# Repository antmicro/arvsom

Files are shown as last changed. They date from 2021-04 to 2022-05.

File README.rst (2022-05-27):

=========================================
ARVSOM - Antmicro RISC-V System on Module
=========================================

Copyright (c) 2021 `Antmicro <https://www.antmicro.com>`_



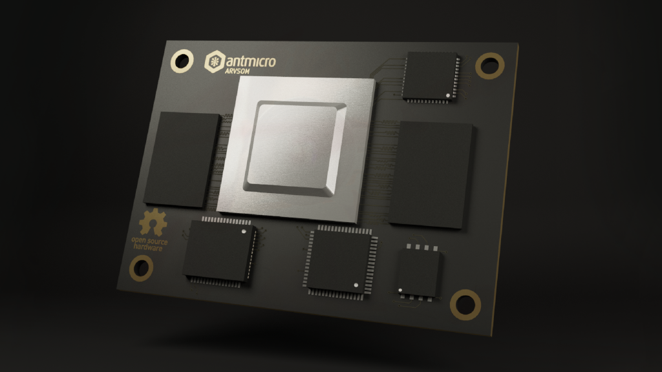
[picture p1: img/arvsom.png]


Overview
--------

This repository contains open hardware design files for ARVSOM - Antmicro RISC-V System on Module (SoM) based on the StarFive 71x0 SoC.
The design is made in KiCad and currently in progress.

Repository structure
--------------------

The main repository directory contains KiCad PCB project files, a LICENSE and README.
The remaining files are stored in the following directories:

* ``lib`` - contains the component libraries
* ``img`` - contains graphics for this README

Key Features
------------

* StarFive 71x0 SoC (7100 in the current revision until 7110 becomes available)
* 2x DF40 board-to-board connectors for baseboard integration
* HDMI
* Gigabit Ethernet
* USB 3.0
* 2x MIPI CSI-2 (2 lanes each)
* I2C
* MIPI DSI (4 lanes)
* SD/SDIO/eMMC
* 26 GPIOs
* 32MB QSPI NOR Flash memory
* 8GB LPDDR4 (2x 4GB)

License
=======

`Apache-2.0 <LICENSE>`_

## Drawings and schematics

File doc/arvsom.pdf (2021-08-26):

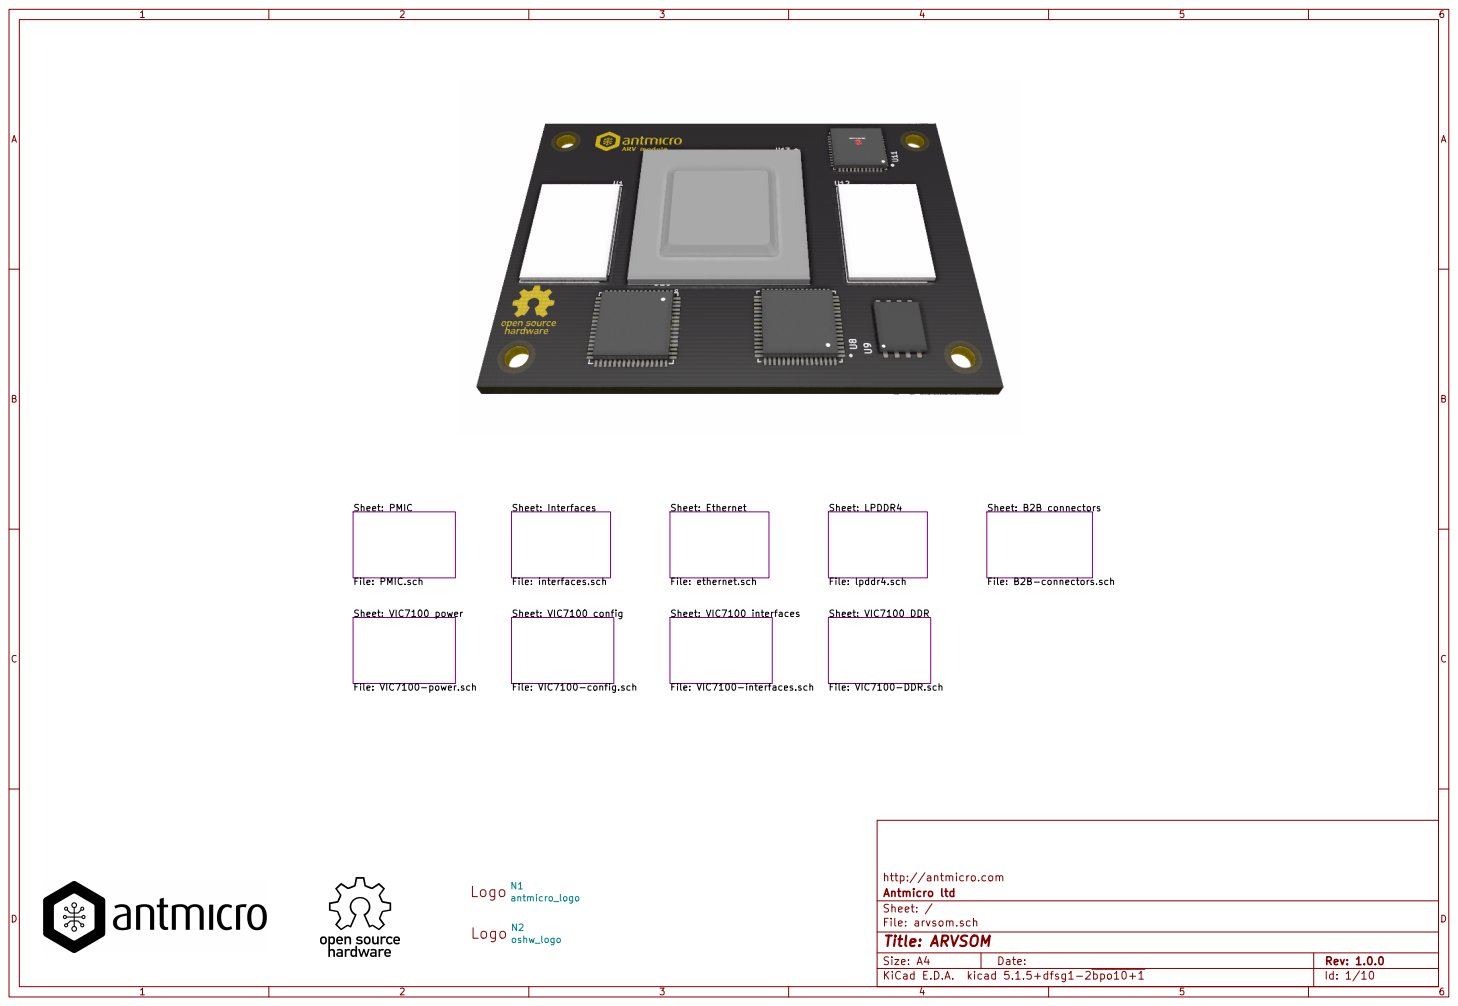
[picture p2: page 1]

http://antmicro.com
File: arvsom.sch Sheet: / Antmicro ltd

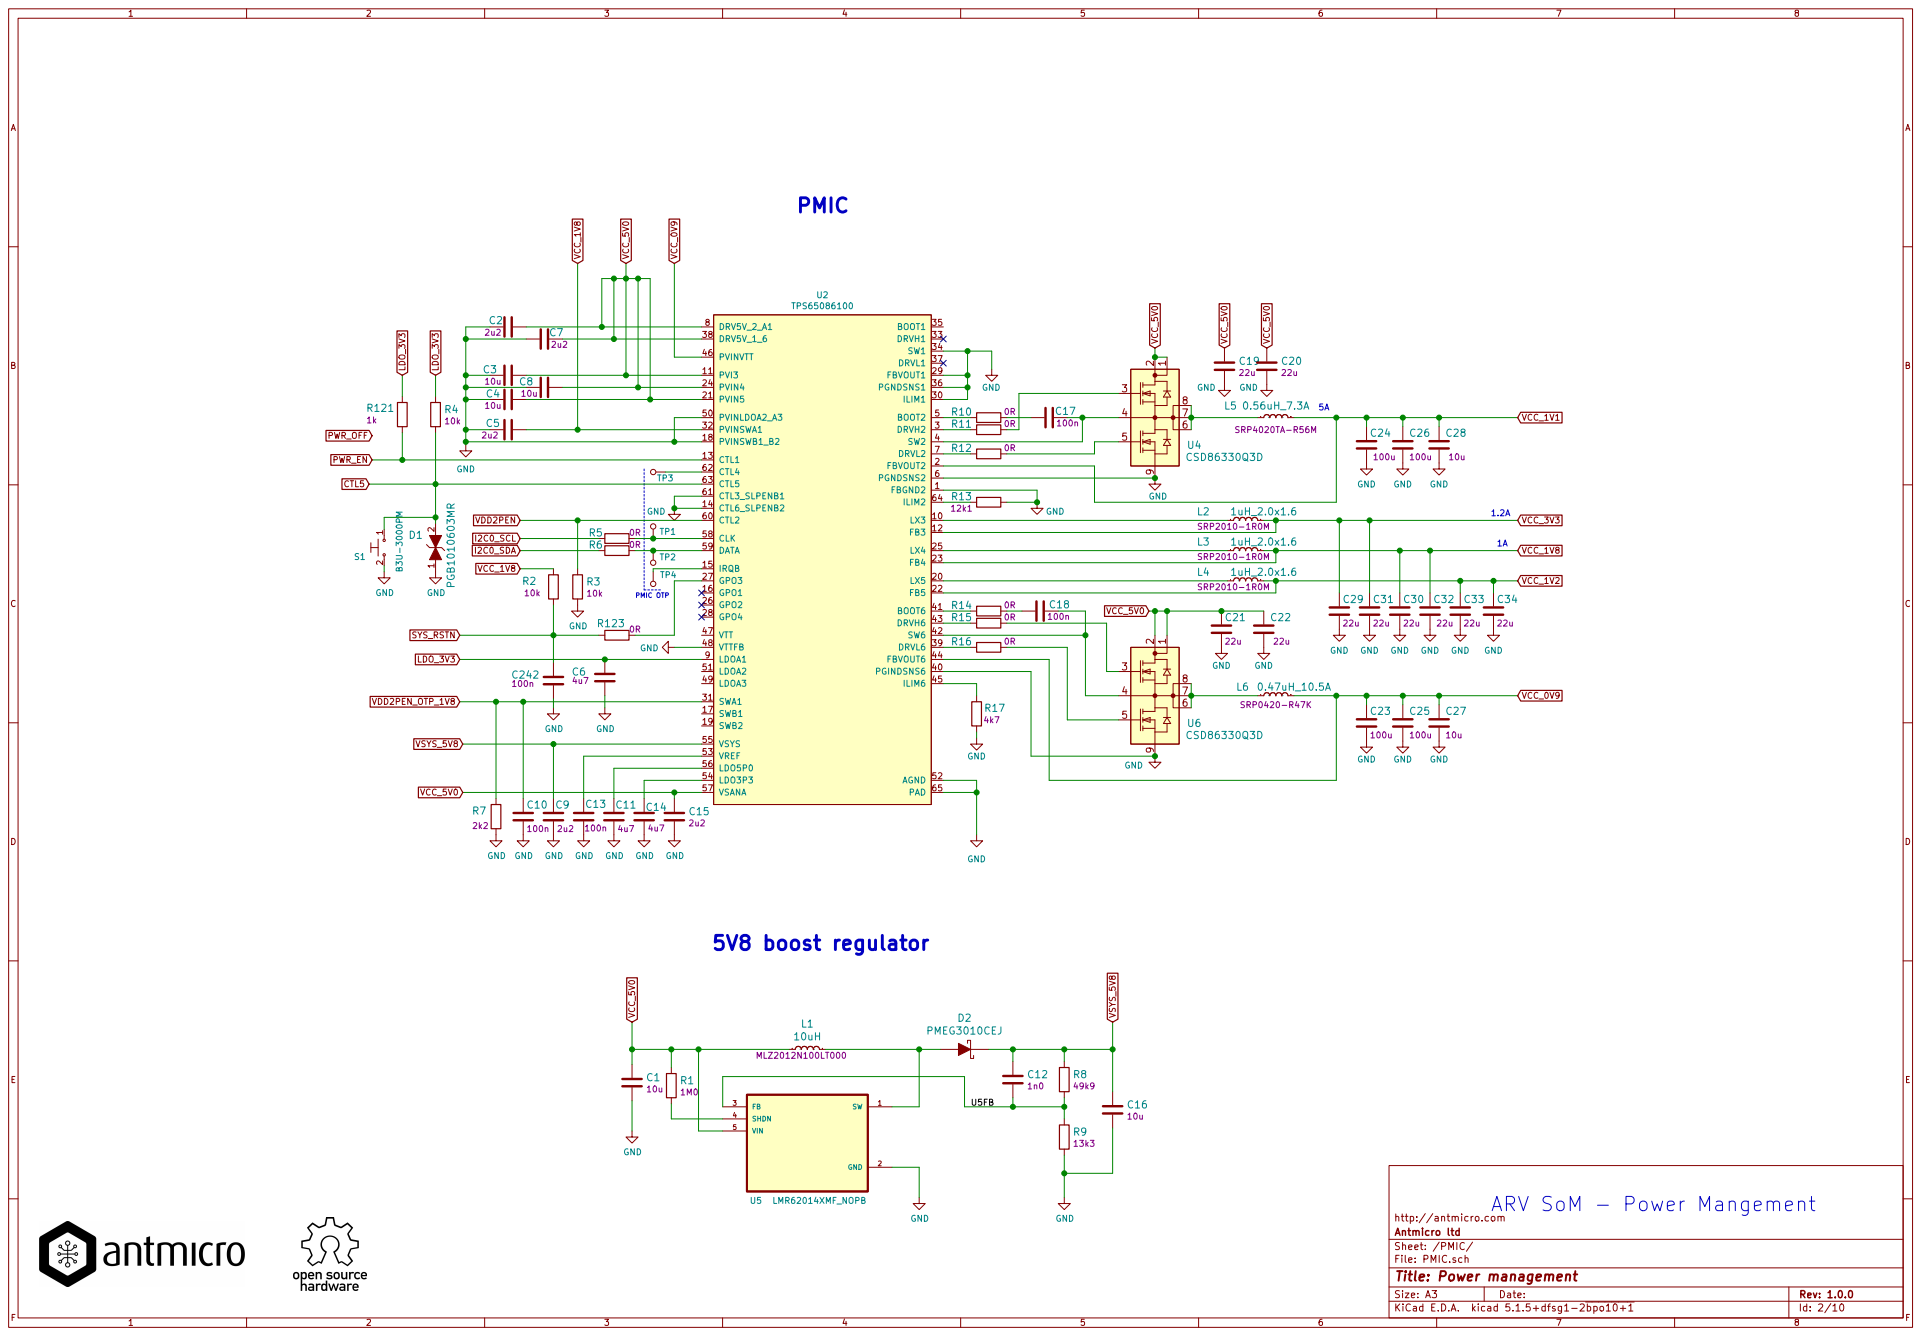
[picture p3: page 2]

10u | C8
C4 | 10u

http://antmicro.com
Id: 2/10 Title: Power management File: PMIC.sch Sheet: /PMIC/ Antmicro ltd

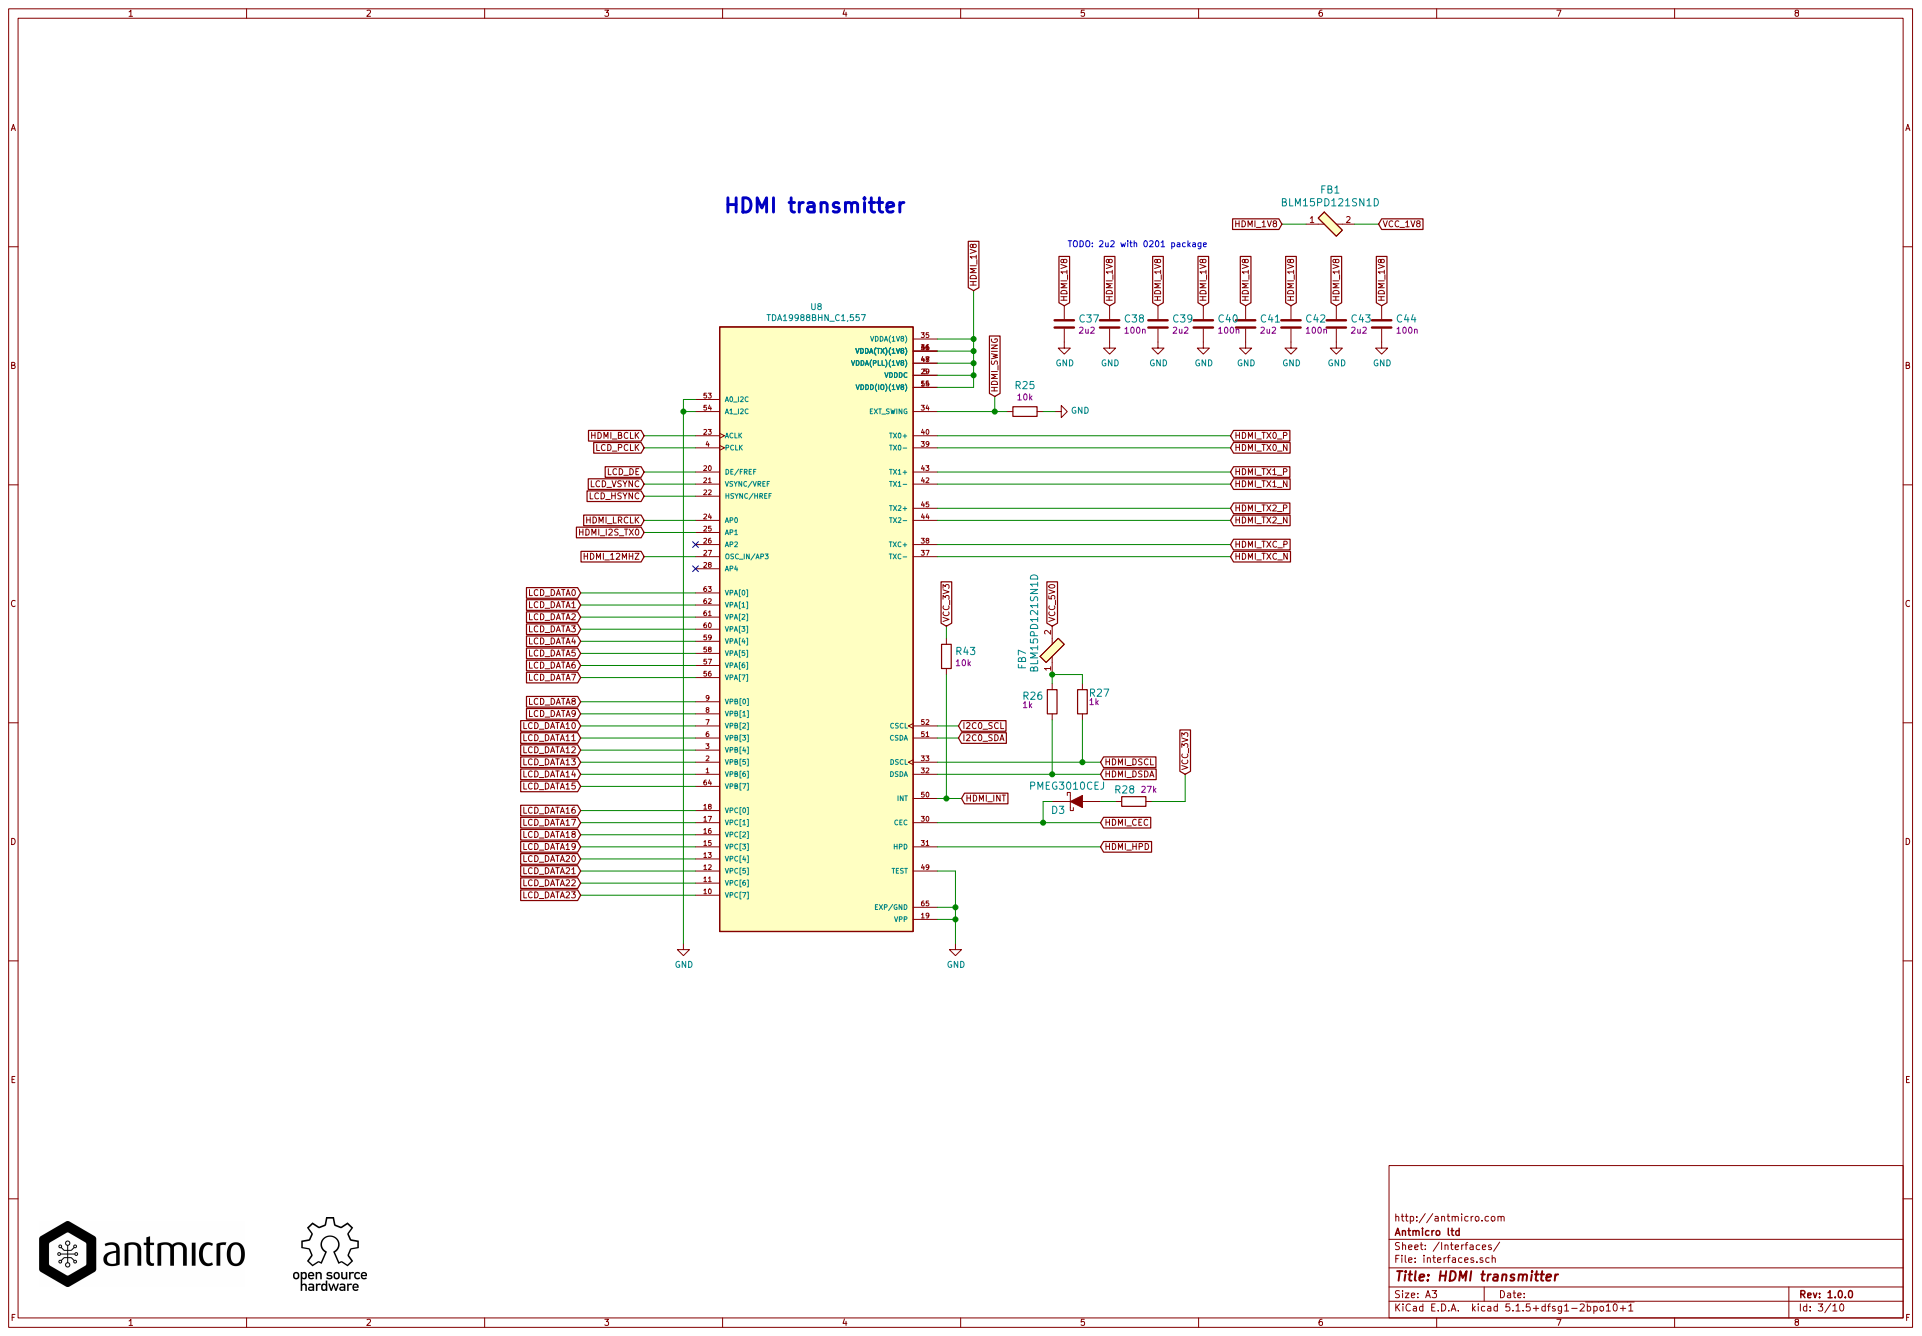
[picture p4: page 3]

http://antmicro.com
Id: 3/10 Title: HDMI transmitter File: interfaces.sch Sheet: /Interfaces/ Antmicro ltd

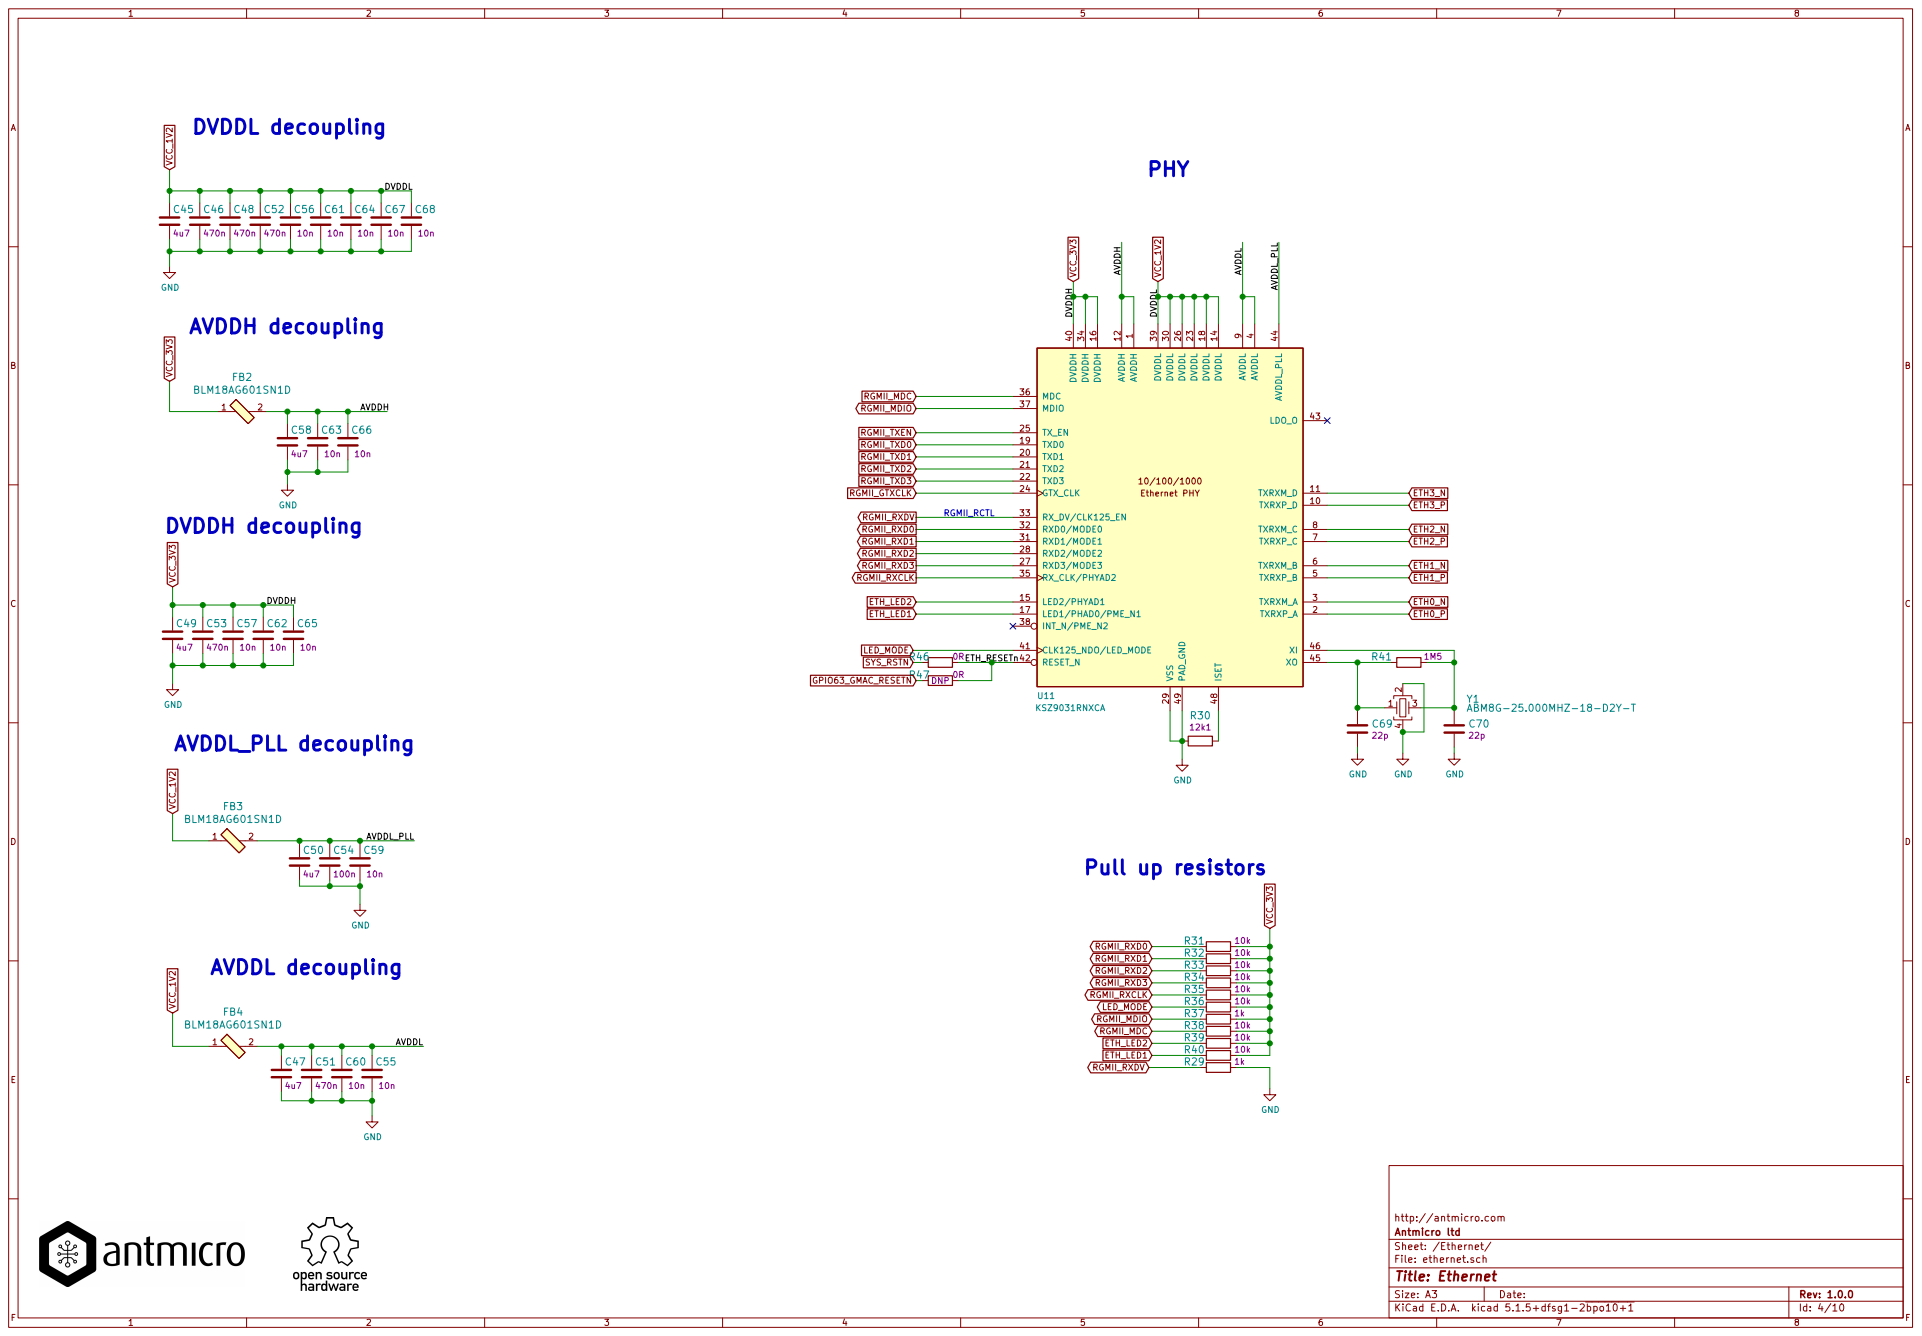
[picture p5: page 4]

http://antmicro.com
Id: 4/10 Title: Ethernet File: ethernet.sch Sheet: /Ethernet/ Antmicro ltd

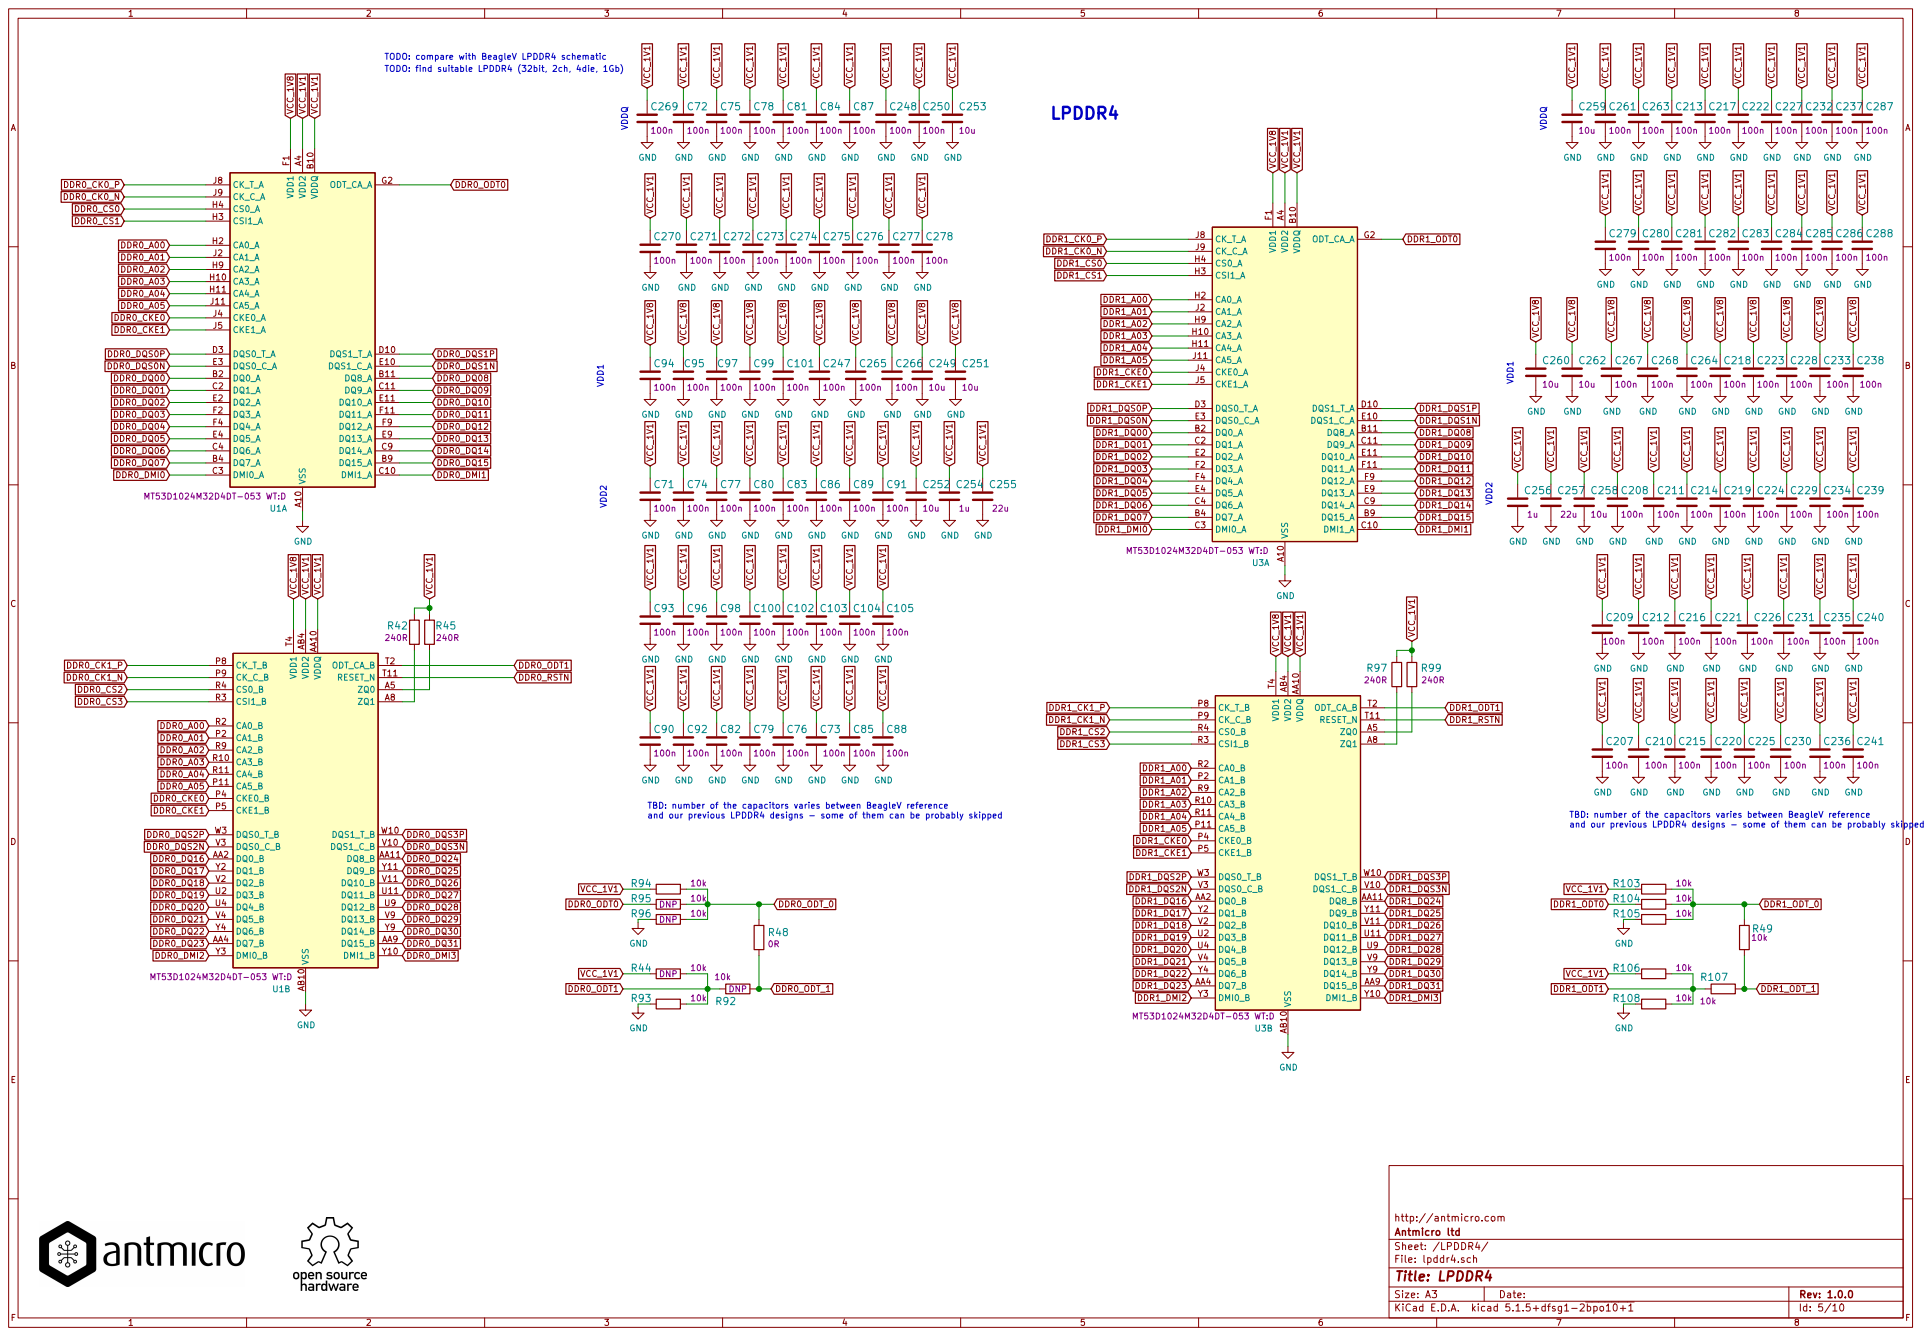
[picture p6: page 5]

TODO: compare with BeagleV LPDDR4 schematic

TBD: number of the capacitors varies between BeagleV reference

and our previous LPDDR4 designs - some of them can be probably skipped

http://antmicro.com
File: lpddr4.sch Sheet: /LPDDR4/ Antmicro ltd

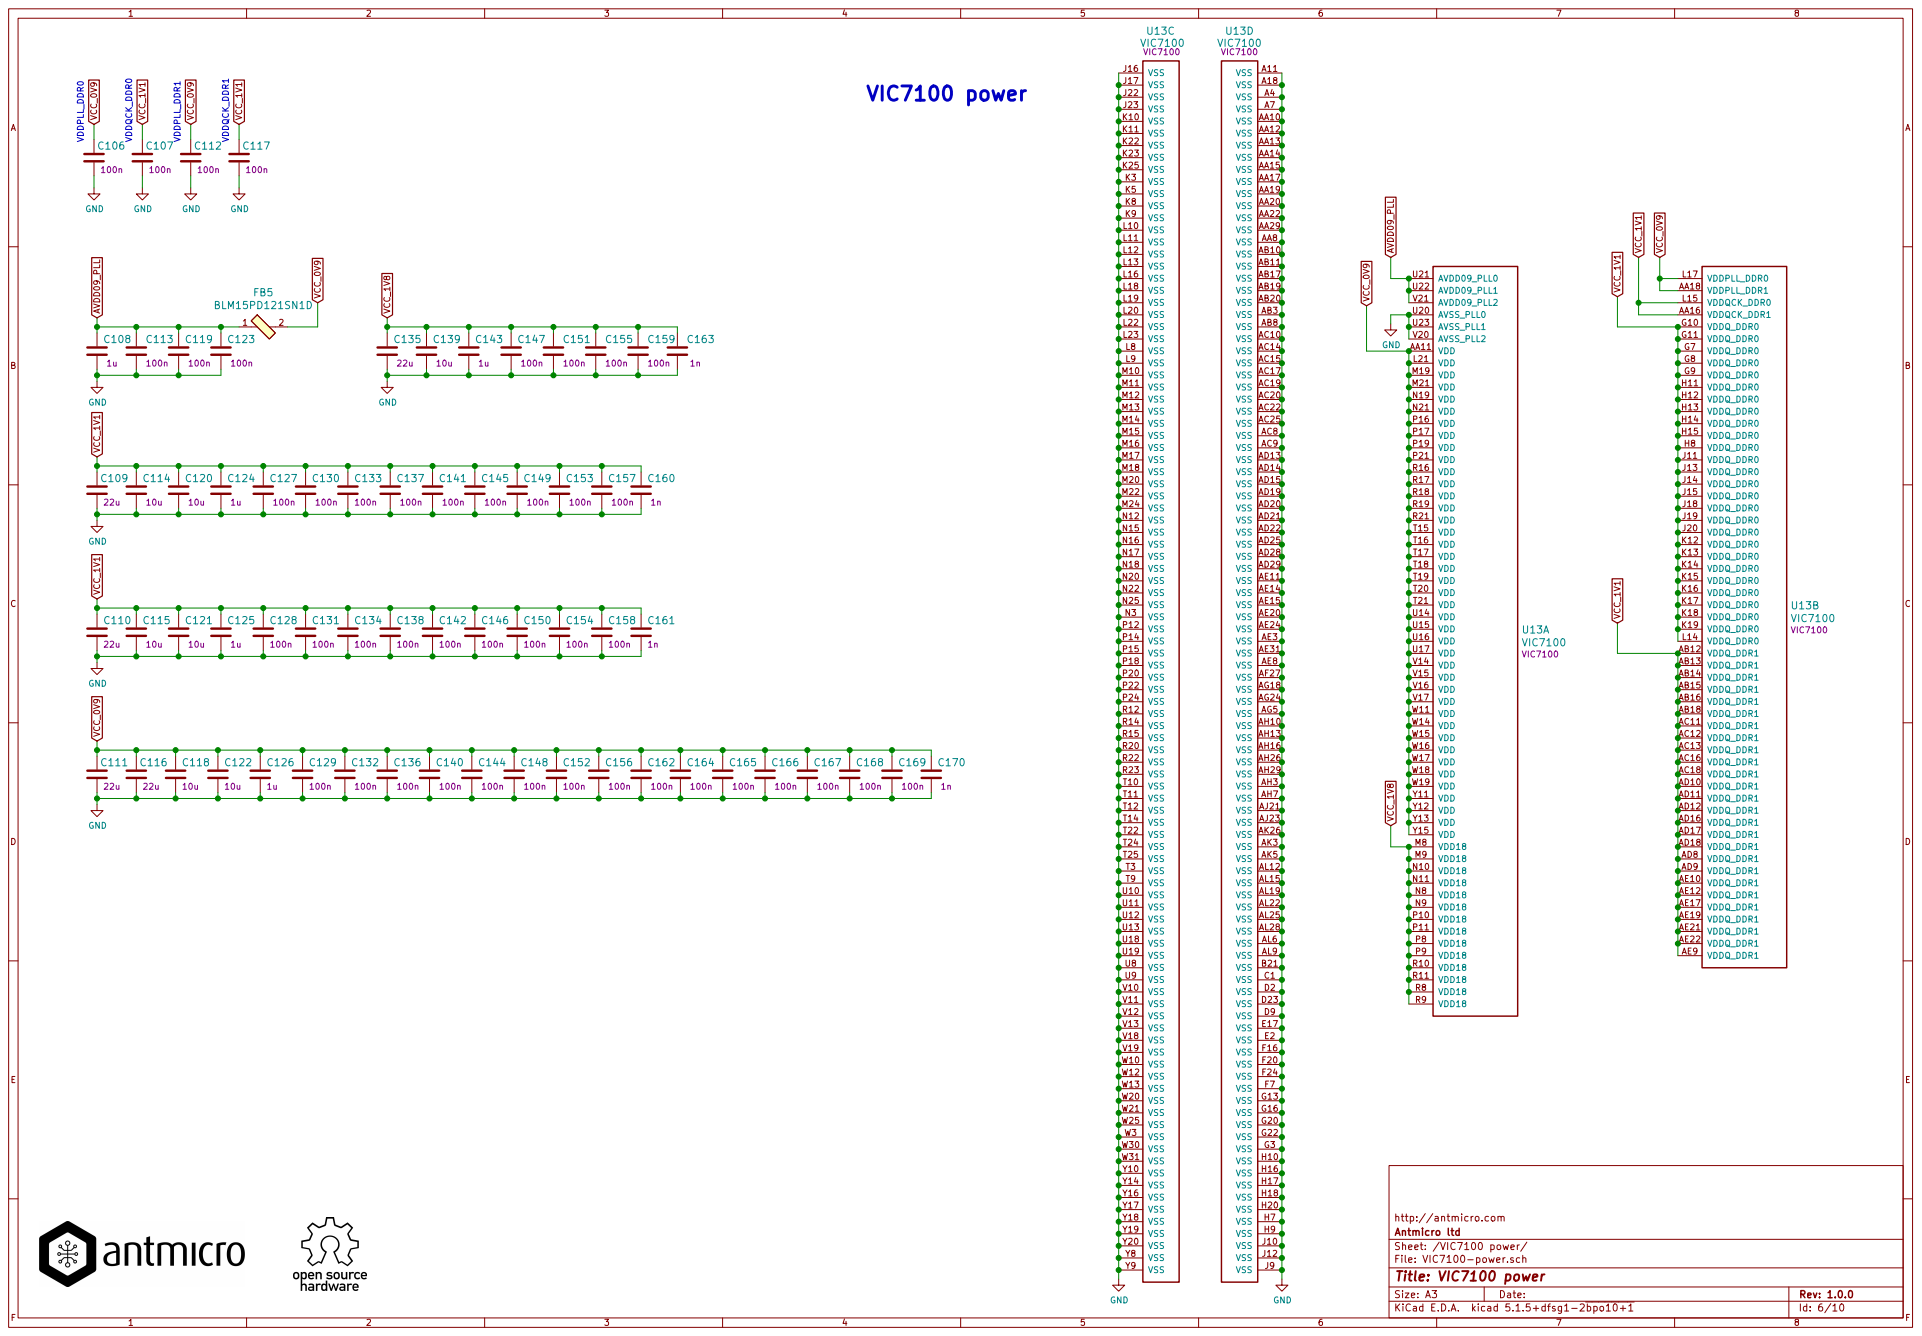
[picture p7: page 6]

http://antmicro.com
Sheet: /VIC7100 power/ Antmicro ltd

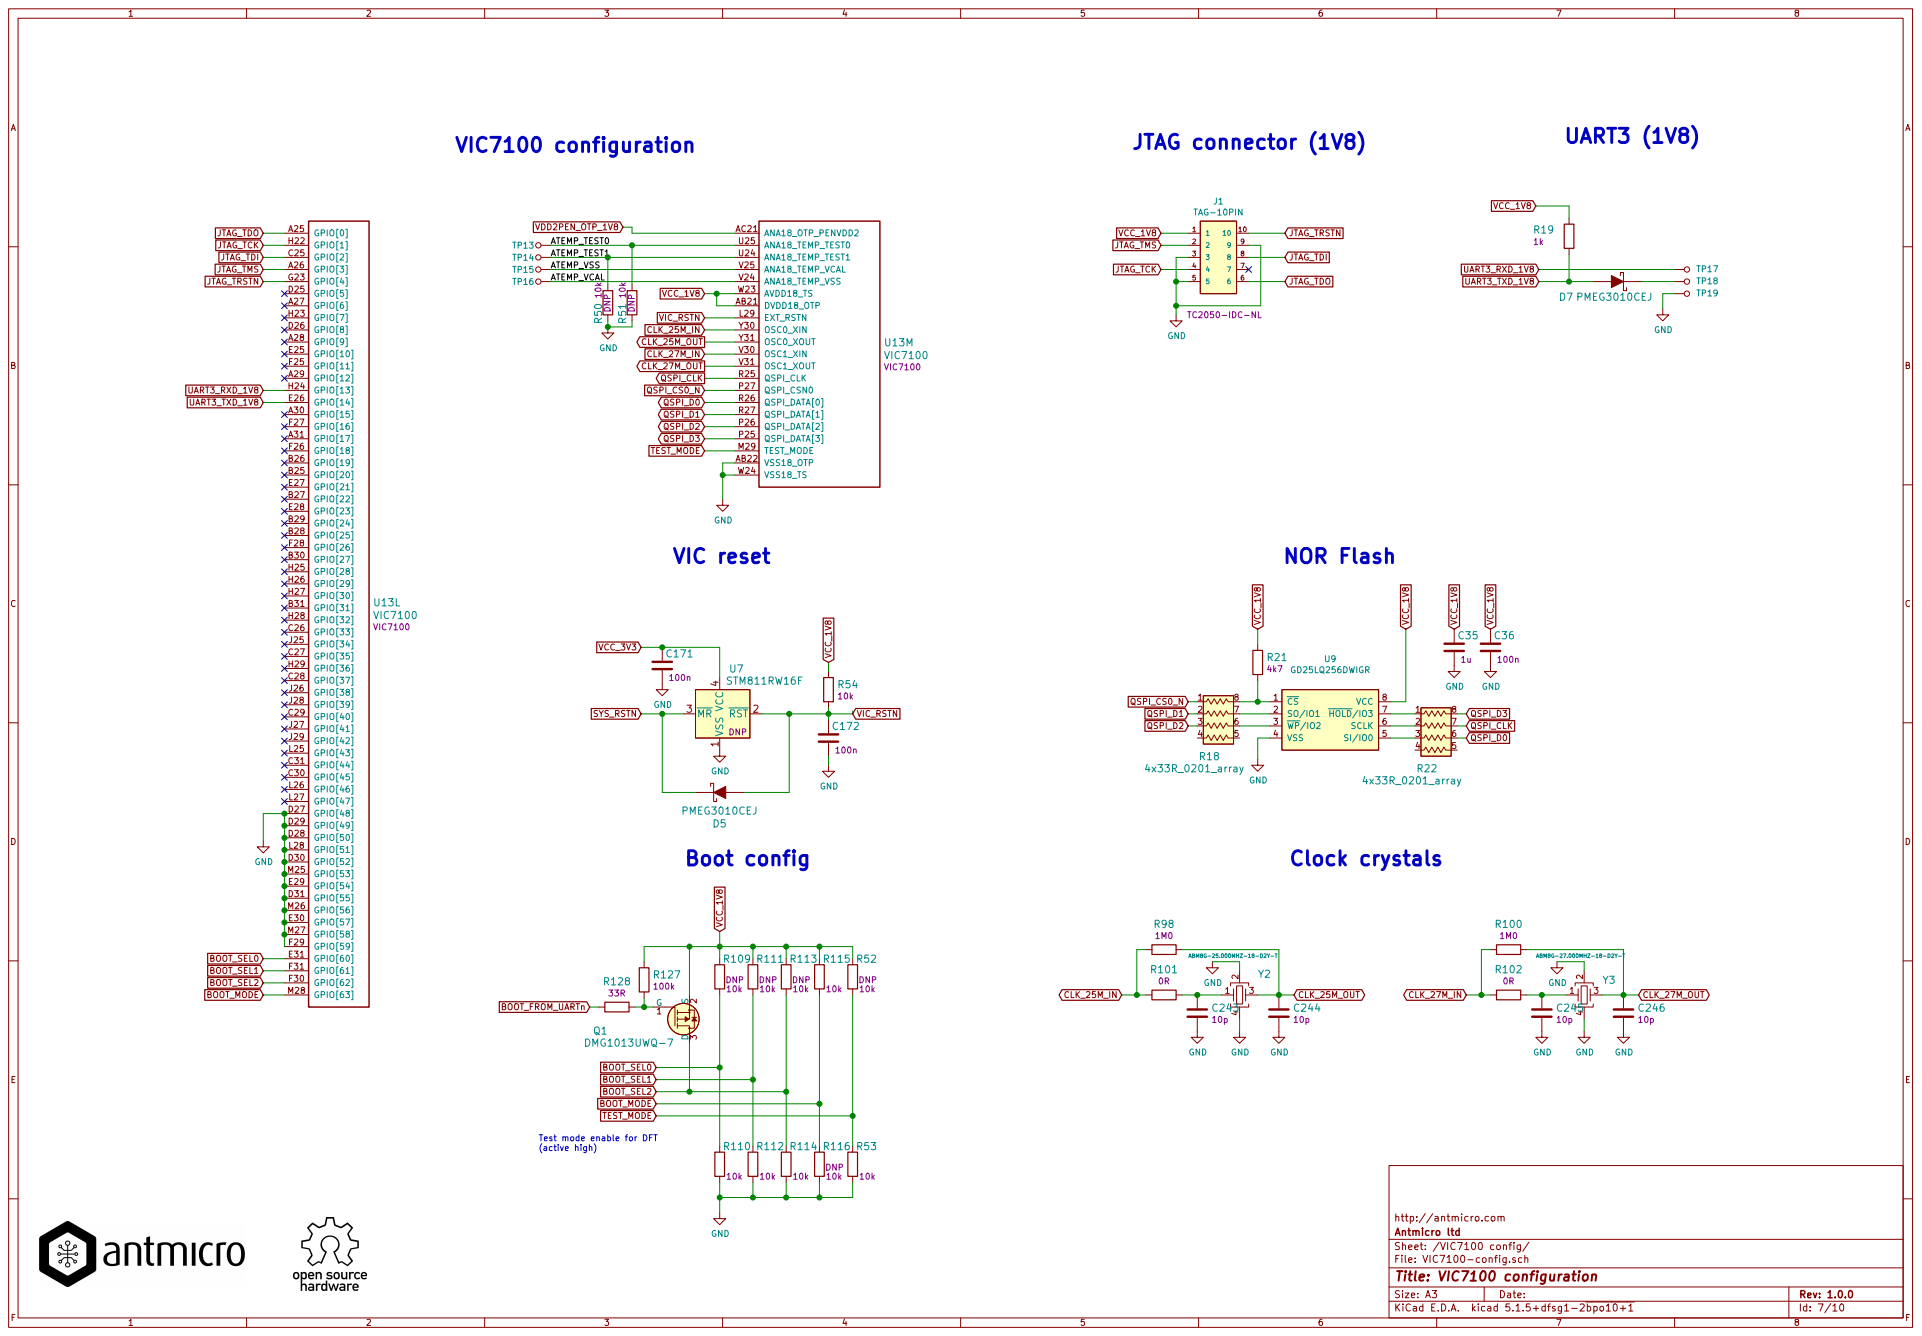
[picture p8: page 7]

Test mode enable for DFT
(active high)

http://antmicro.com
Sheet: /VIC7100 config/ Antmicro ltd

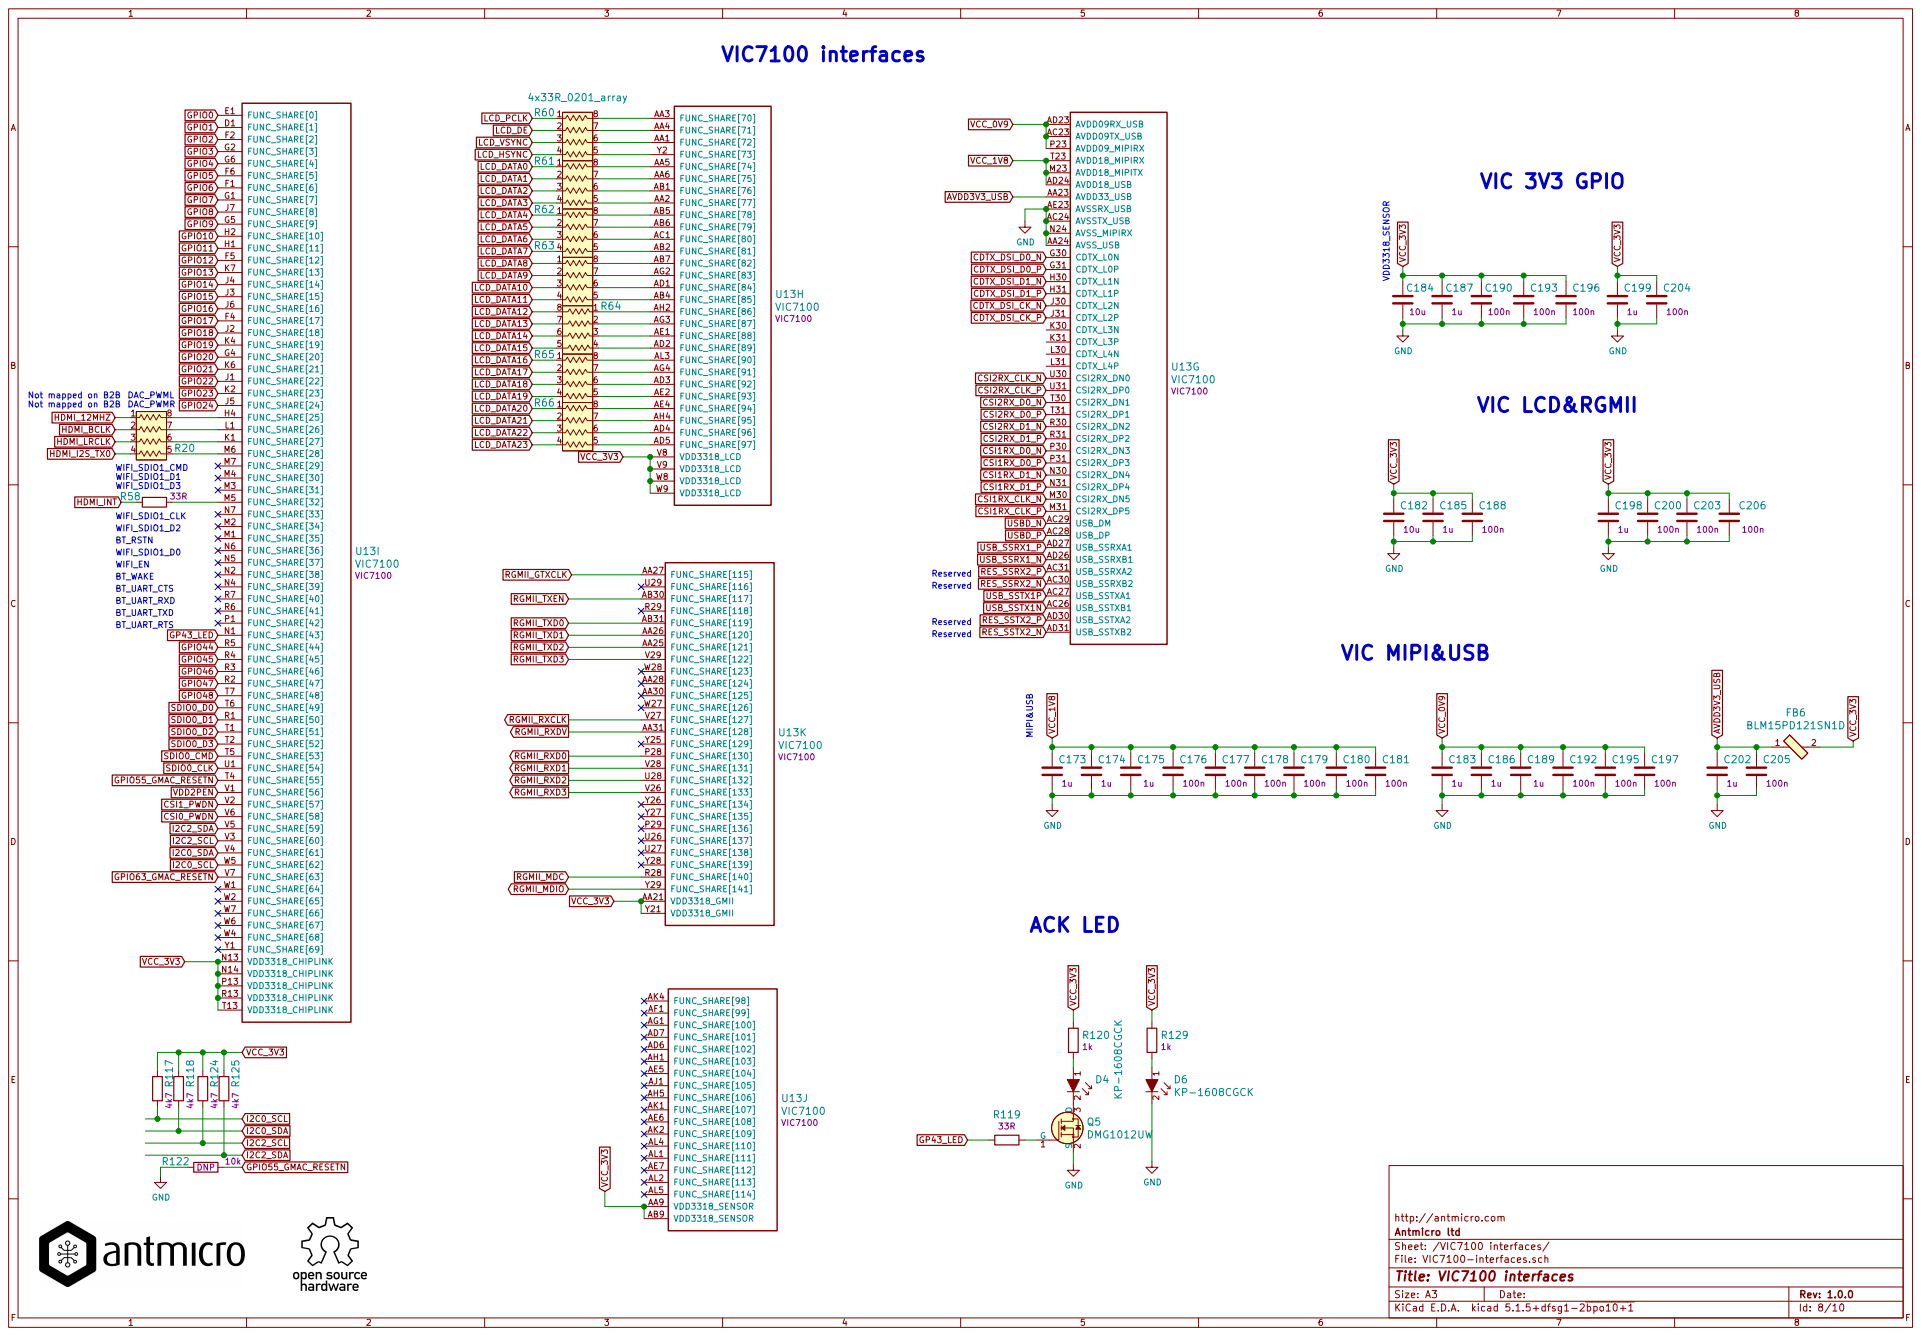
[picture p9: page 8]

http://antmicro.com
File: VIC7100-interfaces.sch Sheet: /VIC7100 interfaces/ Antmicro ltd

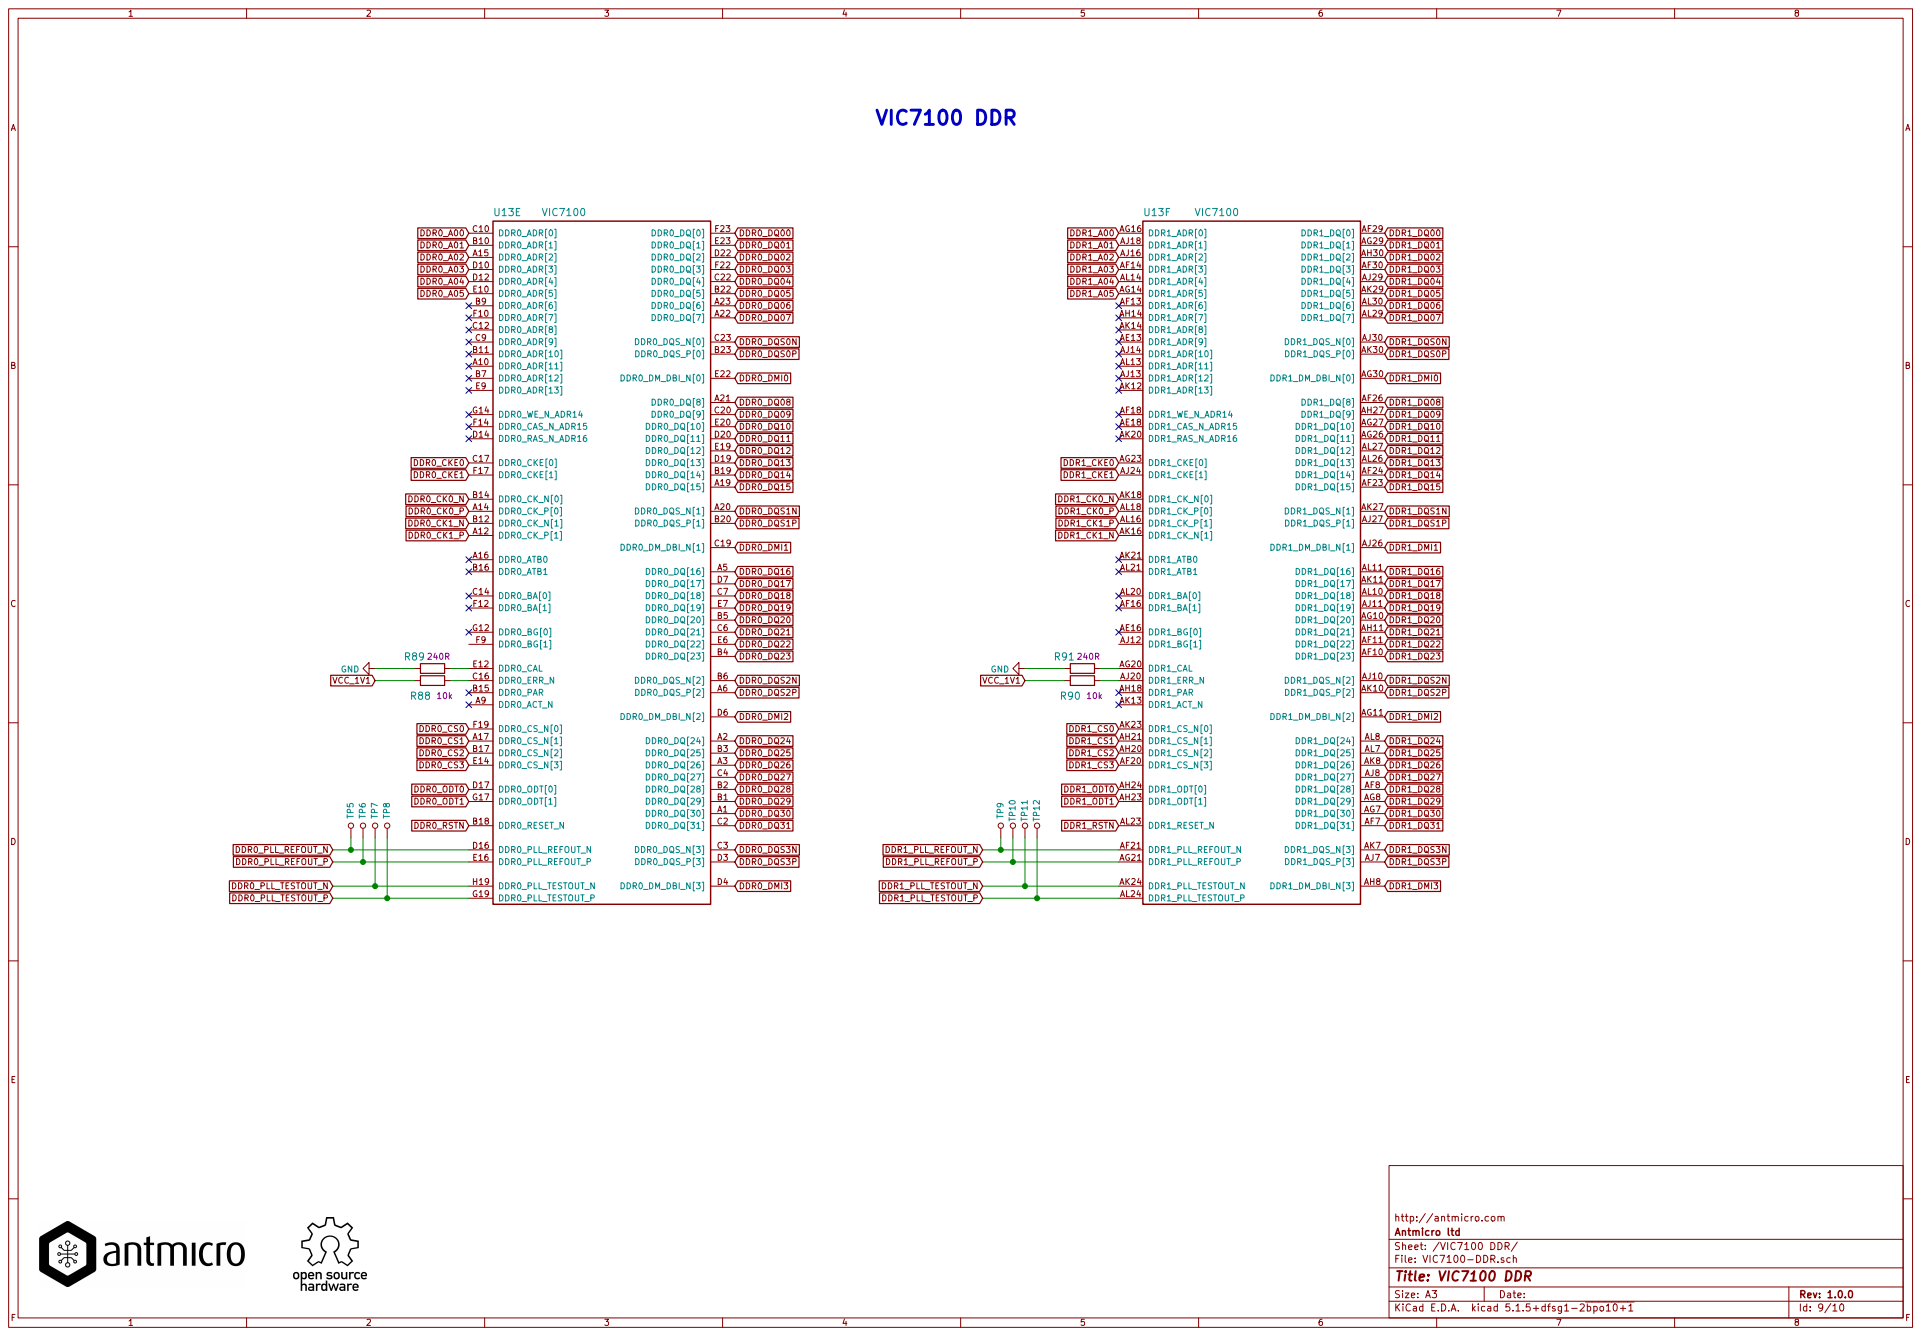
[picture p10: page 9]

File: VIC7100-DDR.sch Sheet: /VIC7100 DDR/ Antmicro ltd

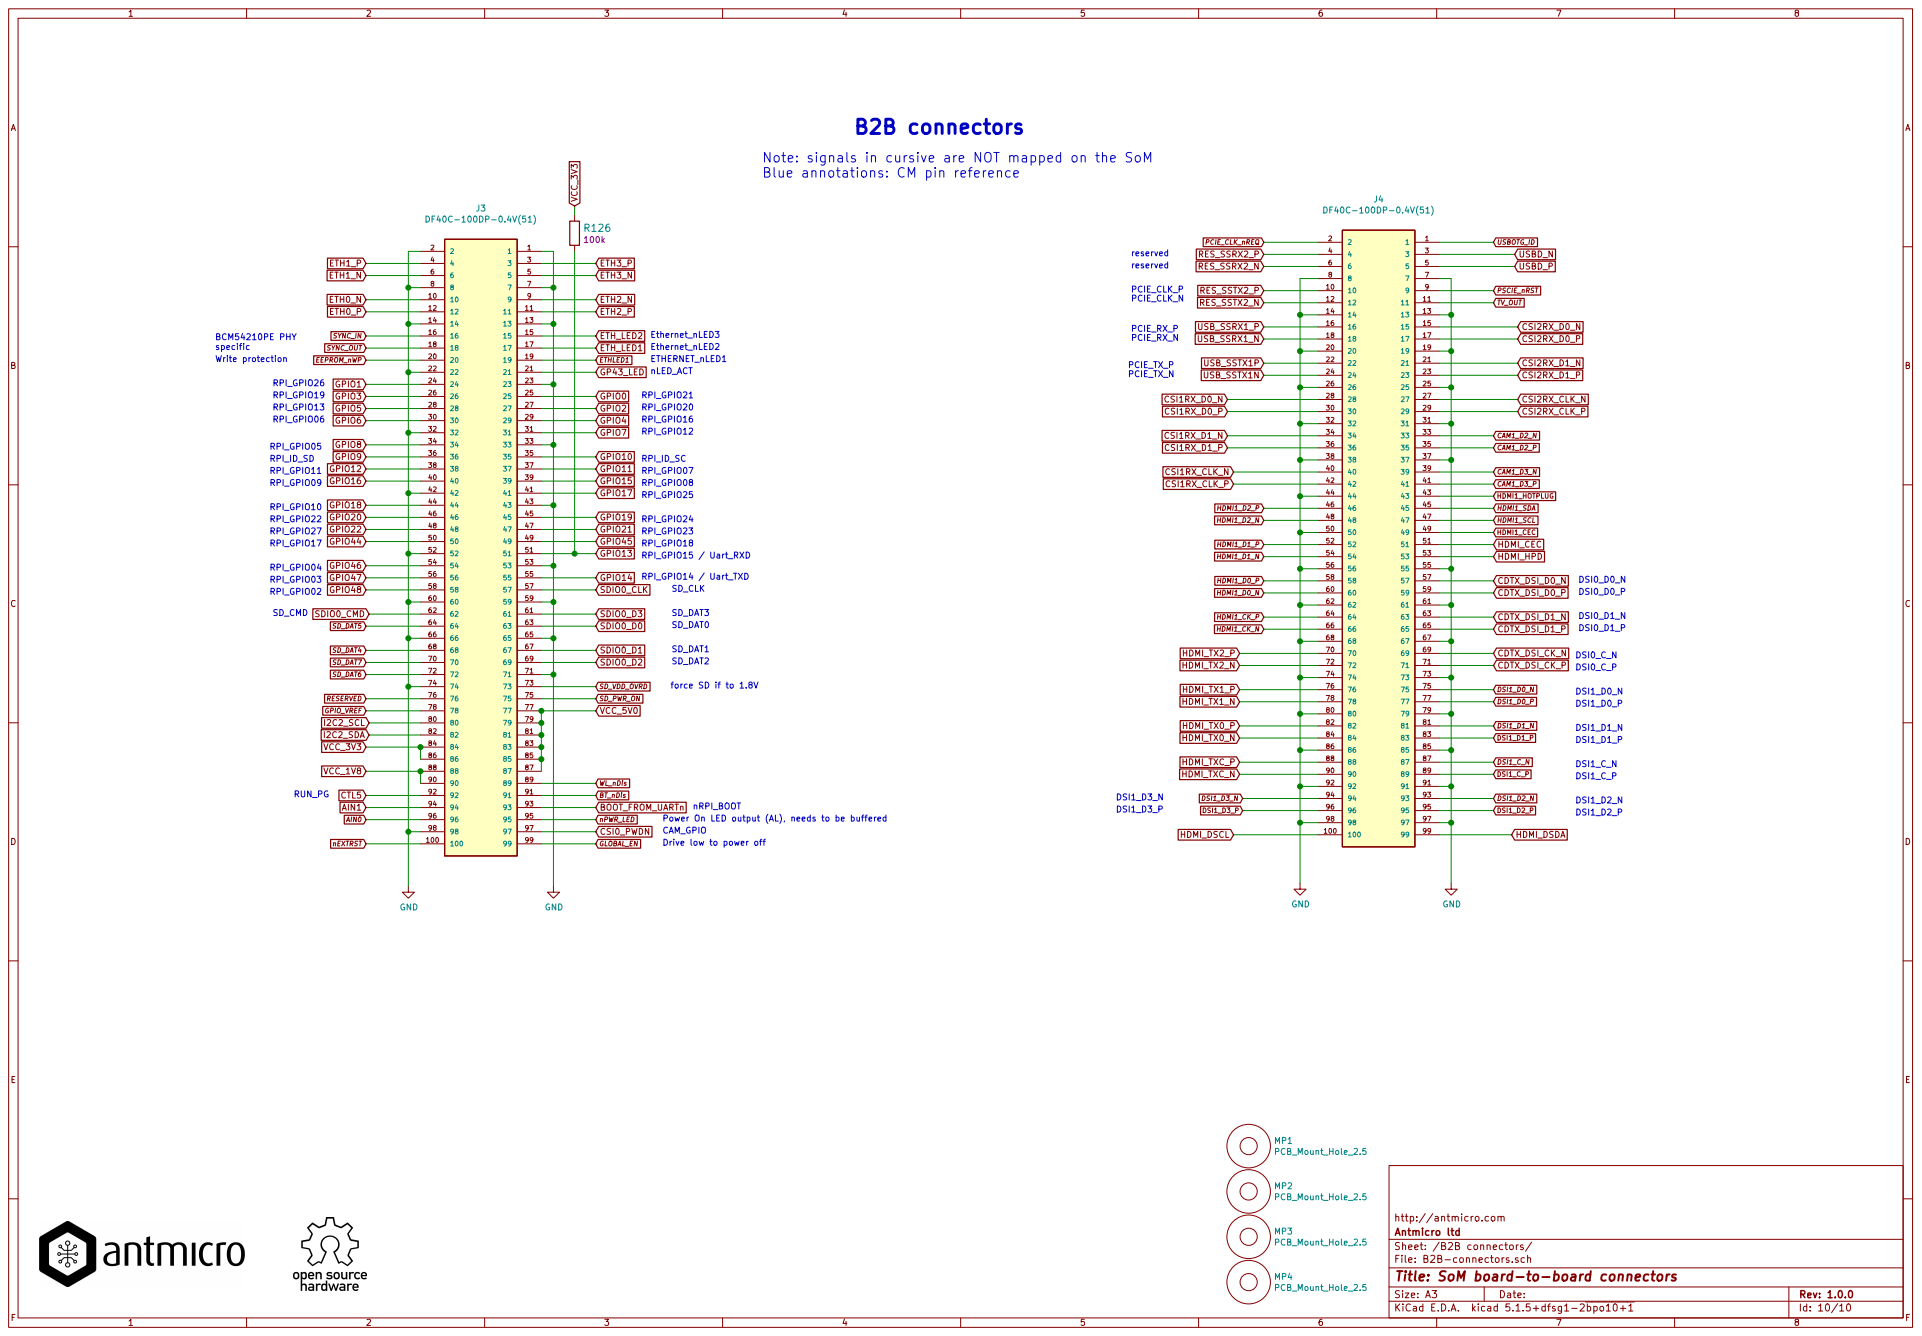
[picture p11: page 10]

Note: signals in cursive are NOT mapped on the SoM
DSI0_C_P DSI1_D0_P DSI1_D0_N Blue annotations: CM pin reference

force SD if to 1.8V

Drive low to power off RUN_PG

Power On LED output (AL), needs to be buffered
CAM_GPIO

http://antmicro.com
File: B2B-connectors.sch Sheet: /B2B connectors/ Antmicro ltd

Id: 10/10 Title: SoM board-to-board connectors

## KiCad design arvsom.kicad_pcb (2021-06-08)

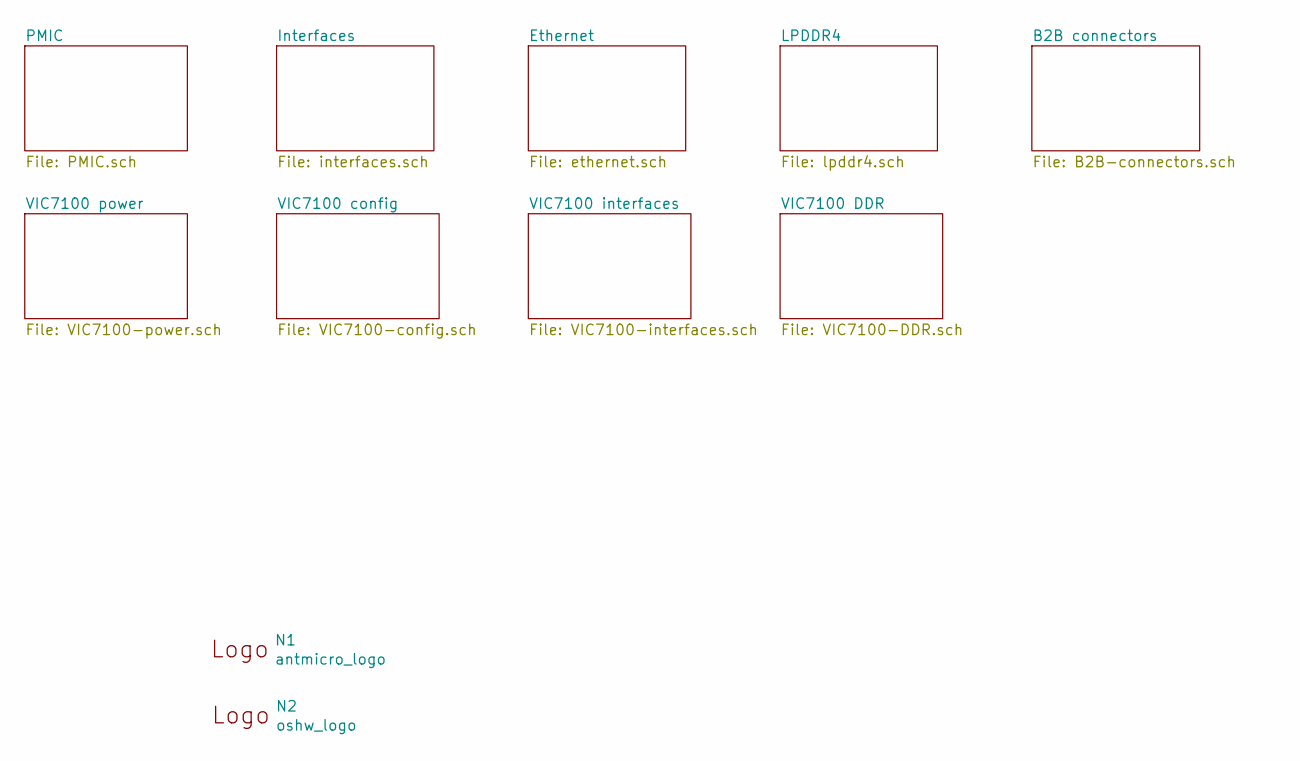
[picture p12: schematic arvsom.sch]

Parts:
N1: antmicro_logo; antmicro-logo_scaled_12mm
N2: oshw_logo; oshw-logo

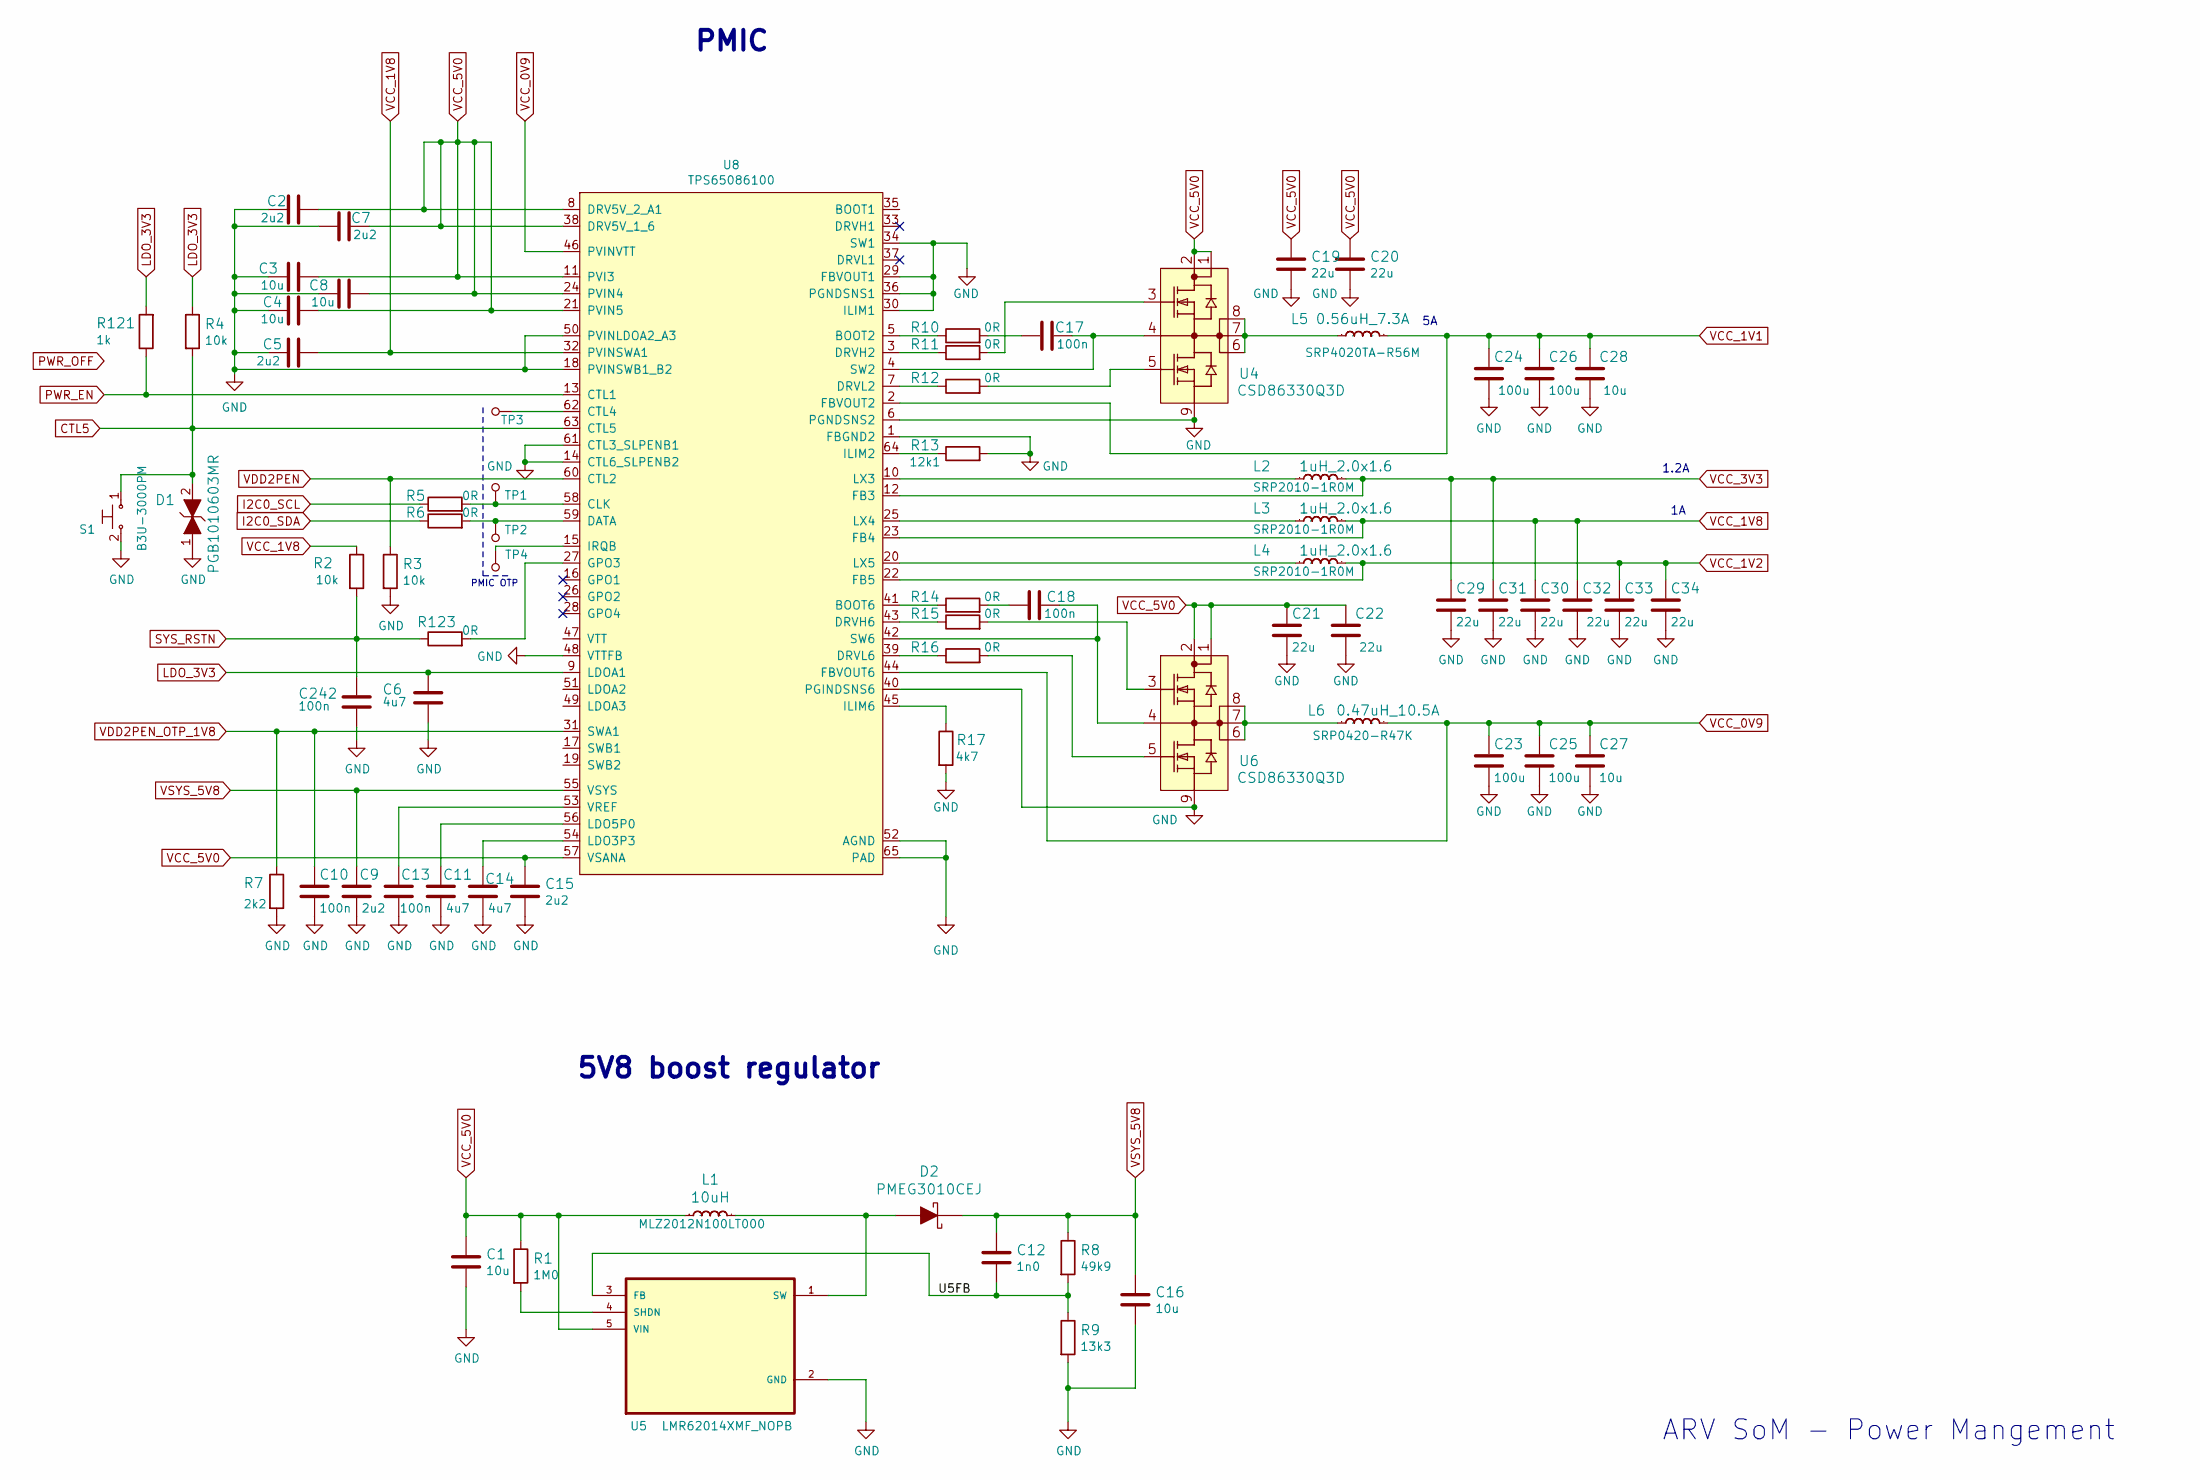
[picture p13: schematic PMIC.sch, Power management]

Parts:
C1, C16, C27, C28: C_10u_0603; 0603-cap; MPN GRM188R61A106KE69D
C2, C5, C7, C9, C15: C_2u2_0402; 0402-cap; MPN C1005X5R1A225K050BC
C3, C4, C8: C_10u_0402; 0402-cap; MPN GRM155R60J106ME44D
C6, C11, C14: C_4u7_0402; 0402-cap; MPN GRM155R61A475MEAAD
C10, C13, C17, C18, C242: C_100n_0402_16V; 0402-cap; MPN MC0402B104K160CT
C12: C_1n0_0402; 0402-cap; MPN 885012005018
C19, C20, C21, C22, C29, C30, C31, C32, C33, C34: C_22u_0603; 0603-cap; MPN GRM188R60J226MEA0D
C23, C24, C25, C26: C_100u_0805; 0805-cap; MPN GRM21BR60J107ME15L
D1: PGB1010603MR; MPN PGB1010603MR
D2: PMEG3010CEJ; SOD-323F; MPN PMEG3010CEJ
L1: 10uH; 0805-res; MPN MLZ2012N100LT000
L2, L3, L4: 1uH_2.0x1.6; INDC2016X100N; MPN SRP2010-1R0M
L5: 0.56uH_7.3A; SRP4020; MPN SRP4020TA-R56M
L6: 0.47uH_10.5A; SRP4020; MPN SRP0420-R47K
R1: R_1M0_0402; 0402-res; MPN CRG0402F1M0
R2, R3, R4: R_10k_0402; 0402-res; MPN CRCW040210K0FKEDHP
R5, R6, R10, R11, R12, R14, R15, R16, R123: R_0R_0201; 0201-res; MPN CRCW02010000Z0ED
R7: R_2k2_0402; 0402-res; MPN RC0402FR-072K2L
R8: R_49k9_0402; 0402-res; MPN CRCW040249K9FKED
R9: R_13k3_0402; 0402-res; MPN ERJ2RKF1332X
R13: R_12k1_0402; 0402-res; MPN MCWR04X1212FTL
R17: R_4k7_0402; 0402-res; MPN ERJ2GEJ472X
R121: R_1k_0402; 0402-res; MPN CR0402-FX-1001GLF
S1: B3U-3000PM; B3U-3000P; MPN B3U-3000PM
TP1, TP2, TP3, TP4: TP_SMD1MM; Testpoint_smd_1mm
U4, U6: CSD86330Q3D; MPN CSD86330Q3D
U5: LMR62014XMF_NOPB; SOT95P280X145-5N; MPN LMR62014XMF
U8: TPS65086100; S-PVQFN-N64

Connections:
/PMIC/U5FB: C12.2, R8.2, R9.1, U5.3 (FB)
CTL5: D1.2, R4.2, S1.1, U8.63 (CTL5); also elsewhere on the board
GND: C1.2, C2.1, C3.2, C4.2, C5.1, C6.2, C7.1, C8.2, C9.2, C10.2, C11.2, C13.1, C14.1, C15.2, C16.2, C19.2, C20.2, C21.2, C22.2, C23.2, C24.2, C25.2, C26.2, C27.2, C28.2, C29.2, C30.2, C31.2, C32.2, C33.2, C34.2, C242.2, D1.1, R3.2, R7.2, R9.2, R13.2, R17.2, S1.2, U4.9 (PGND), U5.2 (GND), U6.9 (PGND), U8.1 (FBGND2), U8.6 (PGNDSNS2), U8.14 (CTL6_SLPENB2), U8.18 (PVINSWB1_B2), U8.29 (FBVOUT1), U8.30 (ILIM1), U8.34 (SW1), U8.36 (PGNDSNS1), U8.40 (PGINDSNS6), U8.48 (VTTFB), U8.50 (PVINLDOA2_A3), U8.52 (AGND), U8.61 (CTL3_SLPENB1), U8.65 (PAD); also elsewhere on the board
I2C0_SCL: R5.1; also elsewhere on the board
I2C0_SDA: R6.1; also elsewhere on the board
LDO_3V3: C6.1, R4.1, R121.2, U8.9 (LDOA1)
unnamed: C11.1, U8.56 (LDO5P0)
unnamed: C13.2, U8.53 (VREF)
unnamed: C14.2, U8.54 (LDO3P3)
unnamed: C17.1, R10.2
unnamed: C17.2, U4.4 (TGR), U8.4 (SW2)
unnamed: C18.1, R14.2
unnamed: C18.2, U6.4 (TGR), U8.42 (SW6)
unnamed: D2.A, L1.2, U5.1 (SW)
unnamed: L2.1, U8.10 (LX3)
unnamed: L3.1, U8.25 (LX4)
unnamed: L4.1, U8.20 (LX5)
unnamed: L5.1, U4.6 (VSW), U4.7 (VSW), U4.8 (VSW)
unnamed: L6.1, U6.6 (VSW), U6.7 (VSW), U6.8 (VSW)
unnamed: R1.2, U5.4 (SHDN)
unnamed: R5.2, TP1.1, U8.58 (CLK)
unnamed: R6.2, TP2.1, U8.59 (DATA)
unnamed: R10.1, U8.5 (BOOT2)
unnamed: R11.1, U8.3 (DRVH2)
unnamed: R11.2, U4.3 (TG)
unnamed: R12.1, U8.7 (DRVL2)
unnamed: R12.2, U4.5 (BG)
unnamed: R13.1, U8.64 (ILIM2)
unnamed: R14.1, U8.41 (BOOT6)
unnamed: R15.1, U8.43 (DRVH6)
unnamed: R15.2, U6.3 (TG)
unnamed: R16.1, U8.39 (DRVL6)
unnamed: R16.2, U6.5 (BG)
unnamed: R17.1, U8.45 (ILIM6)
unnamed: R123.2, U8.27 (GPO3)
unnamed: TP3.1, U8.62 (CTL4)
unnamed: TP4.1, U8.15 (IRQB)
PWR_EN: R121.1, U8.13 (CTL1)
SYS_RSTN: C242.1, R2.2, R123.1; also elsewhere on the board
VCC_0V9: C23.1, C25.1, C27.1, L6.2, U8.44 (FBVOUT6), U8.46 (PVINVTT); also elsewhere on the board
VCC_1V1: C24.1, C26.1, C28.1, L5.2, U8.2 (FBVOUT2); also elsewhere on the board
VCC_1V2: C33.1, C34.1, L4.2, U8.22 (FB5); also elsewhere on the board
VCC_1V8: C5.2, C30.1, C32.1, L3.2, R2.1, U8.23 (FB4), U8.32 (PVINSWA1); also elsewhere on the board
VCC_3V3: C29.1, C31.1, L2.2, U8.12 (FB3); also elsewhere on the board
VCC_5V0: C1.1, C2.2, C3.1, C4.1, C7.2, C8.1, C15.1, C19.1, C20.1, C21.1, C22.1, L1.1, R1.1, U4.1 (VIN), U4.2 (VIN), U5.5 (VIN), U6.1 (VIN), U6.2 (VIN), U8.8 (DRV5V_2_A1), U8.11 (PVI3), U8.21 (PVIN5), U8.24 (PVIN4), U8.38 (DRV5V_1_6), U8.57 (VSANA); also elsewhere on the board
VDD2PEN: R3.1, U8.60 (CTL2); also elsewhere on the board
VDD2PEN_OTP_1V8: C10.1, R7.1, U8.31 (SWA1); also elsewhere on the board
VSYS_5V8: C9.1, C12.1, C16.1, D2.K, R8.1, U8.55 (VSYS)

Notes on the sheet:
1.2A
PMIC
5V8 boost regulator
PMIC OTP
ARV SoM - Power Mangement

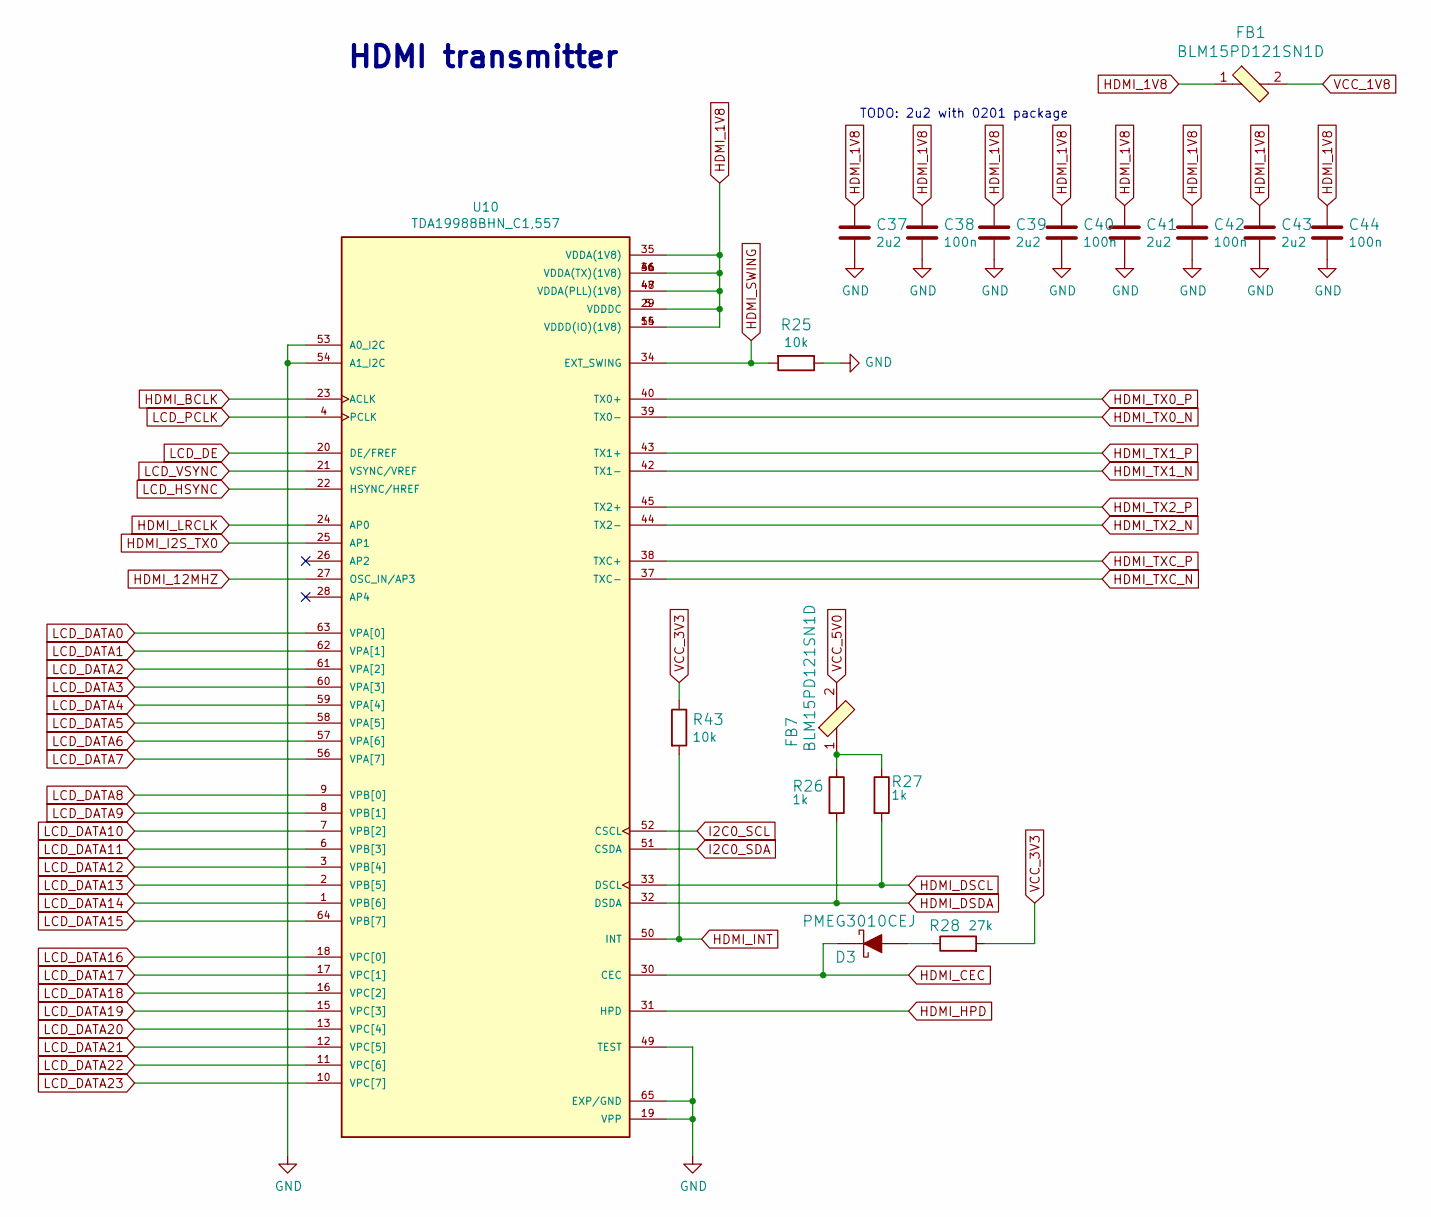
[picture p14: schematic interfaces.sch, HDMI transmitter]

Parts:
C37, C39, C41, C43: C_2u2_0402; 0402-cap; MPN C1005X5R1A225K050BC
C38, C40, C42, C44: C_100n_0201; 0201-res; MPN CC0201KRX6S5BB104
D3: PMEG3010CEJ; SOD-323F; MPN PMEG3010CEJ
FB1, FB7: BLM15PD121SN1D; 0402-res; MPN BLM15PD121SN1D
R25, R43: R_10k_0201; 0201-res; MPN RC0201FR-0710KL
R26, R27: R_1k_0402; 0402-res; MPN CR0402-FX-1001GLF
R28: R_27k_0402; 0402-res; MPN ERJ2RKF2702X
U10: TDA19988BHN_C1,557; QFN50P900X900X100-65N; PARTREV 3

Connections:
GND: C37.2, C38.2, C39.2, C40.2, C41.2, C42.2, C43.2, C44.2, R25.1, U10.19 (VPP), U10.49 (TEST), U10.53 (A0_I2C), U10.54 (A1_I2C), U10.65 (EXP/GND); also elsewhere on the board
HDMI_1V8: C37.1, C38.1, C39.1, C40.1, C41.1, C42.1, C43.1, C44.1, FB1.1, U10.5 (VDDDC), U10.14 (VDDD(IO)(1V8)), U10.29 (VDDDC), U10.35 (VDDA(1V8)), U10.36 (VDDA(TX)(1V8)), U10.41 (VDDA(TX)(1V8)), U10.46 (VDDA(TX)(1V8)), U10.47 (VDDA(PLL)(1V8)), U10.48 (VDDA(PLL)(1V8)), U10.55 (VDDD(IO)(1V8))
HDMI_12MHZ: U10.27 (OSC_IN/AP3); also elsewhere on the board
HDMI_BCLK: U10.23 (ACLK); also elsewhere on the board
HDMI_CEC: D3.K, U10.30 (CEC); also elsewhere on the board
HDMI_DSCL: R27.2, U10.33 (DSCL); also elsewhere on the board
HDMI_DSDA: R26.2, U10.32 (DSDA); also elsewhere on the board
HDMI_HPD: U10.31 (HPD); also elsewhere on the board
HDMI_I2S_TX0: U10.25 (AP1); also elsewhere on the board
HDMI_INT: R43.2, U10.50 (INT); also elsewhere on the board
HDMI_LRCLK: U10.24 (AP0); also elsewhere on the board
HDMI_SWING: R25.2, U10.34 (EXT_SWING)
HDMI_TX0_N: U10.39 (TX0-); also elsewhere on the board
HDMI_TX0_P: U10.40 (TX0+); also elsewhere on the board
HDMI_TX1_N: U10.42 (TX1-); also elsewhere on the board
HDMI_TX1_P: U10.43 (TX1+); also elsewhere on the board
HDMI_TX2_N: U10.44 (TX2-); also elsewhere on the board
HDMI_TX2_P: U10.45 (TX2+); also elsewhere on the board
HDMI_TXC_N: U10.37 (TXC-); also elsewhere on the board
HDMI_TXC_P: U10.38 (TXC+); also elsewhere on the board
I2C0_SCL: U10.52 (CSCL); also elsewhere on the board
I2C0_SDA: U10.51 (CSDA); also elsewhere on the board
LCD_DATA0: U10.63 (VPA[0]); also elsewhere on the board
LCD_DATA1: U10.62 (VPA[1]); also elsewhere on the board
LCD_DATA2: U10.61 (VPA[2]); also elsewhere on the board
LCD_DATA3: U10.60 (VPA[3]); also elsewhere on the board
LCD_DATA4: U10.59 (VPA[4]); also elsewhere on the board
LCD_DATA5: U10.58 (VPA[5]); also elsewhere on the board
LCD_DATA6: U10.57 (VPA[6]); also elsewhere on the board
LCD_DATA7: U10.56 (VPA[7]); also elsewhere on the board
LCD_DATA8: U10.9 (VPB[0]); also elsewhere on the board
LCD_DATA9: U10.8 (VPB[1]); also elsewhere on the board
LCD_DATA10: U10.7 (VPB[2]); also elsewhere on the board
LCD_DATA11: U10.6 (VPB[3]); also elsewhere on the board
LCD_DATA12: U10.3 (VPB[4]); also elsewhere on the board
LCD_DATA13: U10.2 (VPB[5]); also elsewhere on the board
LCD_DATA14: U10.1 (VPB[6]); also elsewhere on the board
LCD_DATA15: U10.64 (VPB[7]); also elsewhere on the board
LCD_DATA16: U10.18 (VPC[0]); also elsewhere on the board
LCD_DATA17: U10.17 (VPC[1]); also elsewhere on the board
LCD_DATA18: U10.16 (VPC[2]); also elsewhere on the board
LCD_DATA19: U10.15 (VPC[3]); also elsewhere on the board
LCD_DATA20: U10.13 (VPC[4]); also elsewhere on the board
LCD_DATA21: U10.12 (VPC[5]); also elsewhere on the board
LCD_DATA22: U10.11 (VPC[6]); also elsewhere on the board
LCD_DATA23: U10.10 (VPC[7]); also elsewhere on the board
LCD_DE: U10.20 (DE/FREF); also elsewhere on the board
LCD_HSYNC: U10.22 (HSYNC/HREF); also elsewhere on the board
LCD_PCLK: U10.4 (PCLK); also elsewhere on the board
LCD_VSYNC: U10.21 (VSYNC/VREF); also elsewhere on the board
unnamed: D3.A, R28.1
unnamed: FB7.1, R26.1, R27.1
VCC_1V8: FB1.2; also elsewhere on the board
VCC_3V3: R28.2, R43.1; also elsewhere on the board
VCC_5V0: FB7.2; also elsewhere on the board

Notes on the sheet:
HDMI transmitter
TODO: 2u2 with 0201 package

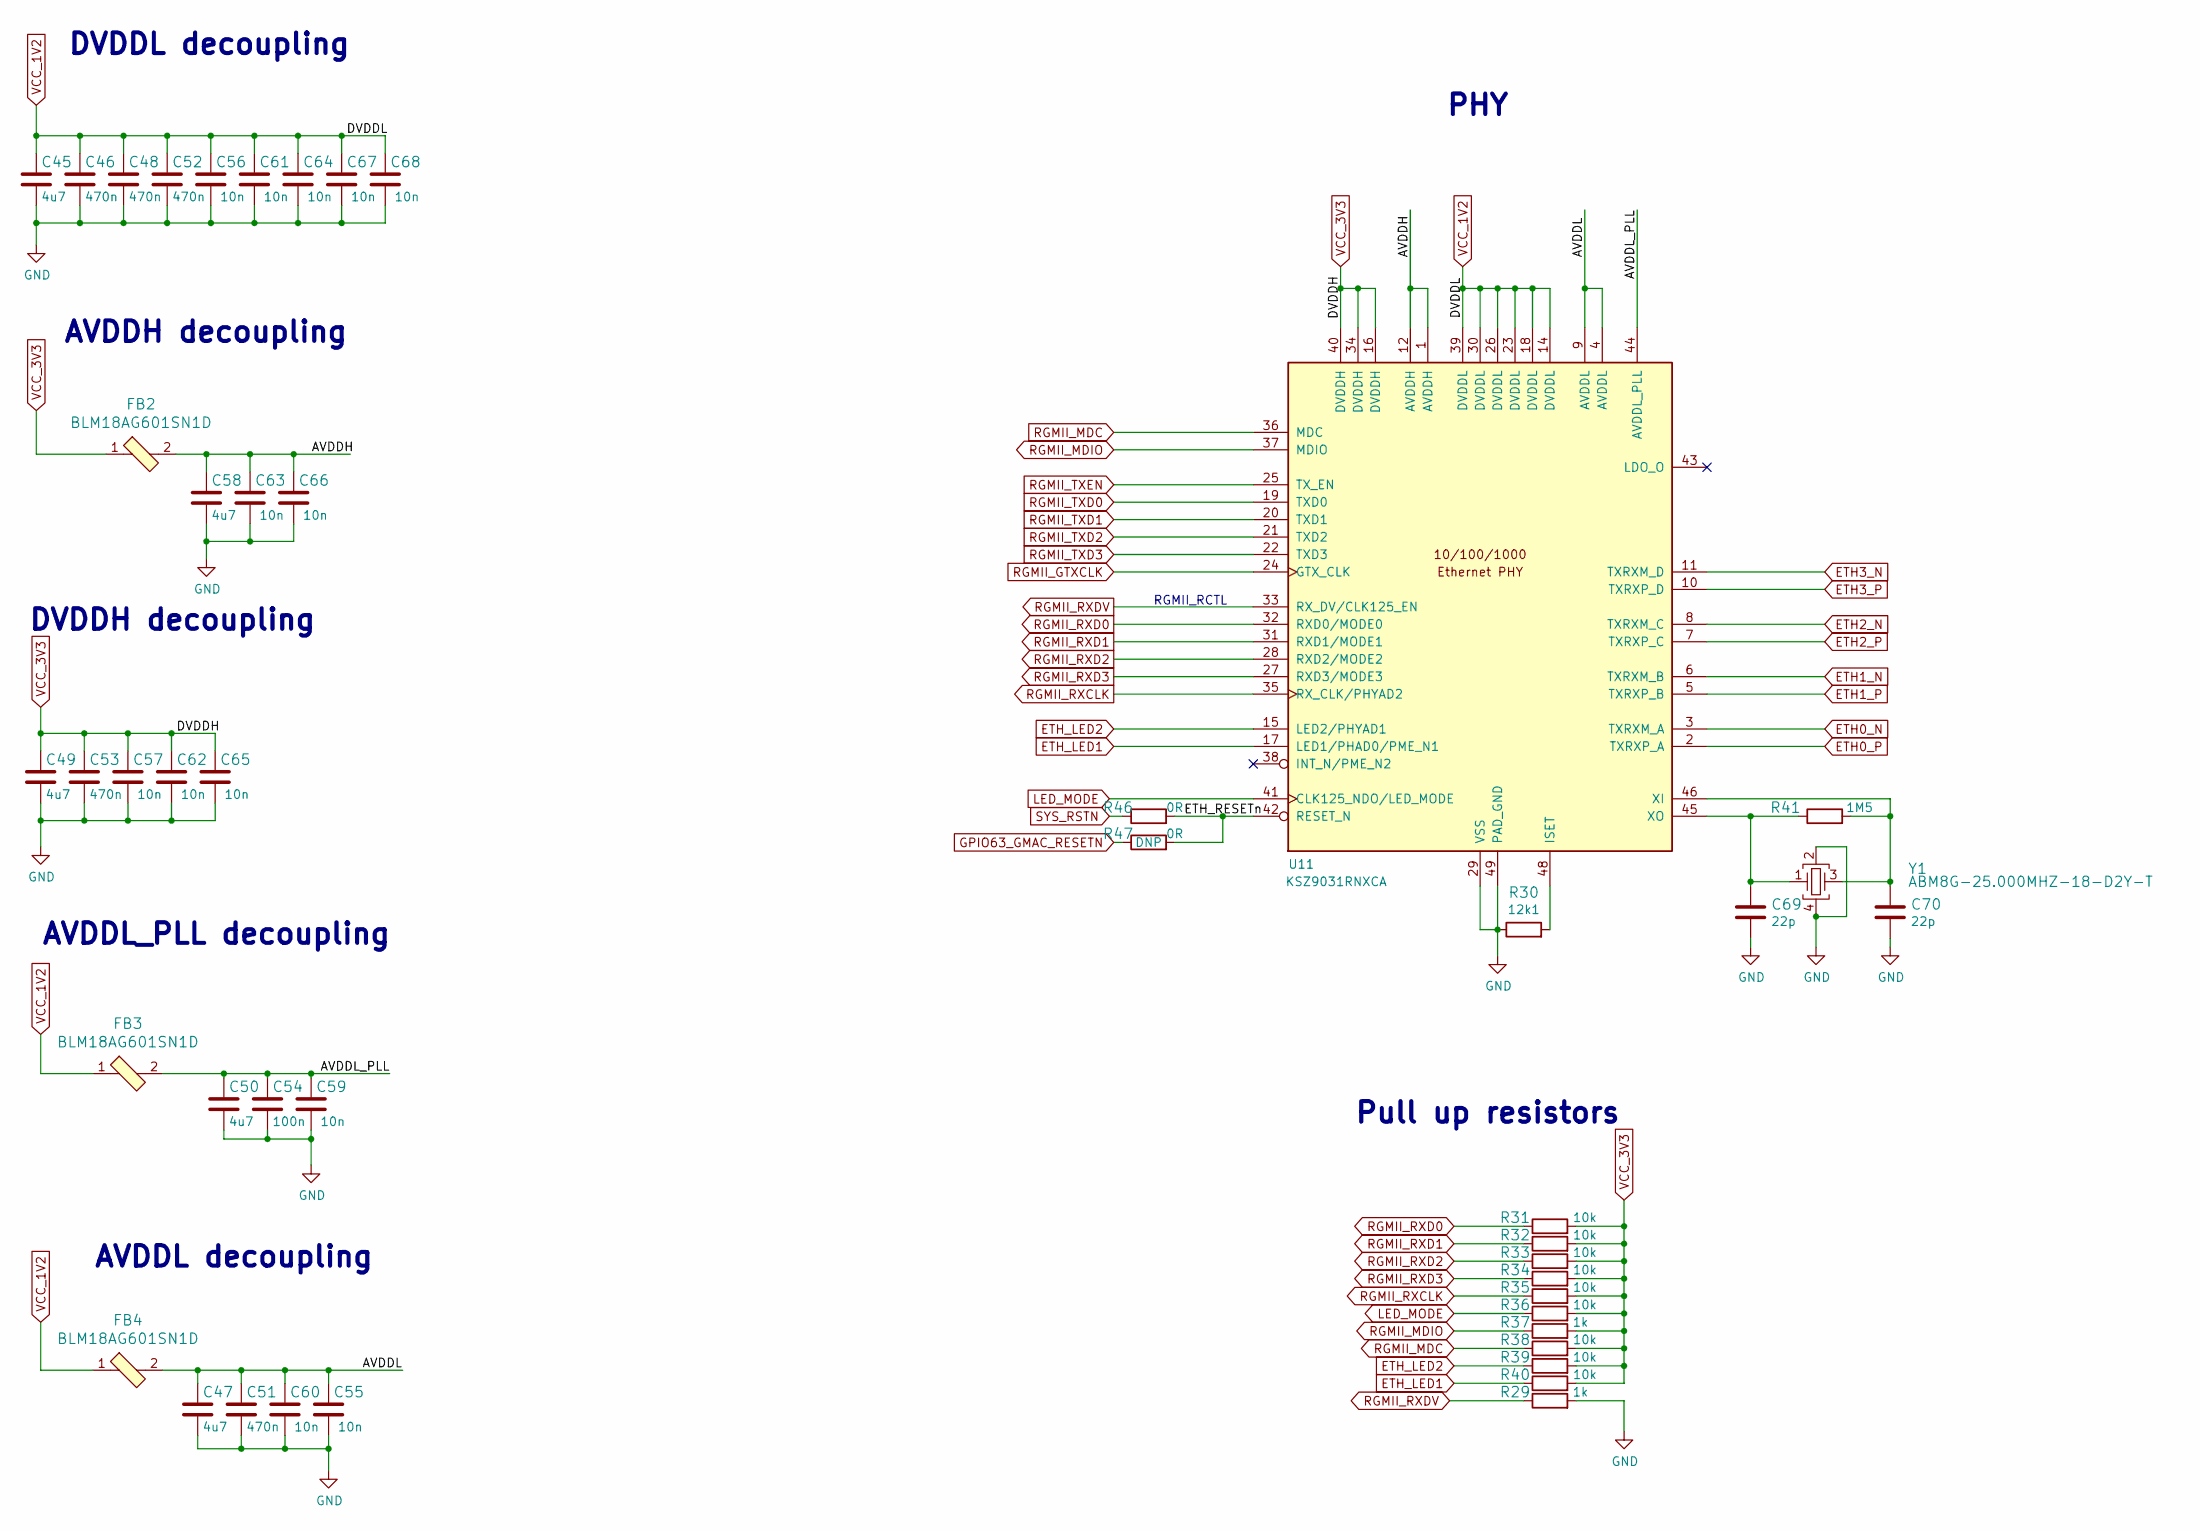
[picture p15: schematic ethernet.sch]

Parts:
C45, C47, C49, C50, C58: C_4u7_0402; 0402-cap; MPN GRM155R61A475MEAAD
C46, C48, C51, C52, C53: C_470n_0201; 0201-res; MPN CC0201KRX5R5BB474
C54: C_100n_0201; 0201-res; MPN CC0201KRX6S5BB104
C55, C56, C57, C59, C60, C61, C62, C63, C64, C65, C66, C67, C68: C_10n_0201; 0201-res; MPN GRM033R70J103KA01D
C69, C70: C_22p_0402; 0402-cap; MPN CC0402JRNPO9BN220
FB2, FB3, FB4: BLM18AG601SN1D; 0603; MPN BLM18AG601SN1D
R29, R37: R_1k_0402; 0402-res; MPN CR0402-FX-1001GLF
R30: R_12k1_0402; 0402-res; MPN MCWR04X1212FTL
R31, R32, R33, R34, R35, R36, R38, R39, R40: R_10k_0201; 0201-res; MPN RC0201FR-0710KL
R41: R_1M5_0402; 0402-res; MPN MCWR04W1504FTL
R46, R47: R_0R_0201; 0201-res; MPN CRCW02010000Z0ED
U11: KSZ9031RNXCA; QFN-48-Microchip-QFN77-48LD-PL-2; MPN KSZ9031RNXCA
Y1: ABM8G-25.000MHZ-18-D2Y-T; KX-7; MPN ABM8G-25.000MHZ-18-D2Y-T

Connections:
/Ethernet/AVDDH: C58.1, C63.1, C66.1, FB2.2, U11.1 (AVDDH), U11.12 (AVDDH)
/Ethernet/AVDDL: C47.1, C51.1, C55.1, C60.1, FB4.2, U11.4 (AVDDL), U11.9 (AVDDL)
/Ethernet/AVDDL_PLL: C50.1, C54.1, C59.1, FB3.2, U11.44 (AVDDL_PLL)
/Ethernet/ETH_RESETn: R46.2, R47.2, U11.42 (RESET_N)
ETH0_N: U11.3 (TXRXM_A); also elsewhere on the board
ETH0_P: U11.2 (TXRXP_A); also elsewhere on the board
ETH1_N: U11.6 (TXRXM_B); also elsewhere on the board
ETH1_P: U11.5 (TXRXP_B); also elsewhere on the board
ETH2_N: U11.8 (TXRXM_C); also elsewhere on the board
ETH2_P: U11.7 (TXRXP_C); also elsewhere on the board
ETH3_N: U11.11 (TXRXM_D); also elsewhere on the board
ETH3_P: U11.10 (TXRXP_D); also elsewhere on the board
ETH_LED1: R40.1, U11.17 (LED1/PHAD0/PME_N1); also elsewhere on the board
ETH_LED2: R39.1, U11.15 (LED2/PHYAD1); also elsewhere on the board
GND: C45.2, C46.2, C47.2, C48.2, C49.2, C50.2, C51.2, C52.2, C53.2, C54.2, C55.2, C56.2, C57.2, C58.2, C59.2, C60.2, C61.2, C62.2, C63.2, C64.2, C65.2, C66.2, C67.2, C68.2, C69.2, C70.2, R29.2, R30.1, U11.29 (VSS), U11.49 (PAD_GND), Y1.2, Y1.4; also elsewhere on the board
GPIO63_GMAC_RESETN: R47.1; also elsewhere on the board
LED_MODE: R36.1, U11.41 (CLK125_NDO/LED_MODE)
unnamed: C69.1, R41.1, U11.45 (XO), Y1.1
unnamed: C70.1, R41.2, U11.46 (XI), Y1.3
unnamed: R30.2, U11.48 (ISET)
RGMII_GTXCLK: U11.24 (GTX_CLK); also elsewhere on the board
RGMII_MDC: R38.1, U11.36 (MDC); also elsewhere on the board
RGMII_MDIO: R37.1, U11.37 (MDIO); also elsewhere on the board
RGMII_RXCLK: R35.1, U11.35 (RX_CLK/PHYAD2); also elsewhere on the board
RGMII_RXD0: R31.1, U11.32 (RXD0/MODE0); also elsewhere on the board
RGMII_RXD1: R32.1, U11.31 (RXD1/MODE1); also elsewhere on the board
RGMII_RXD2: R33.1, U11.28 (RXD2/MODE2); also elsewhere on the board
RGMII_RXD3: R34.1, U11.27 (RXD3/MODE3); also elsewhere on the board
RGMII_RXDV: R29.1, U11.33 (RX_DV/CLK125_EN); also elsewhere on the board
RGMII_TXD0: U11.19 (TXD0); also elsewhere on the board
RGMII_TXD1: U11.20 (TXD1); also elsewhere on the board
RGMII_TXD2: U11.21 (TXD2); also elsewhere on the board
RGMII_TXD3: U11.22 (TXD3); also elsewhere on the board
RGMII_TXEN: U11.25 (TX_EN); also elsewhere on the board
SYS_RSTN: R46.1; also elsewhere on the board
VCC_1V2: C45.1, C46.1, C48.1, C52.1, C56.1, C61.1, C64.1, C67.1, C68.1, FB3.1, FB4.1, U11.14 (DVDDL), U11.18 (DVDDL), U11.23 (DVDDL), U11.26 (DVDDL), U11.30 (DVDDL), U11.39 (DVDDL); also elsewhere on the board
VCC_3V3: C49.1, C53.1, C57.1, C62.1, C65.1, FB2.1, R31.2, R32.2, R33.2, R34.2, R35.2, R36.2, R37.2, R38.2, R39.2, R40.2, U11.16 (DVDDH), U11.34 (DVDDH), U11.40 (DVDDH); also elsewhere on the board

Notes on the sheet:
DVDDH decoupling
DVDDL decoupling
PHY
Pull up resistors
AVDDL_PLL decoupling
AVDDL decoupling
AVDDH decoupling
RGMII_RCTL

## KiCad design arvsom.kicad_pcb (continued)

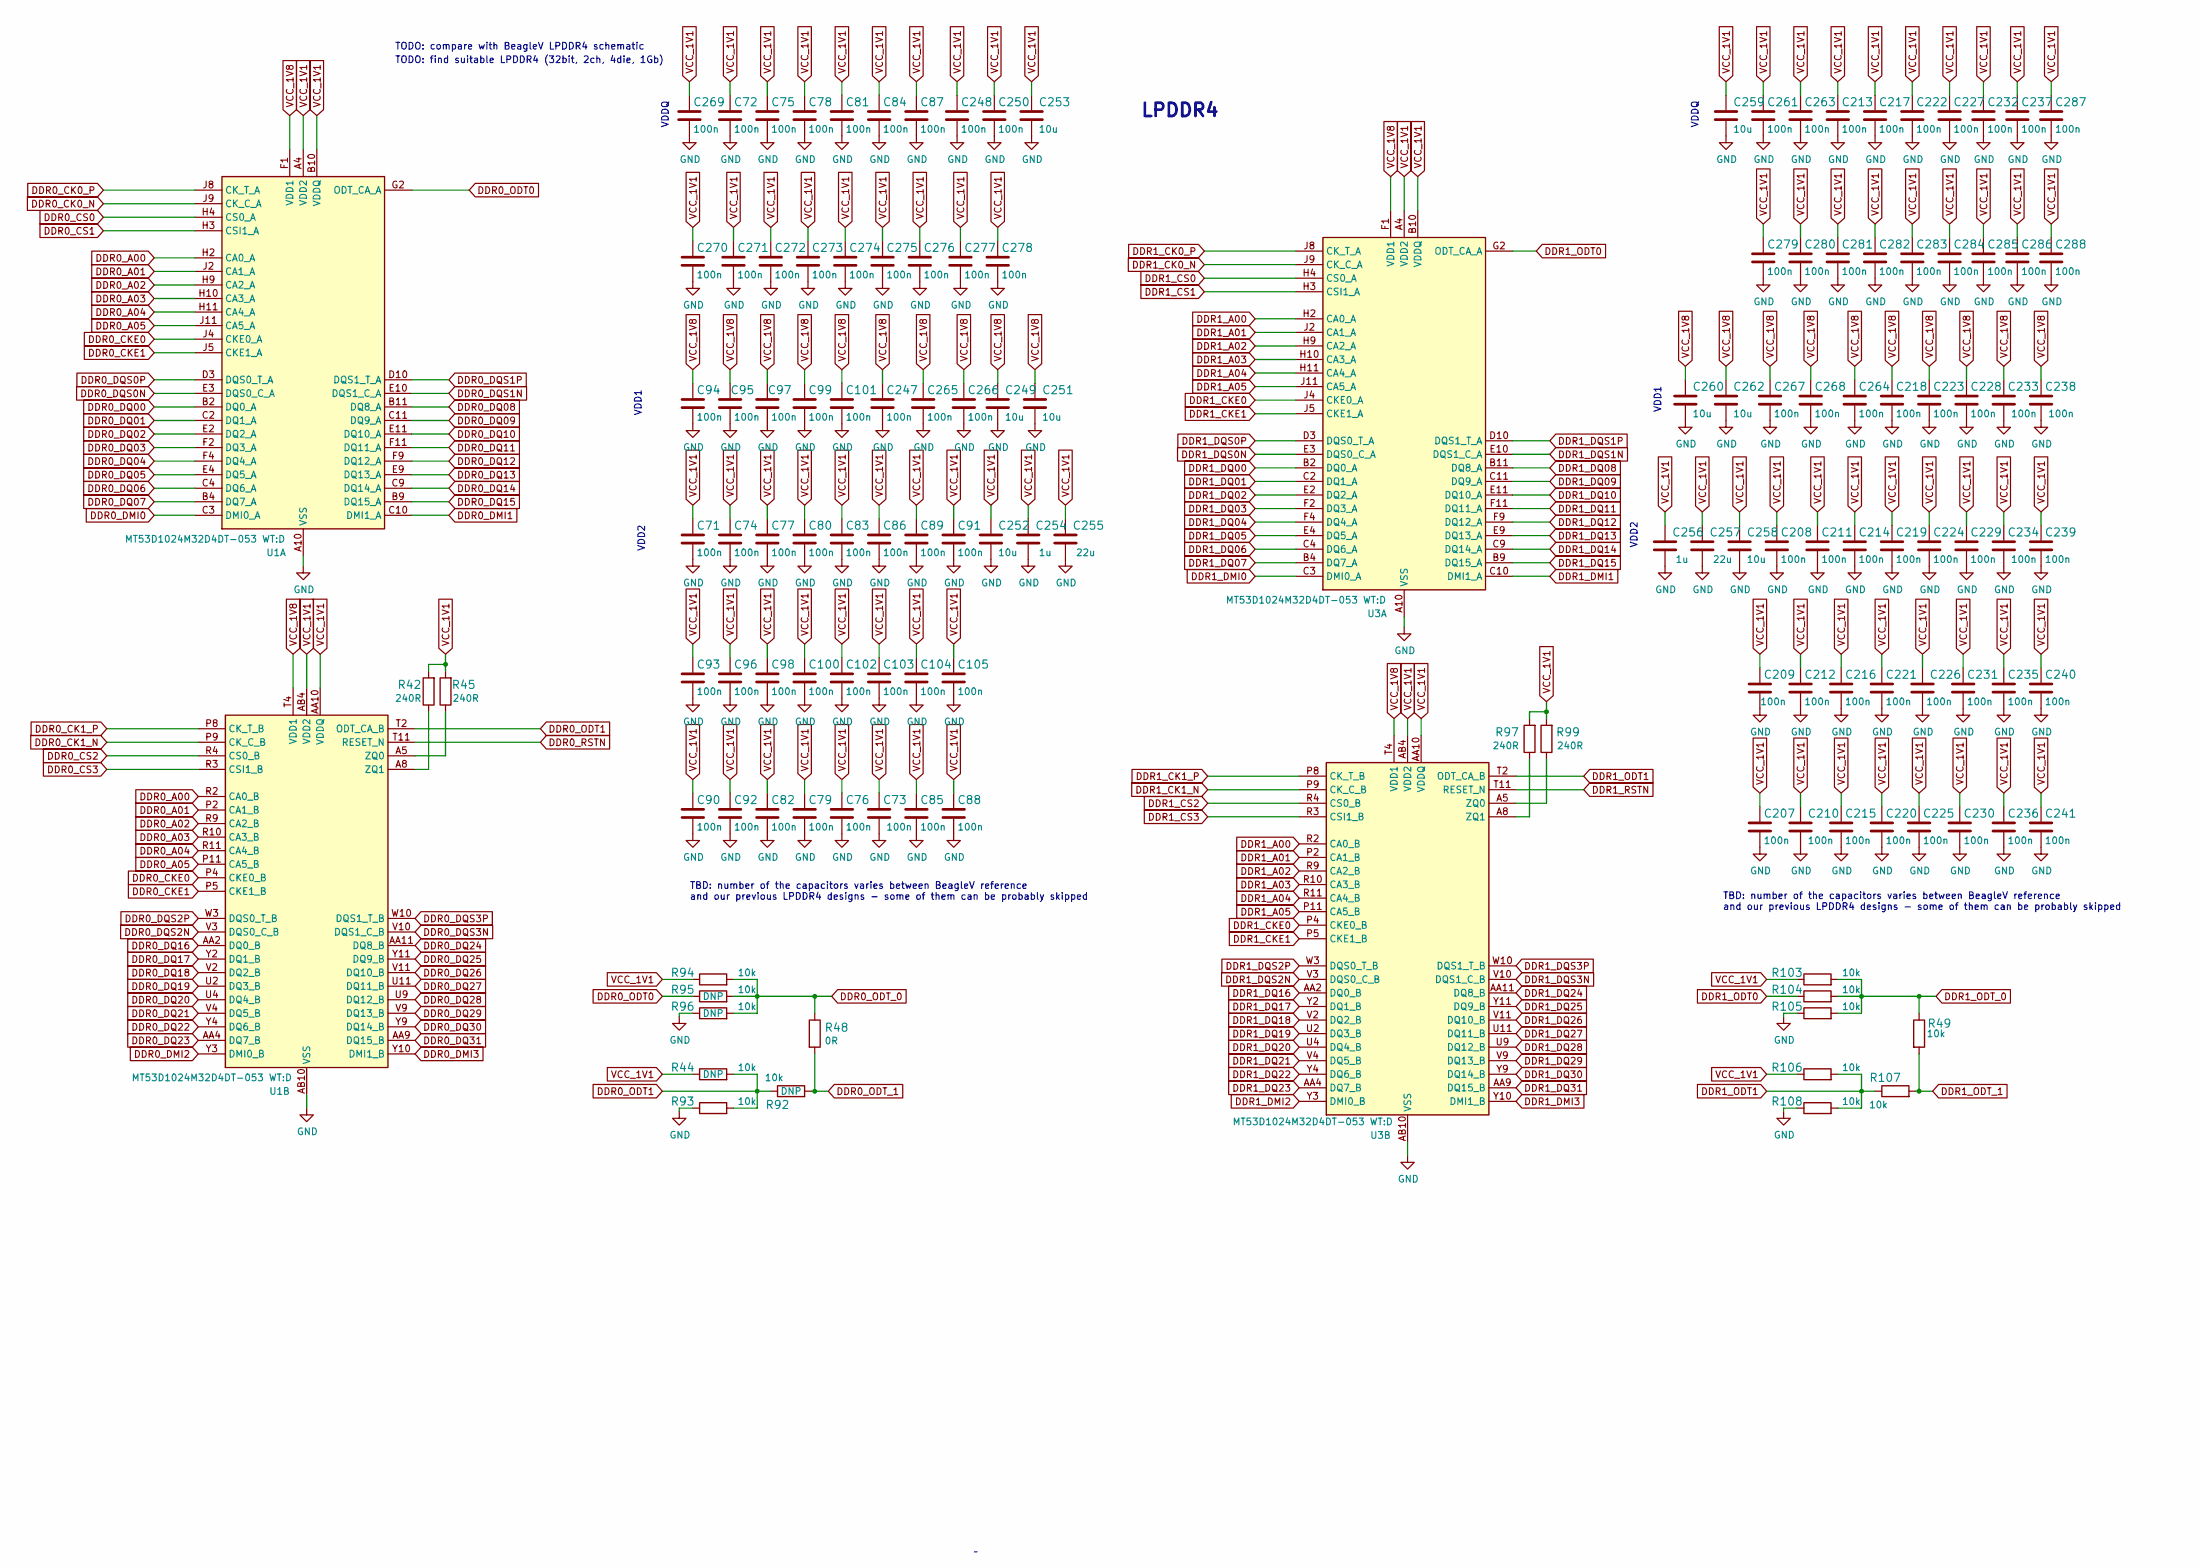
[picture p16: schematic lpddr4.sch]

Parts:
C71, C72, C73, C74, C75, C76, C77, C78, C79, C80, C81, C82, C83, C84, C85, C86, C87, C88, C89, C90, C91, C92, C93, C94, C95, C96, C97, C98, C99, C100, C101, C102, C103, C104, C105, C207, C208, C209, C210, C211, C212, C213, C214, C215, C216, C217, C218, C219, C220, C221, C222, C223, C224, C225, C226, C227, C228, C229, C230, C231, C232, C233, C234, C235, C236, C237, C238, C239, C240, C241, C247, C248, C250, C261, C263, C264, C265, C266, C267, C268, C269, C270, C271, C272, C273, C274, C275, C276, C277, C278, C279, C280, C281, C282, C283, C284, C285, C286, C287, C288: C_100n_0201; 0201-res; MPN CC0201KRX6S5BB104
C249, C251, C252, C253, C258, C259, C260, C262: C_10u_0402; 0402-cap; MPN GRM155R60J106ME44D
C254, C256: C_1u_0402; 0402-cap; MPN C1005X6S1A105K050BC
C255, C257: C_22u_0603; 0603-cap; MPN GRM188R60J226MEA0D
R42, R45, R97, R99: R_240R_0402; 0402-res; MPN ERJ2GEJ241X
R44, R49, R92, R93, R94, R95, R96, R103, R104, R105, R106, R107, R108: R_10k_0201; 0201-res; MPN RC0201FR-0710KL
R48: R_0R_0201; 0201-res; MPN CRCW02010000Z0ED
U1, U3: MT53D1024M32D4DT-053; BGA-200_10.0x14.5mm_Layout12x22_P0.80x0.65mm; MPN MT53D1024M32D4DT-053 WT:D

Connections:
DDR0_A00: U1.H2 (CA0_A), U1.R2 (CA0_B); also elsewhere on the board
DDR0_A01: U1.J2 (CA1_A), U1.P2 (CA1_B); also elsewhere on the board
DDR0_A02: U1.H9 (CA2_A), U1.R9 (CA2_B); also elsewhere on the board
DDR0_A03: U1.H10 (CA3_A), U1.R10 (CA3_B); also elsewhere on the board
DDR0_A04: U1.H11 (CA4_A), U1.R11 (CA4_B); also elsewhere on the board
DDR0_A05: U1.J11 (CA5_A), U1.P11 (CA5_B); also elsewhere on the board
DDR0_CK0_N: U1.J9 (CK_C_A); also elsewhere on the board
DDR0_CK0_P: U1.J8 (CK_T_A); also elsewhere on the board
DDR0_CK1_N: U1.P9 (CK_C_B); also elsewhere on the board
DDR0_CK1_P: U1.P8 (CK_T_B); also elsewhere on the board
DDR0_CKE0: U1.J4 (CKE0_A), U1.P4 (CKE0_B); also elsewhere on the board
DDR0_CKE1: U1.J5 (CKE1_A), U1.P5 (CKE1_B); also elsewhere on the board
DDR0_CS0: U1.H4 (CS0_A); also elsewhere on the board
DDR0_CS1: U1.H3 (CSI1_A); also elsewhere on the board
DDR0_CS2: U1.R4 (CS0_B); also elsewhere on the board
DDR0_CS3: U1.R3 (CSI1_B); also elsewhere on the board
DDR0_DMI0: U1.C3 (DMI0_A); also elsewhere on the board
DDR0_DMI1: U1.C10 (DMI1_A); also elsewhere on the board
DDR0_DMI2: U1.Y3 (DMI0_B); also elsewhere on the board
DDR0_DMI3: U1.Y10 (DMI1_B); also elsewhere on the board
DDR0_DQ00: U1.B2 (DQ0_A); also elsewhere on the board
DDR0_DQ01: U1.C2 (DQ1_A); also elsewhere on the board
DDR0_DQ02: U1.E2 (DQ2_A); also elsewhere on the board
DDR0_DQ03: U1.F2 (DQ3_A); also elsewhere on the board
DDR0_DQ04: U1.F4 (DQ4_A); also elsewhere on the board
DDR0_DQ05: U1.E4 (DQ5_A); also elsewhere on the board
DDR0_DQ06: U1.C4 (DQ6_A); also elsewhere on the board
DDR0_DQ07: U1.B4 (DQ7_A); also elsewhere on the board
DDR0_DQ08: U1.B11 (DQ8_A); also elsewhere on the board
DDR0_DQ09: U1.C11 (DQ9_A); also elsewhere on the board
DDR0_DQ10: U1.E11 (DQ10_A); also elsewhere on the board
DDR0_DQ11: U1.F11 (DQ11_A); also elsewhere on the board
DDR0_DQ12: U1.F9 (DQ12_A); also elsewhere on the board
DDR0_DQ13: U1.E9 (DQ13_A); also elsewhere on the board
DDR0_DQ14: U1.C9 (DQ14_A); also elsewhere on the board
DDR0_DQ15: U1.B9 (DQ15_A); also elsewhere on the board
DDR0_DQ16: U1.AA2 (DQ0_B); also elsewhere on the board
DDR0_DQ17: U1.Y2 (DQ1_B); also elsewhere on the board
DDR0_DQ18: U1.V2 (DQ2_B); also elsewhere on the board
DDR0_DQ19: U1.U2 (DQ3_B); also elsewhere on the board
DDR0_DQ20: U1.U4 (DQ4_B); also elsewhere on the board
DDR0_DQ21: U1.V4 (DQ5_B); also elsewhere on the board
DDR0_DQ22: U1.Y4 (DQ6_B); also elsewhere on the board
DDR0_DQ23: U1.AA4 (DQ7_B); also elsewhere on the board
DDR0_DQ24: U1.AA11 (DQ8_B); also elsewhere on the board
DDR0_DQ25: U1.Y11 (DQ9_B); also elsewhere on the board
DDR0_DQ26: U1.V11 (DQ10_B); also elsewhere on the board
DDR0_DQ27: U1.U11 (DQ11_B); also elsewhere on the board
DDR0_DQ28: U1.U9 (DQ12_B); also elsewhere on the board
DDR0_DQ29: U1.V9 (DQ13_B); also elsewhere on the board
DDR0_DQ30: U1.Y9 (DQ14_B); also elsewhere on the board
DDR0_DQ31: U1.AA9 (DQ15_B); also elsewhere on the board
DDR0_DQS0N: U1.E3 (DQS0_C_A); also elsewhere on the board
DDR0_DQS0P: U1.D3 (DQS0_T_A); also elsewhere on the board
DDR0_DQS1N: U1.E10 (DQS1_C_A); also elsewhere on the board
DDR0_DQS1P: U1.D10 (DQS1_T_A); also elsewhere on the board
DDR0_DQS2N: U1.V3 (DQS0_C_B); also elsewhere on the board
DDR0_DQS2P: U1.W3 (DQS0_T_B); also elsewhere on the board
DDR0_DQS3N: U1.V10 (DQS1_C_B); also elsewhere on the board
DDR0_DQS3P: U1.W10 (DQS1_T_B); also elsewhere on the board
DDR0_ODT0: R95.1, U1.G2 (ODT_CA_A); also elsewhere on the board
DDR0_ODT1: R44.2, R92.1, R93.2, U1.T2 (ODT_CA_B); also elsewhere on the board
DDR0_ODT_0: R48.1, R94.2, R95.2, R96.2
DDR0_ODT_1: R48.2, R92.2
DDR0_RSTN: U1.T11 (RESET_N); also elsewhere on the board
DDR1_A00: U3.H2 (CA0_A), U3.R2 (CA0_B); also elsewhere on the board
DDR1_A01: U3.J2 (CA1_A), U3.P2 (CA1_B); also elsewhere on the board
DDR1_A02: U3.H9 (CA2_A), U3.R9 (CA2_B); also elsewhere on the board
DDR1_A03: U3.H10 (CA3_A), U3.R10 (CA3_B); also elsewhere on the board
DDR1_A04: U3.H11 (CA4_A), U3.R11 (CA4_B); also elsewhere on the board
DDR1_A05: U3.J11 (CA5_A), U3.P11 (CA5_B); also elsewhere on the board
DDR1_CK0_N: U3.J9 (CK_C_A); also elsewhere on the board
DDR1_CK0_P: U3.J8 (CK_T_A); also elsewhere on the board
DDR1_CK1_N: U3.P9 (CK_C_B); also elsewhere on the board
DDR1_CK1_P: U3.P8 (CK_T_B); also elsewhere on the board
DDR1_CKE0: U3.J4 (CKE0_A), U3.P4 (CKE0_B); also elsewhere on the board
DDR1_CKE1: U3.J5 (CKE1_A), U3.P5 (CKE1_B); also elsewhere on the board
DDR1_CS0: U3.H4 (CS0_A); also elsewhere on the board
DDR1_CS1: U3.H3 (CSI1_A); also elsewhere on the board
DDR1_CS2: U3.R4 (CS0_B); also elsewhere on the board
DDR1_CS3: U3.R3 (CSI1_B); also elsewhere on the board
DDR1_DMI0: U3.C3 (DMI0_A); also elsewhere on the board
DDR1_DMI1: U3.C10 (DMI1_A); also elsewhere on the board
DDR1_DMI2: U3.Y3 (DMI0_B); also elsewhere on the board
DDR1_DMI3: U3.Y10 (DMI1_B); also elsewhere on the board
DDR1_DQ00: U3.B2 (DQ0_A); also elsewhere on the board
DDR1_DQ01: U3.C2 (DQ1_A); also elsewhere on the board
DDR1_DQ02: U3.E2 (DQ2_A); also elsewhere on the board
DDR1_DQ03: U3.F2 (DQ3_A); also elsewhere on the board
DDR1_DQ04: U3.F4 (DQ4_A); also elsewhere on the board
DDR1_DQ05: U3.E4 (DQ5_A); also elsewhere on the board
DDR1_DQ06: U3.C4 (DQ6_A); also elsewhere on the board
DDR1_DQ07: U3.B4 (DQ7_A); also elsewhere on the board
DDR1_DQ08: U3.B11 (DQ8_A); also elsewhere on the board
DDR1_DQ09: U3.C11 (DQ9_A); also elsewhere on the board
DDR1_DQ10: U3.E11 (DQ10_A); also elsewhere on the board
DDR1_DQ11: U3.F11 (DQ11_A); also elsewhere on the board
DDR1_DQ12: U3.F9 (DQ12_A); also elsewhere on the board
DDR1_DQ13: U3.E9 (DQ13_A); also elsewhere on the board
DDR1_DQ14: U3.C9 (DQ14_A); also elsewhere on the board
DDR1_DQ15: U3.B9 (DQ15_A); also elsewhere on the board
DDR1_DQ16: U3.AA2 (DQ0_B); also elsewhere on the board
DDR1_DQ17: U3.Y2 (DQ1_B); also elsewhere on the board
DDR1_DQ18: U3.V2 (DQ2_B); also elsewhere on the board
DDR1_DQ19: U3.U2 (DQ3_B); also elsewhere on the board
DDR1_DQ20: U3.U4 (DQ4_B); also elsewhere on the board
DDR1_DQ21: U3.V4 (DQ5_B); also elsewhere on the board
DDR1_DQ22: U3.Y4 (DQ6_B); also elsewhere on the board
DDR1_DQ23: U3.AA4 (DQ7_B); also elsewhere on the board
DDR1_DQ24: U3.AA11 (DQ8_B); also elsewhere on the board
DDR1_DQ25: U3.Y11 (DQ9_B); also elsewhere on the board
DDR1_DQ26: U3.V11 (DQ10_B); also elsewhere on the board
DDR1_DQ27: U3.U11 (DQ11_B); also elsewhere on the board
DDR1_DQ28: U3.U9 (DQ12_B); also elsewhere on the board
DDR1_DQ29: U3.V9 (DQ13_B); also elsewhere on the board
DDR1_DQ30: U3.Y9 (DQ14_B); also elsewhere on the board
DDR1_DQ31: U3.AA9 (DQ15_B); also elsewhere on the board
DDR1_DQS0N: U3.E3 (DQS0_C_A); also elsewhere on the board
DDR1_DQS0P: U3.D3 (DQS0_T_A); also elsewhere on the board
DDR1_DQS1N: U3.E10 (DQS1_C_A); also elsewhere on the board
DDR1_DQS1P: U3.D10 (DQS1_T_A); also elsewhere on the board
DDR1_DQS2N: U3.V3 (DQS0_C_B); also elsewhere on the board
DDR1_DQS2P: U3.W3 (DQS0_T_B); also elsewhere on the board
DDR1_DQS3N: U3.V10 (DQS1_C_B); also elsewhere on the board
DDR1_DQS3P: U3.W10 (DQS1_T_B); also elsewhere on the board
DDR1_ODT0: R104.1, U3.G2 (ODT_CA_A); also elsewhere on the board
DDR1_ODT1: R106.2, R107.1, R108.2, U3.T2 (ODT_CA_B); also elsewhere on the board
DDR1_ODT_0: R49.1, R103.2, R104.2, R105.2
DDR1_ODT_1: R49.2, R107.2
DDR1_RSTN: U3.T11 (RESET_N); also elsewhere on the board
GND: C71.2, C72.2, C73.2, C74.2, C75.2, C76.2, C77.2, C78.2, C79.2, C80.2, C81.2, C82.2, C83.2, C84.2, C85.2, C86.2, C87.2, C88.2, C89.2, C90.2, C91.2, C92.2, C93.2, C94.2, C95.2, C96.2, C97.2, C98.2, C99.2, C100.2, C101.2, C102.2, C103.2, C104.2, C105.2, C207.2, C208.2, C209.2, C210.2, C211.2, C212.2, C213.2, C214.2, C215.2, C216.2, C217.2, C218.2, C219.2, C220.2, C221.2, C222.2, C223.2, C224.2, C225.2, C226.2, C227.2, C228.2, C229.2, C230.2, C231.2, C232.2, C233.2, C234.2, C235.2, C236.2, C237.2, C238.2, C239.2, C240.2, C241.2, C247.2, C248.2, C249.2, C250.2, C251.2, C252.2, C253.2, C254.2, C255.2, C256.2, C257.2, C258.2, C259.2, C260.2, C261.2, C262.2, C263.2, C264.2, C265.2, C266.2, C267.2, C268.2, C269.2, C270.2, C271.2, C272.2, C273.2, C274.2, C275.2, C276.2, C277.2, C278.2, C279.2, C280.2, C281.2, C282.2, C283.2, C284.2, C285.2, C286.2, C287.2, C288.2, R93.1, R96.1, R105.1, R108.1, U1.A3 (VSS), U1.A10 (VSS), U1.AB3 (VSS), U1.AB5 (VSS), U1.AB8 (VSS), U1.AB10 (VSS), U1.C1 (VSS), U1.C5 (VSS), U1.C8 (VSS), U1.C12 (VSS), U1.D2 (VSS), U1.D4 (VSS), U1.D9 (VSS), U1.D11 (VSS), U1.E1 (VSS), U1.E5 (VSS), U1.E8 (VSS), U1.E12 (VSS), U1.G1 (VSS), U1.G3 (VSS), U1.G5 (VSS), U1.G8 (VSS), U1.G10 (VSS), U1.G12 (VSS), U1.J1 (VSS), U1.J3 (VSS), U1.J10 (VSS), U1.J12 (VSS), U1.K2 (VSS), U1.K4 (VSS), U1.K9 (VSS), U1.K11 (VSS), U1.N2 (VSS), U1.N4 (VSS), U1.N9 (VSS), U1.N11 (VSS), U1.P1 (VSS), U1.P3 (VSS), U1.P10 (VSS), U1.P12 (VSS), U1.T1 (VSS), U1.T3 (VSS), U1.T5 (VSS), U1.T8 (VSS), U1.T10 (VSS), U1.T12 (VSS), U1.V1 (VSS), U1.V5 (VSS), U1.V8 (VSS), U1.V12 (VSS), U1.W2 (VSS), U1.W4 (VSS), U1.W9 (VSS), U1.W11 (VSS), U1.Y1 (VSS), U1.Y5 (VSS), U1.Y8 (VSS), U1.Y12 (VSS), U3.A3 (VSS), U3.A10 (VSS), U3.AB3 (VSS), U3.AB5 (VSS), U3.AB8 (VSS), U3.AB10 (VSS), U3.C1 (VSS), U3.C5 (VSS), U3.C8 (VSS), U3.C12 (VSS), U3.D2 (VSS), U3.D4 (VSS), U3.D9 (VSS), U3.D11 (VSS), U3.E1 (VSS), U3.E5 (VSS), U3.E8 (VSS), U3.E12 (VSS), U3.G1 (VSS), U3.G3 (VSS), U3.G5 (VSS), U3.G8 (VSS), U3.G10 (VSS), U3.G12 (VSS), U3.J1 (VSS), U3.J3 (VSS), U3.J10 (VSS), U3.J12 (VSS), U3.K2 (VSS), U3.K4 (VSS), U3.K9 (VSS), U3.K11 (VSS), U3.N2 (VSS), U3.N4 (VSS), U3.N9 (VSS), U3.N11 (VSS), U3.P1 (VSS), U3.P3 (VSS), U3.P10 (VSS), U3.P12 (VSS), U3.T1 (VSS), U3.T3 (VSS), U3.T5 (VSS), U3.T8 (VSS), U3.T10 (VSS), U3.T12 (VSS), U3.V1 (VSS), U3.V5 (VSS), U3.V8 (VSS), U3.V12 (VSS), U3.W2 (VSS), U3.W4 (VSS), U3.W9 (VSS), U3.W11 (VSS), U3.Y1 (VSS), U3.Y5 (VSS), U3.Y8 (VSS), U3.Y12 (VSS); also elsewhere on the board
unnamed: R42.1, U1.A8 (ZQ1)
unnamed: R45.1, U1.A5 (ZQ0)
unnamed: R97.1, U3.A8 (ZQ1)
unnamed: R99.1, U3.A5 (ZQ0)
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

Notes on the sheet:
LPDDR4
TODO: compare with BeagleV LPDDR4 schematic
TODO: find suitable LPDDR4 (32bit, 2ch, 4die, 1Gb)
TBD: number of the capacitors varies between BeagleV reference and our previous LPDDR4 designs - some of them can be probably skipped
VDDQ
VDD1
VDD2

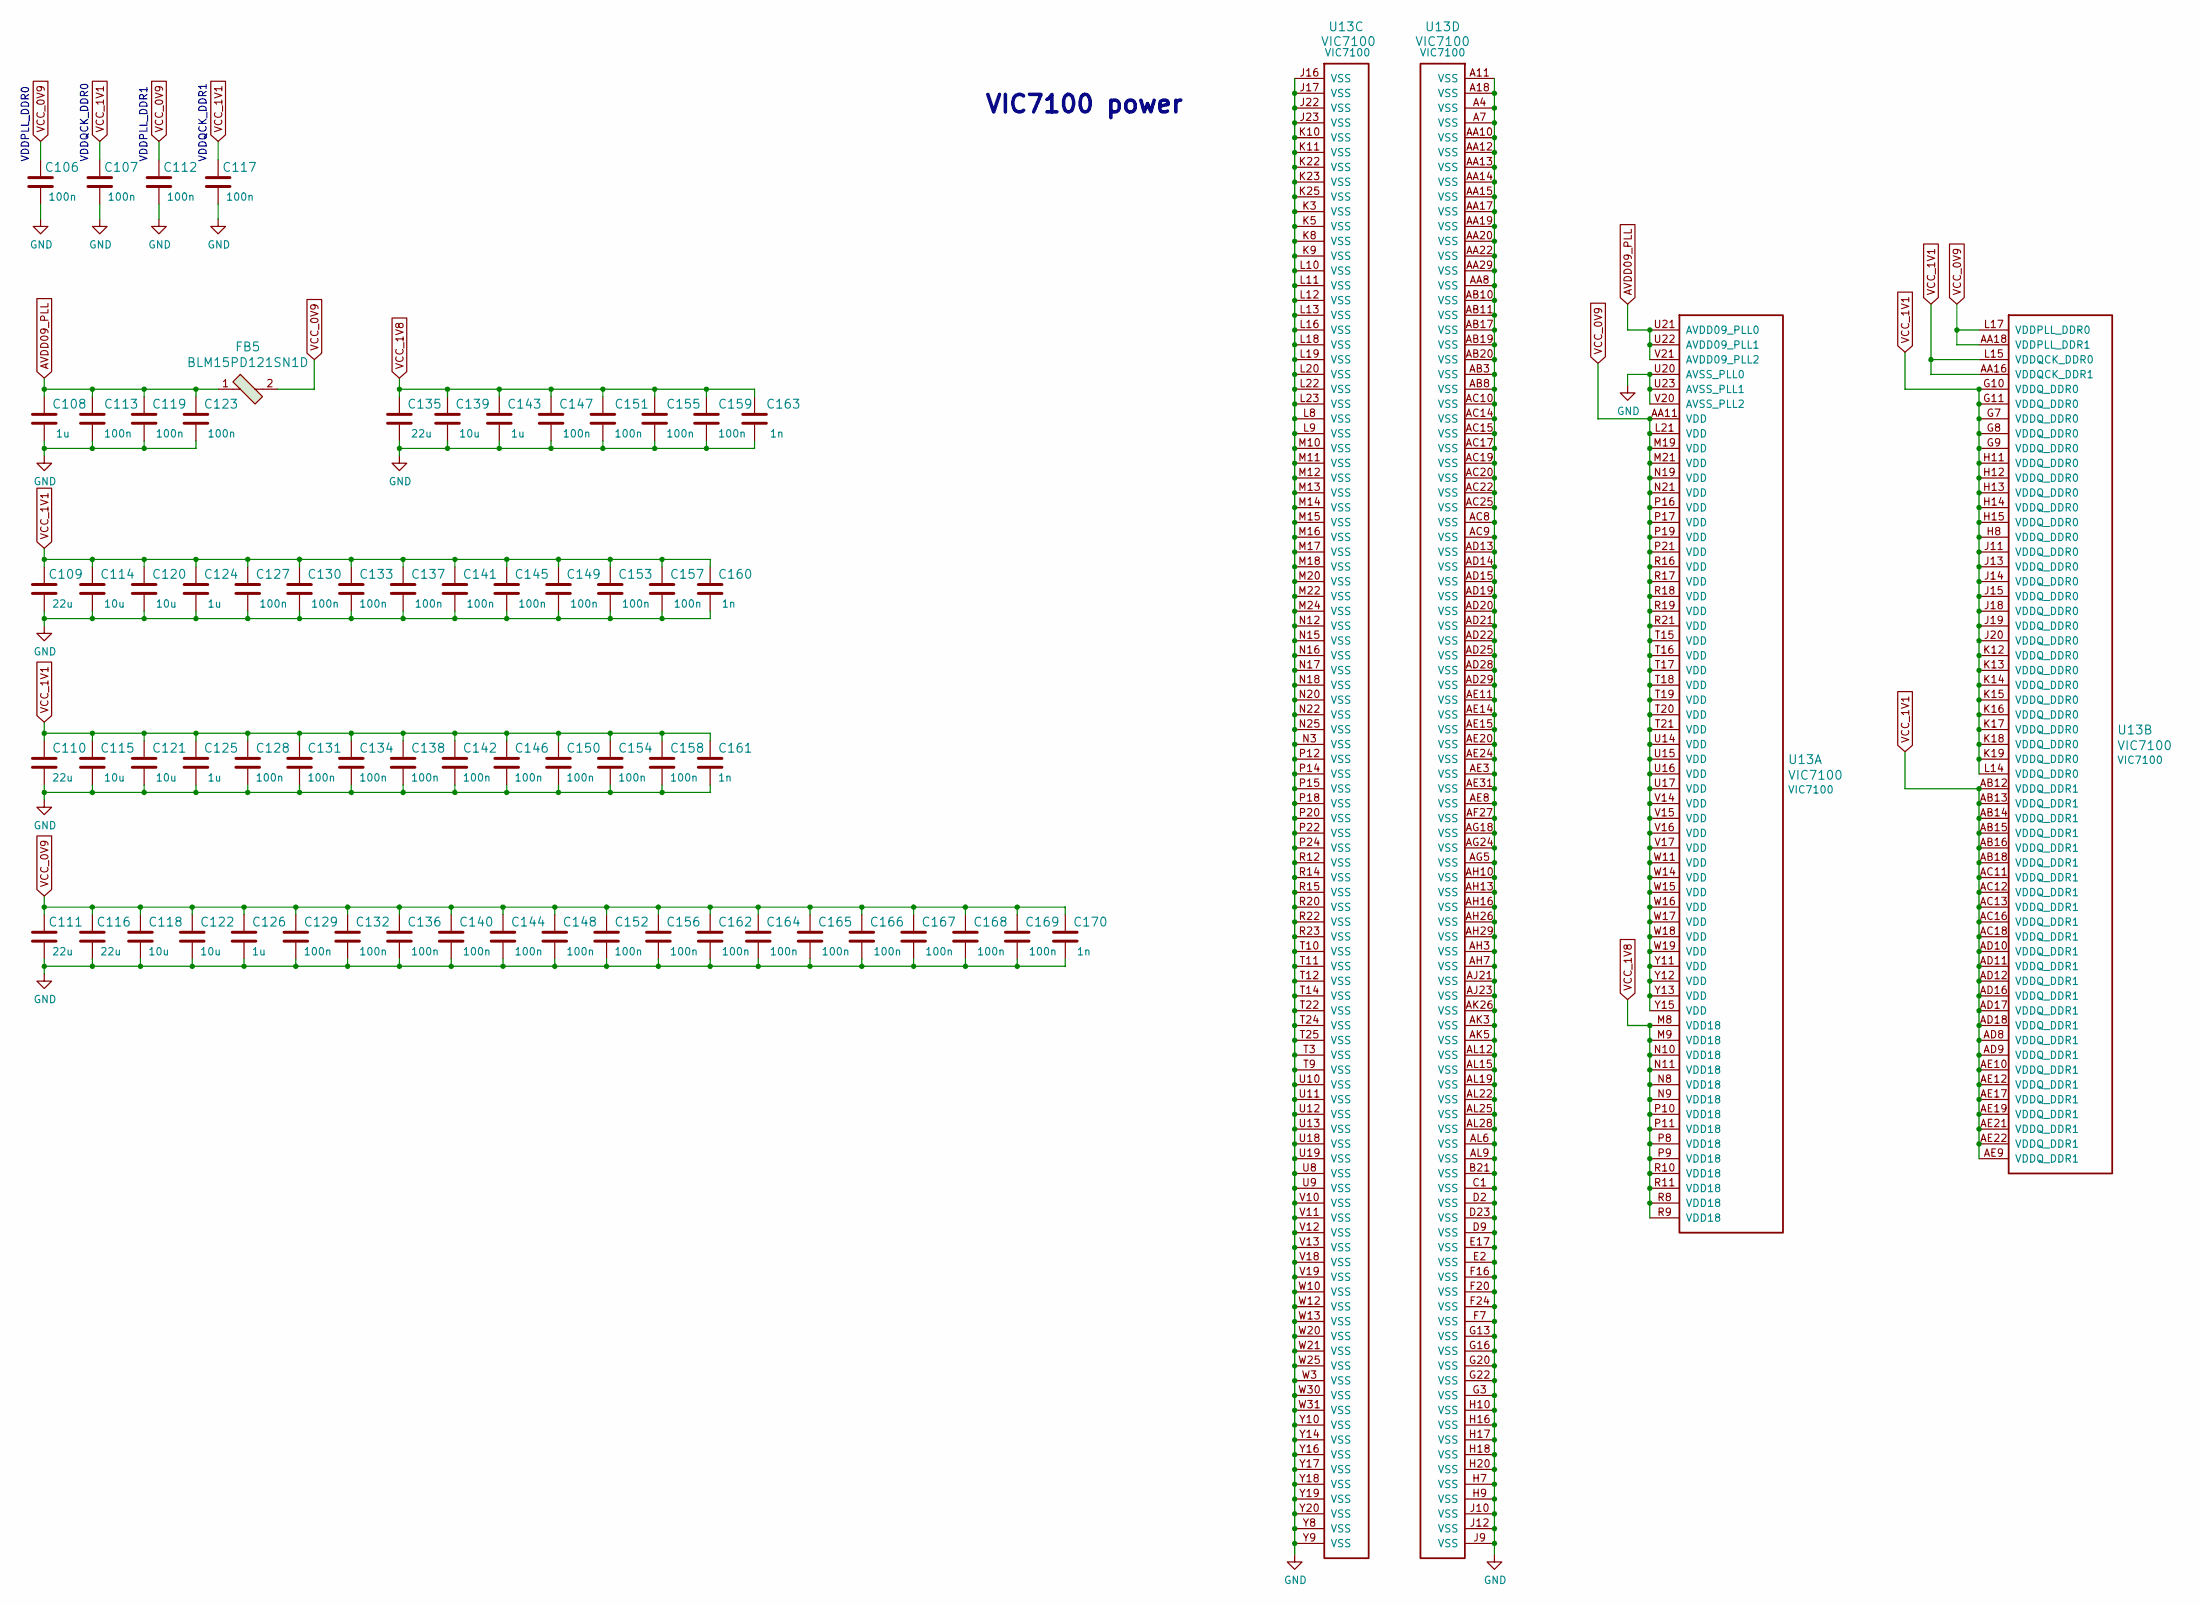
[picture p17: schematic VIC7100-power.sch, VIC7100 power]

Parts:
C106, C107, C112, C113, C117, C119, C123, C127, C128, C129, C130, C131, C132, C133, C134, C136, C137, C138, C140, C141, C142, C144, C145, C146, C147, C148, C149, C150, C151, C152, C153, C154, C155, C156, C157, C158, C159, C162, C164, C165, C166, C167, C168, C169: C_100n_0201; 0201-res; MPN CC0201KRX6S5BB104
C108, C124, C125, C126, C143: C_1u_0402; 0402-cap; MPN C1005X6S1A105K050BC
C109, C110, C111, C116, C135: C_22u_0603; 0603-cap; MPN GRM188R60J226MEA0D
C114, C115, C118, C120, C121, C122, C139: C_10u_0402; 0402-cap; MPN GRM155R60J106ME44D
C160, C161, C163, C170: C_1n_0402; 0402-res; MPN CC0402KRX7R9BB102
FB5: BLM15PD121SN1D; 0402-res; MPN BLM15PD121SN1D
U13: VIC7100; vic7100; MPN VIC7100

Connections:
AVDD09_PLL: C108.1, C113.1, C119.1, C123.1, FB5.1, U13.U21 (AVDD09_PLL0), U13.U22 (AVDD09_PLL1), U13.V21 (AVDD09_PLL2)
GND: C106.2, C107.2, C108.2, C109.2, C110.2, C111.2, C112.2, C113.2, C114.2, C115.2, C116.2, C117.2, C118.2, C119.2, C120.2, C121.2, C122.2, C123.2, C124.2, C125.2, C126.2, C127.2, C128.2, C129.2, C130.2, C131.2, C132.2, C133.2, C134.2, C135.2, C136.2, C137.2, C138.2, C139.2, C140.2, C141.2, C142.2, C143.2, C144.2, C145.2, C146.2, C147.2, C148.2, C149.2, C150.2, C151.2, C152.2, C153.2, C154.2, C155.2, C156.2, C157.2, C158.2, C159.2, C160.2, C161.2, C162.2, C163.2, C164.2, C165.2, C166.2, C167.2, C168.2, C169.2, C170.2, U13.A4 (VSS), U13.A7 (VSS), U13.A11 (VSS), U13.A18 (VSS), U13.AA8 (VSS), U13.AA10 (VSS), U13.AA12 (VSS), U13.AA13 (VSS), U13.AA14 (VSS), U13.AA15 (VSS), U13.AA17 (VSS), U13.AA19 (VSS), U13.AA20 (VSS), U13.AA22 (VSS), U13.AA29 (VSS), U13.AB3 (VSS), U13.AB8 (VSS), U13.AB10 (VSS), U13.AB11 (VSS), U13.AB17 (VSS), U13.AB19 (VSS), U13.AB20 (VSS), U13.AC8 (VSS), U13.AC9 (VSS), U13.AC10 (VSS), U13.AC14 (VSS), U13.AC15 (VSS), U13.AC17 (VSS), U13.AC19 (VSS), U13.AC20 (VSS), U13.AC22 (VSS), U13.AC25 (VSS), U13.AD13 (VSS), U13.AD14 (VSS), U13.AD15 (VSS), U13.AD19 (VSS), U13.AD20 (VSS), U13.AD21 (VSS), U13.AD22 (VSS), U13.AD25 (VSS), U13.AD28 (VSS), U13.AD29 (VSS), U13.AE3 (VSS), U13.AE8 (VSS), U13.AE11 (VSS), U13.AE14 (VSS), U13.AE15 (VSS), U13.AE20 (VSS), U13.AE24 (VSS), U13.AE31 (VSS), U13.AF27 (VSS), U13.AG5 (VSS), U13.AG18 (VSS), U13.AG24 (VSS), U13.AH3 (VSS), U13.AH7 (VSS), U13.AH10 (VSS), U13.AH13 (VSS), U13.AH16 (VSS), U13.AH26 (VSS), U13.AH29 (VSS), U13.AJ21 (VSS), U13.AJ23 (VSS), U13.AK3 (VSS), U13.AK5 (VSS), U13.AK26 (VSS), U13.AL6 (VSS), U13.AL9 (VSS), U13.AL12 (VSS), U13.AL15 (VSS), U13.AL19 (VSS), U13.AL22 (VSS), U13.AL25 (VSS), U13.AL28 (VSS), U13.B21 (VSS), U13.C1 (VSS), U13.D2 (VSS), U13.D9 (VSS), U13.D23 (VSS), U13.E2 (VSS), U13.E17 (VSS), U13.F7 (VSS), U13.F16 (VSS), U13.F20 (VSS), U13.F24 (VSS), U13.G3 (VSS), U13.G13 (VSS), U13.G16 (VSS), U13.G20 (VSS), U13.G22 (VSS), U13.H7 (VSS), U13.H9 (VSS), U13.H10 (VSS), U13.H16 (VSS), U13.H17 (VSS), U13.H18 (VSS), U13.H20 (VSS), U13.J9 (VSS), U13.J10 (VSS), U13.J12 (VSS), U13.J16 (VSS), U13.J17 (VSS), U13.J22 (VSS), U13.J23 (VSS), U13.K3 (VSS), U13.K5 (VSS), U13.K8 (VSS), U13.K9 (VSS), U13.K10 (VSS), U13.K11 (VSS), U13.K22 (VSS), U13.K23 (VSS), U13.K25 (VSS), U13.L8 (VSS), U13.L9 (VSS), U13.L10 (VSS), U13.L11 (VSS), U13.L12 (VSS), U13.L13 (VSS), U13.L16 (VSS), U13.L18 (VSS), U13.L19 (VSS), U13.L20 (VSS), U13.L22 (VSS), U13.L23 (VSS), U13.M10 (VSS), U13.M11 (VSS), U13.M12 (VSS), U13.M13 (VSS), U13.M14 (VSS), U13.M15 (VSS), U13.M16 (VSS), U13.M17 (VSS), U13.M18 (VSS), U13.M20 (VSS), U13.M22 (VSS), U13.M24 (VSS), U13.N3 (VSS), U13.N12 (VSS), U13.N15 (VSS), U13.N16 (VSS), U13.N17 (VSS), U13.N18 (VSS), U13.N20 (VSS), U13.N22 (VSS), U13.N25 (VSS), U13.P12 (VSS), U13.P14 (VSS), U13.P15 (VSS), U13.P18 (VSS), U13.P20 (VSS), U13.P22 (VSS), U13.P24 (VSS), U13.R12 (VSS), U13.R14 (VSS), U13.R15 (VSS), U13.R20 (VSS), U13.R22 (VSS), U13.R23 (VSS), U13.T3 (VSS), U13.T9 (VSS), U13.T10 (VSS), U13.T11 (VSS), U13.T12 (VSS), U13.T14 (VSS), U13.T22 (VSS), U13.T24 (VSS), U13.T25 (VSS), U13.U8 (VSS), U13.U9 (VSS), U13.U10 (VSS), U13.U11 (VSS), U13.U12 (VSS), U13.U13 (VSS), U13.U18 (VSS), U13.U19 (VSS), U13.U20 (AVSS_PLL0), U13.U23 (AVSS_PLL1), U13.V10 (VSS), U13.V11 (VSS), U13.V12 (VSS), U13.V13 (VSS), U13.V18 (VSS), U13.V19 (VSS), U13.V20 (AVSS_PLL2), U13.W3 (VSS), U13.W10 (VSS), U13.W12 (VSS), U13.W13 (VSS), U13.W20 (VSS), U13.W21 (VSS), U13.W25 (VSS), U13.W30 (VSS), U13.W31 (VSS), U13.Y8 (VSS), U13.Y9 (VSS), U13.Y10 (VSS), U13.Y14 (VSS), U13.Y16 (VSS), U13.Y17 (VSS), U13.Y18 (VSS), U13.Y19 (VSS), U13.Y20 (VSS); also elsewhere on the board
VCC_0V9: C106.1, C111.1, C112.1, C116.1, C118.1, C122.1, C126.1, C129.1, C132.1, C136.1, C140.1, C144.1, C148.1, C152.1, C156.1, C162.1, C164.1, C165.1, C166.1, C167.1, C168.1, C169.1, C170.1, FB5.2, U13.AA11 (VDD), U13.AA18 (VDDPLL_DDR1), U13.L17 (VDDPLL_DDR0), U13.L21 (VDD), U13.M19 (VDD), U13.M21 (VDD), U13.N19 (VDD), U13.N21 (VDD), U13.P16 (VDD), U13.P17 (VDD), U13.P19 (VDD), U13.P21 (VDD), U13.R16 (VDD), U13.R17 (VDD), U13.R18 (VDD), U13.R19 (VDD), U13.R21 (VDD), U13.T15 (VDD), U13.T16 (VDD), U13.T17 (VDD), U13.T18 (VDD), U13.T19 (VDD), U13.T20 (VDD), U13.T21 (VDD), U13.U14 (VDD), U13.U15 (VDD), U13.U16 (VDD), U13.U17 (VDD), U13.V14 (VDD), U13.V15 (VDD), U13.V16 (VDD), U13.V17 (VDD), U13.W11 (VDD), U13.W14 (VDD), U13.W15 (VDD), U13.W16 (VDD), U13.W17 (VDD), U13.W18 (VDD), U13.W19 (VDD), U13.Y11 (VDD), U13.Y12 (VDD), U13.Y13 (VDD), U13.Y15 (VDD); also elsewhere on the board
VCC_1V1: C107.1, C109.1, C110.1, C114.1, C115.1, C117.1, C120.1, C121.1, C124.1, C125.1, C127.1, C128.1, C130.1, C131.1, C133.1, C134.1, C137.1, C138.1, C141.1, C142.1, C145.1, C146.1, C149.1, C150.1, C153.1, C154.1, C157.1, C158.1, C160.1, C161.1, U13.AA16 (VDDQCK_DDR1), U13.AB12 (VDDQ_DDR1), U13.AB13 (VDDQ_DDR1), U13.AB14 (VDDQ_DDR1), U13.AB15 (VDDQ_DDR1), U13.AB16 (VDDQ_DDR1), U13.AB18 (VDDQ_DDR1), U13.AC11 (VDDQ_DDR1), U13.AC12 (VDDQ_DDR1), U13.AC13 (VDDQ_DDR1), U13.AC16 (VDDQ_DDR1), U13.AC18 (VDDQ_DDR1), U13.AD8 (VDDQ_DDR1), U13.AD9 (VDDQ_DDR1), U13.AD10 (VDDQ_DDR1), U13.AD11 (VDDQ_DDR1), U13.AD12 (VDDQ_DDR1), U13.AD16 (VDDQ_DDR1), U13.AD17 (VDDQ_DDR1), U13.AD18 (VDDQ_DDR1), U13.AE9 (VDDQ_DDR1), U13.AE10 (VDDQ_DDR1), U13.AE12 (VDDQ_DDR1), U13.AE17 (VDDQ_DDR1), U13.AE19 (VDDQ_DDR1), U13.AE21 (VDDQ_DDR1), U13.AE22 (VDDQ_DDR1), U13.G7 (VDDQ_DDR0), U13.G8 (VDDQ_DDR0), U13.G9 (VDDQ_DDR0), U13.G10 (VDDQ_DDR0), U13.G11 (VDDQ_DDR0), U13.H8 (VDDQ_DDR0), U13.H11 (VDDQ_DDR0), U13.H12 (VDDQ_DDR0), U13.H13 (VDDQ_DDR0), U13.H14 (VDDQ_DDR0), U13.H15 (VDDQ_DDR0), U13.J11 (VDDQ_DDR0), U13.J13 (VDDQ_DDR0), U13.J14 (VDDQ_DDR0), U13.J15 (VDDQ_DDR0), U13.J18 (VDDQ_DDR0), U13.J19 (VDDQ_DDR0), U13.J20 (VDDQ_DDR0), U13.K12 (VDDQ_DDR0), U13.K13 (VDDQ_DDR0), U13.K14 (VDDQ_DDR0), U13.K15 (VDDQ_DDR0), U13.K16 (VDDQ_DDR0), U13.K17 (VDDQ_DDR0), U13.K18 (VDDQ_DDR0), U13.K19 (VDDQ_DDR0), U13.L14 (VDDQ_DDR0), U13.L15 (VDDQCK_DDR0); also elsewhere on the board
VCC_1V8: C135.1, C139.1, C143.1, C147.1, C151.1, C155.1, C159.1, C163.1, U13.M8 (VDD18), U13.M9 (VDD18), U13.N8 (VDD18), U13.N9 (VDD18), U13.N10 (VDD18), U13.N11 (VDD18), U13.P8 (VDD18), U13.P9 (VDD18), U13.P10 (VDD18), U13.P11 (VDD18), U13.R8 (VDD18), U13.R9 (VDD18), U13.R10 (VDD18), U13.R11 (VDD18); also elsewhere on the board

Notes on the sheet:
VDDPLL_DDR0
VDDQCK_DDR0
VDDPLL_DDR1
VDDQCK_DDR1
VIC7100 power

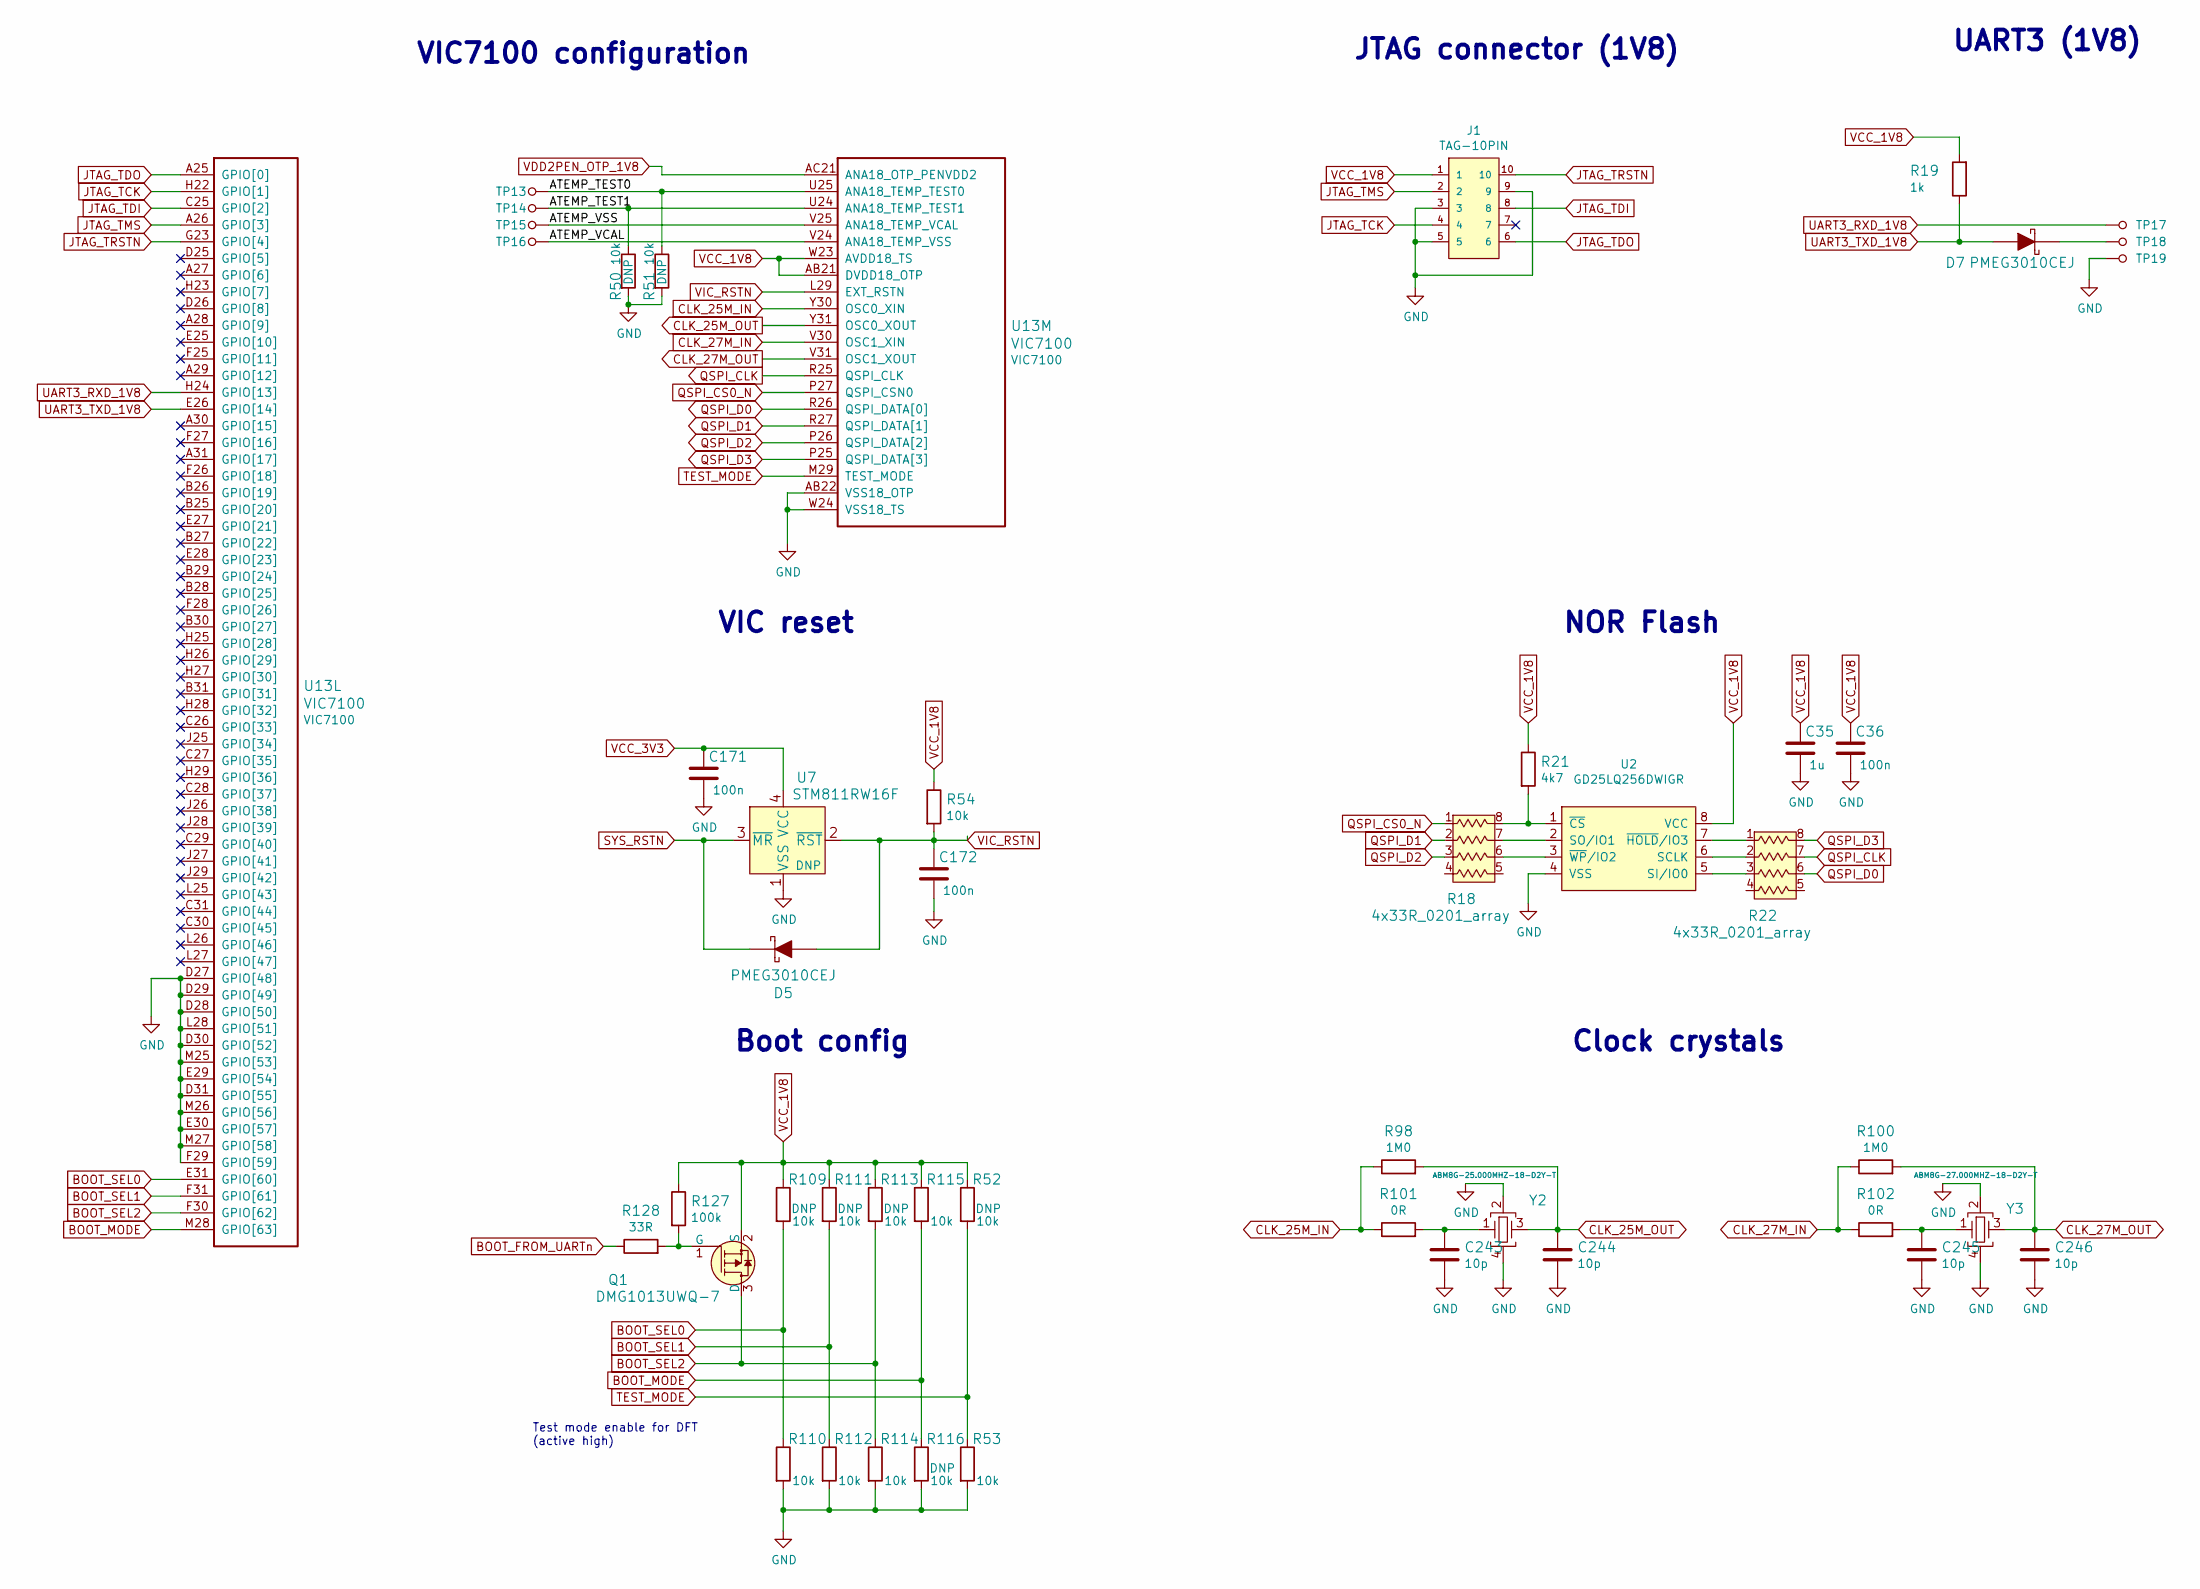
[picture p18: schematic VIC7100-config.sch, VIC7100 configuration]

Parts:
C35: C_1u_0402; 0402-cap; MPN C1005X6S1A105K050BC
C36, C171, C172: C_100n_0201; 0201-res; MPN CC0201KRX6S5BB104
C243, C244, C245, C246: C_10p_0402; 0402-cap; MPN MC0402N100D500CT
D5, D7: PMEG3010CEJ; SOD-323F; MPN PMEG3010CEJ
J1: TAG-10PIN; Tag-Connect_TC2050-IDC-NL
Q1: DMG1013UWQ-7; SOT-323; MPN DMG1013UWQ-7
R18, R22: 4x33R_0201_array; EXB18V; MPN EXB-18V330JX
R19: R_1k_0402; 0402-res; MPN CR0402-FX-1001GLF
R21: R_4k7_0402; 0402-res; MPN ERJ2GEJ472X
R50, R51, R52, R53, R54, R109, R110, R111, R112, R113, R114, R115, R116: R_10k_0201; 0201-res; MPN RC0201FR-0710KL
R98, R100: R_1M0_0402; 0402-res; MPN CRG0402F1M0
R101, R102: R_0R_0402; 0402-res; MPN ERJ2GE0R00X
R127: R_100k_0402; 0402-res; MPN CRCW0402100KFKEDHP
R128: R_33R_0402; 0402-res; MPN CRCW040233R0FKED
TP13, TP14, TP15, TP16: TP_SMD_0_75MM; Testpoint_smd_0_75mm
TP17, TP18, TP19: TP_SMD1MM; Testpoint_smd_1mm
U2: GD25LQ256DWIGR; GD25Q16CWIG; MPN GD25LQ256DWIGR
U7: STM811RW16F; SOT-143-4
U13: VIC7100; vic7100; MPN VIC7100
Y2: ABM8G-25.000MHZ-18-D2Y-T; KX-7; MPN ABM8G-25.000MHZ-18-D2Y-T
Y3: ABM8G-27.000MHZ-18-D2Y-T; KX-7; MPN ABM8G-27.000MHZ-18-D2Y-T

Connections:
/VIC7100 config/ATEMP_TEST0: R51.1, TP13.1, U13.U25 (ANA18_TEMP_TEST0)
/VIC7100 config/ATEMP_TEST1: R50.1, TP14.1, U13.U24 (ANA18_TEMP_TEST1)
/VIC7100 config/ATEMP_VCAL: TP16.1, U13.V24 (ANA18_TEMP_VSS)
/VIC7100 config/ATEMP_VSS: TP15.1, U13.V25 (ANA18_TEMP_VCAL)
BOOT_FROM_UARTn: R128.1; also elsewhere on the board
BOOT_MODE: R115.2, R116.1, U13.M28 (GPIO[63])
BOOT_SEL0: R109.2, R110.1, U13.E31 (GPIO[60])
BOOT_SEL1: R111.2, R112.1, U13.F31 (GPIO[61])
BOOT_SEL2: Q1.3 (D), R113.2, R114.1, U13.F30 (GPIO[62])
CLK_25M_IN: R98.1, R101.1, U13.Y30 (OSC0_XIN)
CLK_25M_OUT: C244.1, R98.2, U13.Y31 (OSC0_XOUT), Y2.3
CLK_27M_IN: R100.1, R102.1, U13.V30 (OSC1_XIN)
CLK_27M_OUT: C246.1, R100.2, U13.V31 (OSC1_XOUT), Y3.3
GND: C35.2, C36.2, C171.2, C172.2, C243.2, C244.2, C245.2, C246.2, J1.3, J1.5, J1.9, R50.2, R51.2, R53.2, R110.2, R112.2, R114.2, R116.2, TP19.1, U2.4 (VSS), U7.1 (VSS), U13.AB22 (VSS18_OTP), U13.D27 (GPIO[48]), U13.D28 (GPIO[50]), U13.D29 (GPIO[49]), U13.D30 (GPIO[52]), U13.D31 (GPIO[55]), U13.E29 (GPIO[54]), U13.E30 (GPIO[57]), U13.F29 (GPIO[59]), U13.L28 (GPIO[51]), U13.M25 (GPIO[53]), U13.M26 (GPIO[56]), U13.M27 (GPIO[58]), U13.W24 (VSS18_TS), Y2.2, Y2.4, Y3.2, Y3.4; also elsewhere on the board
JTAG_TCK: J1.4, U13.H22 (GPIO[1])
JTAG_TDI: J1.8, U13.C25 (GPIO[2])
JTAG_TDO: J1.6, U13.A25 (GPIO[0])
JTAG_TMS: J1.2, U13.A26 (GPIO[3])
JTAG_TRSTN: J1.10, U13.G23 (GPIO[4])
unnamed: C243.1, R101.2, Y2.1
unnamed: C245.1, R102.2, Y3.1
unnamed: D7.K, TP18.1
unnamed: Q1.1 (G), R127.2, R128.2
unnamed: R18.6, U2.3 (~WP~/IO2)
unnamed: R18.7, U2.2 (SO/IO1)
unnamed: R18.8, R21.2, U2.1 (~CS)
unnamed: R22.1, U2.7 (~HOLD~/IO3)
unnamed: R22.2, U2.6 (SCLK)
unnamed: R22.3, U2.5 (SI/IO0)
QSPI_CLK: R22.7, U13.R25 (QSPI_CLK)
QSPI_CS0_N: R18.1, U13.P27 (QSPI_CSN0)
QSPI_D0: R22.6, U13.R26 (QSPI_DATA[0])
QSPI_D1: R18.2, U13.R27 (QSPI_DATA[1])
QSPI_D2: R18.3, U13.P26 (QSPI_DATA[2])
QSPI_D3: R22.8, U13.P25 (QSPI_DATA[3])
SYS_RSTN: D5.K, U7.3 (~MR); also elsewhere on the board
TEST_MODE: R52.2, R53.1, U13.M29 (TEST_MODE)
UART3_RXD_1V8: TP17.1, U13.H24 (GPIO[13])
UART3_TXD_1V8: D7.A, R19.1, U13.E26 (GPIO[14])
VCC_1V8: C35.1, C36.1, J1.1, Q1.2 (S), R19.2, R21.1, R52.1, R54.1, R109.1, R111.1, R113.1, R115.1, R127.1, U2.8 (VCC), U13.AB21 (DVDD18_OTP), U13.W23 (AVDD18_TS); also elsewhere on the board
VCC_3V3: C171.1, U7.4 (VCC); also elsewhere on the board
VDD2PEN_OTP_1V8: U13.AC21 (ANA18_OTP_PENVDD2); also elsewhere on the board
VIC_RSTN: C172.1, D5.A, R54.2, U7.2 (~RST), U13.L29 (EXT_RSTN)

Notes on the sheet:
NOR Flash
VIC7100 configuration
Test mode enable for DFT (active high)
Clock crystals
JTAG connector (1V8)
Boot config
VIC reset
UART3 (1V8)

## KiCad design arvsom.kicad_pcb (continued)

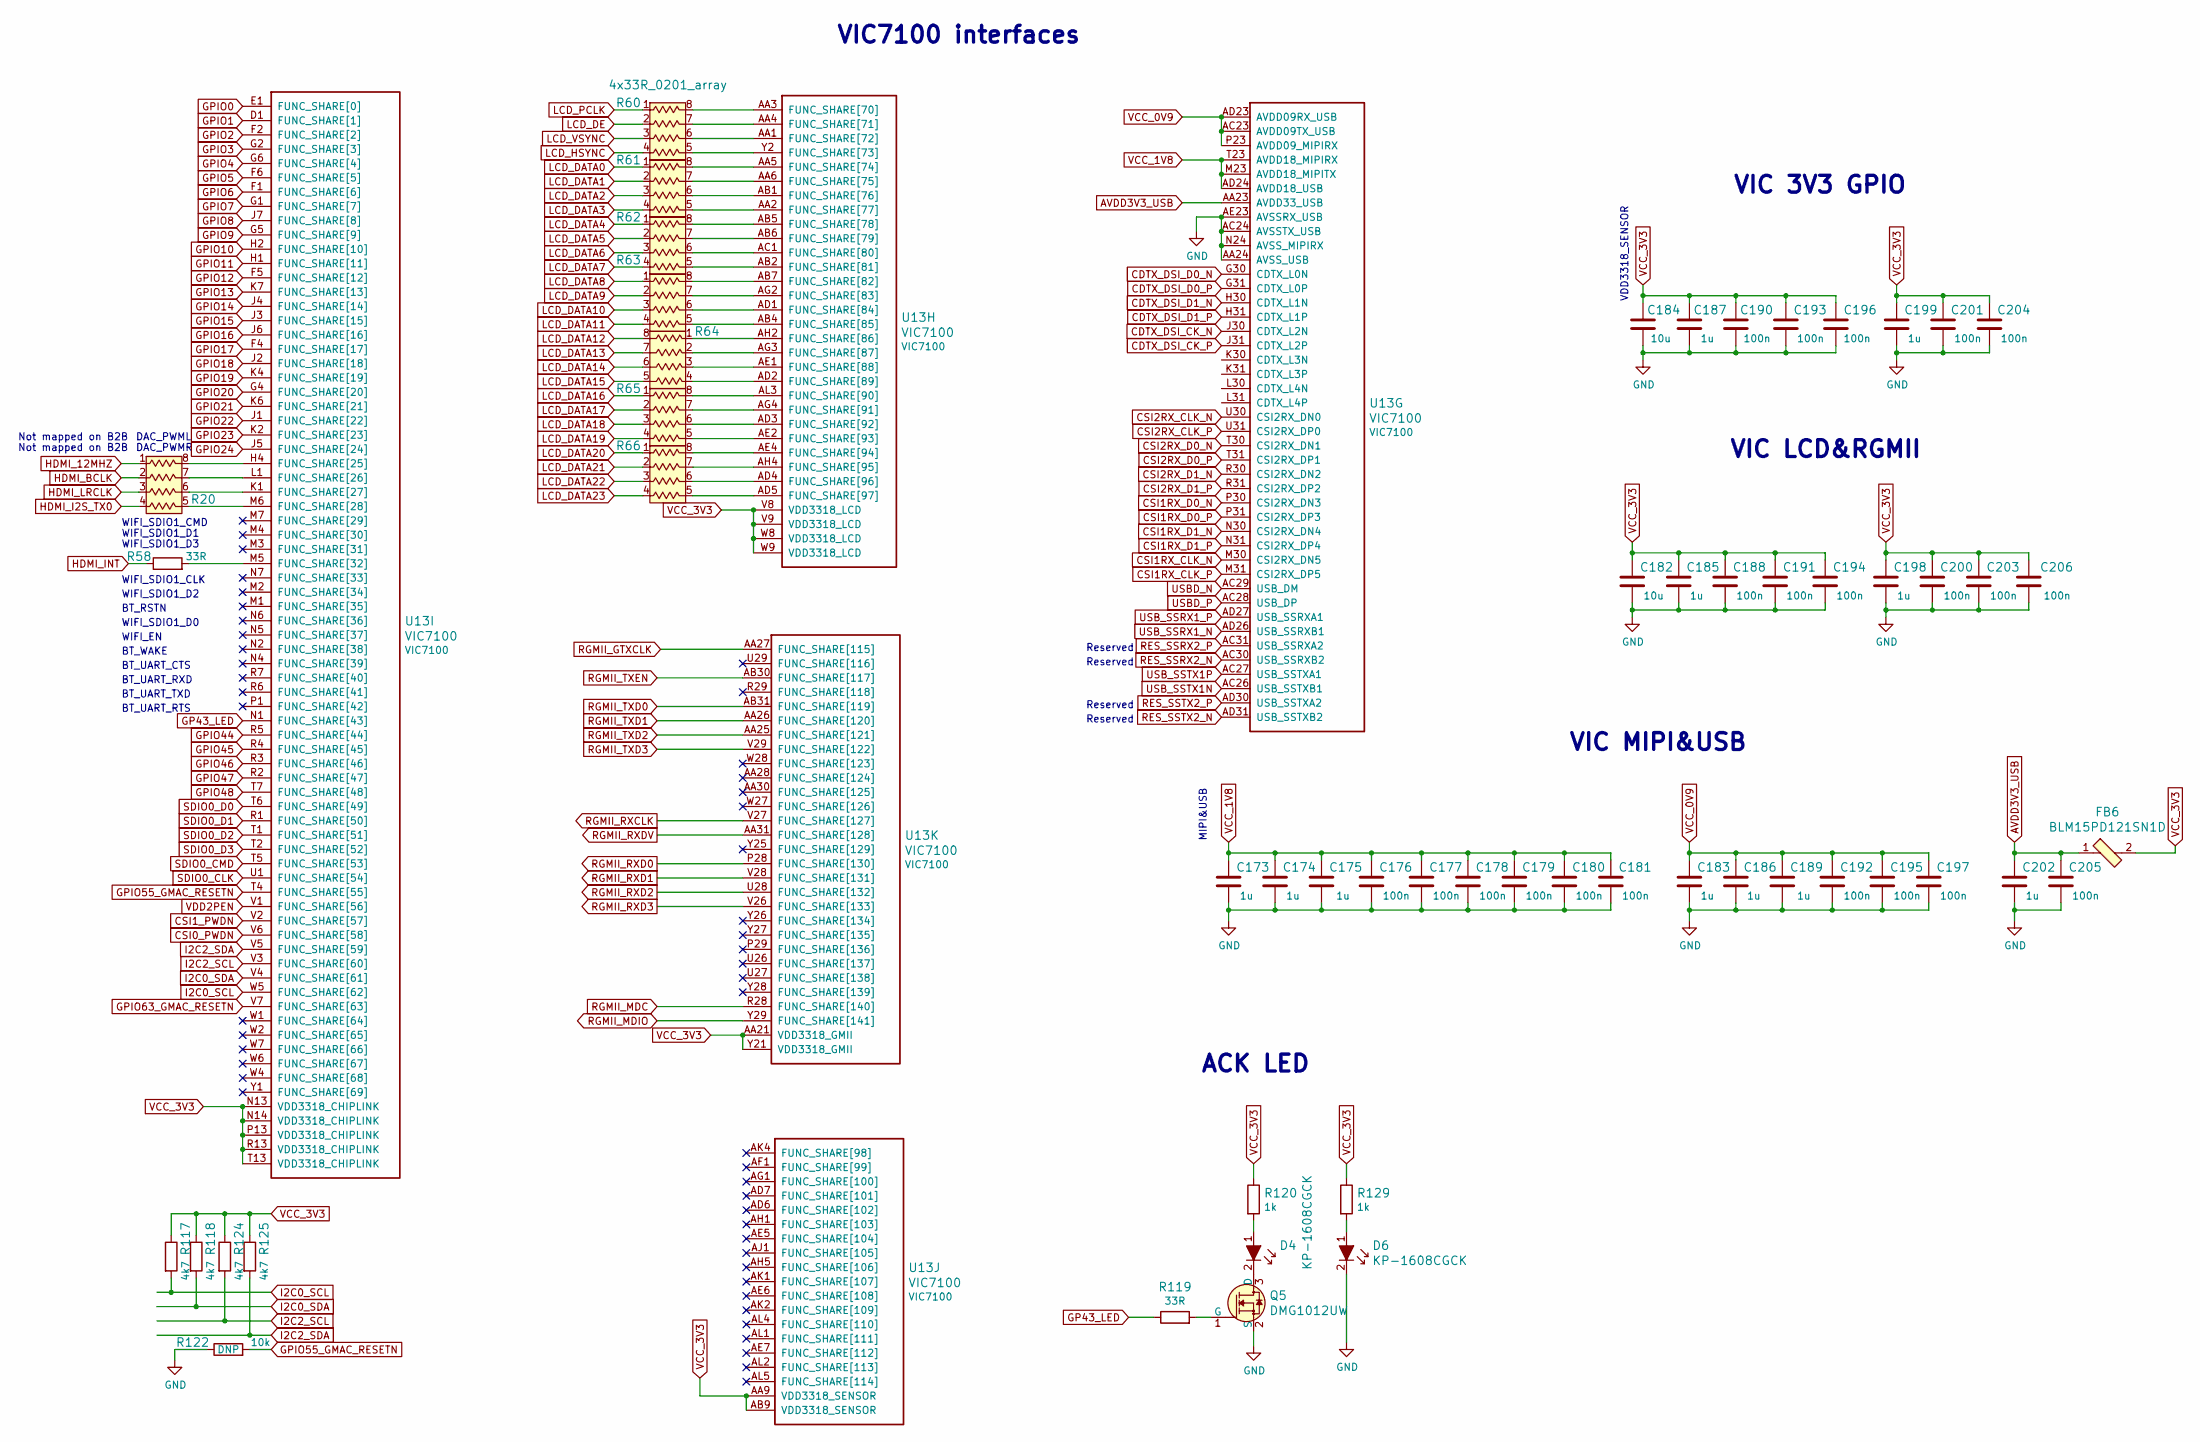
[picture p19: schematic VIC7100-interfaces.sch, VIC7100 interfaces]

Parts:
C173, C174, C175, C183, C185, C186, C187, C189, C198, C199, C202: C_1u_0402; 0402-cap; MPN C1005X6S1A105K050BC
C176, C177, C178, C179, C180, C181, C188, C190, C191, C192, C193, C194, C195, C196, C197, C200, C201, C203, C204, C205, C206: C_100n_0201; 0201-res; MPN CC0201KRX6S5BB104
C182, C184: C_10u_0402; 0402-cap; MPN GRM155R60J106ME44D
D4, D6: KP-1608CGCK; LED_0603; MPN KP-1608CGCK
FB6: BLM15PD121SN1D; 0402-res; MPN BLM15PD121SN1D
Q5: DMG1012UW; SOT-323; MPN DMG1012UW
R20, R60, R61, R62, R63, R64, R65, R66: 4x33R_0201_array; EXB18V; MPN EXB-18V330JX
R58, R119: R_33R_0402; 0402-res; MPN CRCW040233R0FKED
R117, R118, R124, R125: R_4k7_0402; 0402-res; MPN ERJ2GEJ472X
R120, R129: R_1k_0402; 0402-res; MPN CR0402-FX-1001GLF
R122: R_10k_0201; 0201-res; MPN RC0201FR-0710KL
U13: VIC7100; vic7100; MPN VIC7100

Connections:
AVDD3V3_USB: C202.1, C205.1, FB6.1, U13.AA23 (AVDD33_USB)
CDTX_DSI_CK_N: U13.J30 (CDTX_L2N); also elsewhere on the board
CDTX_DSI_CK_P: U13.J31 (CDTX_L2P); also elsewhere on the board
CDTX_DSI_D0_N: U13.G30 (CDTX_L0N); also elsewhere on the board
CDTX_DSI_D0_P: U13.G31 (CDTX_L0P); also elsewhere on the board
CDTX_DSI_D1_N: U13.H30 (CDTX_L1N); also elsewhere on the board
CDTX_DSI_D1_P: U13.H31 (CDTX_L1P); also elsewhere on the board
CSI0_PWDN: U13.V6 (FUNC_SHARE[58]); also elsewhere on the board
CSI1RX_CLK_N: U13.M30 (CSI2RX_DN5); also elsewhere on the board
CSI1RX_CLK_P: U13.M31 (CSI2RX_DP5); also elsewhere on the board
CSI1RX_D0_N: U13.P30 (CSI2RX_DN3); also elsewhere on the board
CSI1RX_D0_P: U13.P31 (CSI2RX_DP3); also elsewhere on the board
CSI1RX_D1_N: U13.N30 (CSI2RX_DN4); also elsewhere on the board
CSI1RX_D1_P: U13.N31 (CSI2RX_DP4); also elsewhere on the board
CSI1_PWDN: U13.V2 (FUNC_SHARE[57])
CSI2RX_CLK_N: U13.U30 (CSI2RX_DN0); also elsewhere on the board
CSI2RX_CLK_P: U13.U31 (CSI2RX_DP0); also elsewhere on the board
CSI2RX_D0_N: U13.T30 (CSI2RX_DN1); also elsewhere on the board
CSI2RX_D0_P: U13.T31 (CSI2RX_DP1); also elsewhere on the board
CSI2RX_D1_N: U13.R30 (CSI2RX_DN2); also elsewhere on the board
CSI2RX_D1_P: U13.R31 (CSI2RX_DP2); also elsewhere on the board
GND: C173.2, C174.2, C175.2, C176.2, C177.2, C178.2, C179.2, C180.2, C181.2, C182.2, C183.2, C184.2, C185.2, C186.2, C187.2, C188.2, C189.2, C190.2, C191.2, C192.2, C193.2, C194.2, C195.2, C196.2, C197.2, C198.2, C199.2, C200.2, C201.2, C202.2, C203.2, C204.2, C205.2, C206.2, D6.2, Q5.2 (S), R122.1, U13.AA24 (AVSS_USB), U13.AC24 (AVSSTX_USB), U13.AE23 (AVSSRX_USB), U13.N24 (AVSS_MIPIRX); also elsewhere on the board
GP43_LED: R119.1, U13.N1 (FUNC_SHARE[43]); also elsewhere on the board
GPIO0: U13.E1 (FUNC_SHARE[0]); also elsewhere on the board
GPIO1: U13.D1 (FUNC_SHARE[1]); also elsewhere on the board
GPIO2: U13.F2 (FUNC_SHARE[2]); also elsewhere on the board
GPIO3: U13.G2 (FUNC_SHARE[3]); also elsewhere on the board
GPIO4: U13.G6 (FUNC_SHARE[4]); also elsewhere on the board
GPIO5: U13.F6 (FUNC_SHARE[5]); also elsewhere on the board
GPIO6: U13.F1 (FUNC_SHARE[6]); also elsewhere on the board
GPIO7: U13.G1 (FUNC_SHARE[7]); also elsewhere on the board
GPIO8: U13.J7 (FUNC_SHARE[8]); also elsewhere on the board
GPIO9: U13.G5 (FUNC_SHARE[9]); also elsewhere on the board
GPIO10: U13.H2 (FUNC_SHARE[10]); also elsewhere on the board
GPIO11: U13.H1 (FUNC_SHARE[11]); also elsewhere on the board
GPIO12: U13.F5 (FUNC_SHARE[12]); also elsewhere on the board
GPIO13: U13.K7 (FUNC_SHARE[13]); also elsewhere on the board
GPIO14: U13.J4 (FUNC_SHARE[14]); also elsewhere on the board
GPIO15: U13.J3 (FUNC_SHARE[15]); also elsewhere on the board
GPIO16: U13.J6 (FUNC_SHARE[16]); also elsewhere on the board
GPIO17: U13.F4 (FUNC_SHARE[17]); also elsewhere on the board
GPIO18: U13.J2 (FUNC_SHARE[18]); also elsewhere on the board
GPIO19: U13.K4 (FUNC_SHARE[19]); also elsewhere on the board
GPIO20: U13.G4 (FUNC_SHARE[20]); also elsewhere on the board
GPIO21: U13.K6 (FUNC_SHARE[21]); also elsewhere on the board
GPIO22: U13.J1 (FUNC_SHARE[22]); also elsewhere on the board
GPIO23: U13.K2 (FUNC_SHARE[23])
GPIO24: U13.J5 (FUNC_SHARE[24])
GPIO44: U13.R5 (FUNC_SHARE[44]); also elsewhere on the board
GPIO45: U13.R4 (FUNC_SHARE[45]); also elsewhere on the board
GPIO46: U13.R3 (FUNC_SHARE[46]); also elsewhere on the board
GPIO47: U13.R2 (FUNC_SHARE[47]); also elsewhere on the board
GPIO48: U13.T7 (FUNC_SHARE[48]); also elsewhere on the board
GPIO55_GMAC_RESETN: R122.2, U13.T4 (FUNC_SHARE[55])
GPIO63_GMAC_RESETN: U13.V7 (FUNC_SHARE[63]); also elsewhere on the board
HDMI_12MHZ: R20.1; also elsewhere on the board
HDMI_BCLK: R20.2; also elsewhere on the board
HDMI_I2S_TX0: R20.4; also elsewhere on the board
HDMI_INT: R58.1; also elsewhere on the board
HDMI_LRCLK: R20.3; also elsewhere on the board
I2C0_SCL: R117.2, U13.W5 (FUNC_SHARE[62]); also elsewhere on the board
I2C0_SDA: R118.2, U13.V4 (FUNC_SHARE[61]); also elsewhere on the board
I2C2_SCL: R124.2, U13.V3 (FUNC_SHARE[60]); also elsewhere on the board
I2C2_SDA: R125.2, U13.V5 (FUNC_SHARE[59]); also elsewhere on the board
LCD_DATA0: R61.1; also elsewhere on the board
LCD_DATA1: R61.2; also elsewhere on the board
LCD_DATA2: R61.3; also elsewhere on the board
LCD_DATA3: R61.4; also elsewhere on the board
LCD_DATA4: R62.1; also elsewhere on the board
LCD_DATA5: R62.2; also elsewhere on the board
LCD_DATA6: R62.3; also elsewhere on the board
LCD_DATA7: R62.4; also elsewhere on the board
LCD_DATA8: R63.1; also elsewhere on the board
LCD_DATA9: R63.2; also elsewhere on the board
LCD_DATA10: R63.3; also elsewhere on the board
LCD_DATA11: R63.4; also elsewhere on the board
LCD_DATA12: R64.8; also elsewhere on the board
LCD_DATA13: R64.7; also elsewhere on the board
LCD_DATA14: R64.6; also elsewhere on the board
LCD_DATA15: R64.5; also elsewhere on the board
LCD_DATA16: R65.1; also elsewhere on the board
LCD_DATA17: R65.2; also elsewhere on the board
LCD_DATA18: R65.3; also elsewhere on the board
LCD_DATA19: R65.4; also elsewhere on the board
LCD_DATA20: R66.1; also elsewhere on the board
LCD_DATA21: R66.2; also elsewhere on the board
LCD_DATA22: R66.3; also elsewhere on the board
LCD_DATA23: R66.4; also elsewhere on the board
LCD_DE: R60.2; also elsewhere on the board
LCD_HSYNC: R60.4; also elsewhere on the board
LCD_PCLK: R60.1; also elsewhere on the board
LCD_VSYNC: R60.3; also elsewhere on the board
unnamed: D4.1, R120.2
unnamed: D4.2, Q5.3 (D)
unnamed: D6.1, R129.2
unnamed: Q5.1 (G), R119.2
unnamed: R20.5, U13.M6 (FUNC_SHARE[28])
unnamed: R20.6, U13.K1 (FUNC_SHARE[27])
unnamed: R20.7, U13.L1 (FUNC_SHARE[26])
unnamed: R20.8, U13.H4 (FUNC_SHARE[25])
unnamed: R58.2, U13.M5 (FUNC_SHARE[32])
unnamed: R60.5, U13.Y2 (FUNC_SHARE[73])
unnamed: R60.6, U13.AA1 (FUNC_SHARE[72])
unnamed: R60.7, U13.AA4 (FUNC_SHARE[71])
unnamed: R60.8, U13.AA3 (FUNC_SHARE[70])
unnamed: R61.5, U13.AA2 (FUNC_SHARE[77])
unnamed: R61.6, U13.AB1 (FUNC_SHARE[76])
unnamed: R61.7, U13.AA6 (FUNC_SHARE[75])
unnamed: R61.8, U13.AA5 (FUNC_SHARE[74])
unnamed: R62.5, U13.AB2 (FUNC_SHARE[81])
unnamed: R62.6, U13.AC1 (FUNC_SHARE[80])
unnamed: R62.7, U13.AB6 (FUNC_SHARE[79])
unnamed: R62.8, U13.AB5 (FUNC_SHARE[78])
unnamed: R63.5, U13.AB4 (FUNC_SHARE[85])
unnamed: R63.6, U13.AD1 (FUNC_SHARE[84])
unnamed: R63.7, U13.AG2 (FUNC_SHARE[83])
unnamed: R63.8, U13.AB7 (FUNC_SHARE[82])
unnamed: R64.1, U13.AH2 (FUNC_SHARE[86])
unnamed: R64.2, U13.AG3 (FUNC_SHARE[87])
unnamed: R64.3, U13.AE1 (FUNC_SHARE[88])
unnamed: R64.4, U13.AD2 (FUNC_SHARE[89])
unnamed: R65.5, U13.AE2 (FUNC_SHARE[93])
unnamed: R65.6, U13.AD3 (FUNC_SHARE[92])
unnamed: R65.7, U13.AG4 (FUNC_SHARE[91])
unnamed: R65.8, U13.AL3 (FUNC_SHARE[90])
unnamed: R66.5, U13.AD5 (FUNC_SHARE[97])
unnamed: R66.6, U13.AD4 (FUNC_SHARE[96])
unnamed: R66.7, U13.AH4 (FUNC_SHARE[95])
unnamed: R66.8, U13.AE4 (FUNC_SHARE[94])
RES_SSRX2_N: U13.AC30 (USB_SSRXB2); also elsewhere on the board
RES_SSRX2_P: U13.AC31 (USB_SSRXA2); also elsewhere on the board
RES_SSTX2_N: U13.AD31 (USB_SSTXB2); also elsewhere on the board
RES_SSTX2_P: U13.AD30 (USB_SSTXA2); also elsewhere on the board
RGMII_GTXCLK: U13.AA27 (FUNC_SHARE[115]); also elsewhere on the board
RGMII_MDC: U13.R28 (FUNC_SHARE[140]); also elsewhere on the board
RGMII_MDIO: U13.Y29 (FUNC_SHARE[141]); also elsewhere on the board
RGMII_RXCLK: U13.V27 (FUNC_SHARE[127]); also elsewhere on the board
RGMII_RXD0: U13.P28 (FUNC_SHARE[130]); also elsewhere on the board
RGMII_RXD1: U13.V28 (FUNC_SHARE[131]); also elsewhere on the board
RGMII_RXD2: U13.U28 (FUNC_SHARE[132]); also elsewhere on the board
RGMII_RXD3: U13.V26 (FUNC_SHARE[133]); also elsewhere on the board
RGMII_RXDV: U13.AA31 (FUNC_SHARE[128]); also elsewhere on the board
RGMII_TXD0: U13.AB31 (FUNC_SHARE[119]); also elsewhere on the board
RGMII_TXD1: U13.AA26 (FUNC_SHARE[120]); also elsewhere on the board
RGMII_TXD2: U13.AA25 (FUNC_SHARE[121]); also elsewhere on the board
RGMII_TXD3: U13.V29 (FUNC_SHARE[122]); also elsewhere on the board
RGMII_TXEN: U13.AB30 (FUNC_SHARE[117]); also elsewhere on the board
SDIO0_CLK: U13.U1 (FUNC_SHARE[54]); also elsewhere on the board
SDIO0_CMD: U13.T5 (FUNC_SHARE[53]); also elsewhere on the board
SDIO0_D0: U13.T6 (FUNC_SHARE[49]); also elsewhere on the board
SDIO0_D1: U13.R1 (FUNC_SHARE[50]); also elsewhere on the board
SDIO0_D2: U13.T1 (FUNC_SHARE[51]); also elsewhere on the board
SDIO0_D3: U13.T2 (FUNC_SHARE[52]); also elsewhere on the board
USBD_N: U13.AC29 (USB_DM); also elsewhere on the board
USBD_P: U13.AC28 (USB_DP); also elsewhere on the board
USB_SSRX1_N: U13.AD26 (USB_SSRXB1); also elsewhere on the board
USB_SSRX1_P: U13.AD27 (USB_SSRXA1); also elsewhere on the board
USB_SSTX1N: U13.AC26 (USB_SSTXB1); also elsewhere on the board
USB_SSTX1P: U13.AC27 (USB_SSTXA1); also elsewhere on the board
VCC_0V9: C183.1, C186.1, C189.1, C192.1, C195.1, C197.1, U13.AC23 (AVDD09TX_USB), U13.AD23 (AVDD09RX_USB), U13.P23 (AVDD09_MIPIRX); also elsewhere on the board
VCC_1V8: C173.1, C174.1, C175.1, C176.1, C177.1, C178.1, C179.1, C180.1, C181.1, U13.AD24 (AVDD18_USB), U13.M23 (AVDD18_MIPITX), U13.T23 (AVDD18_MIPIRX); also elsewhere on the board
VCC_3V3: C182.1, C184.1, C185.1, C187.1, C188.1, C190.1, C191.1, C193.1, C194.1, C196.1, C198.1, C199.1, C200.1, C201.1, C203.1, C204.1, C206.1, FB6.2, R117.1, R118.1, R120.1, R124.1, R125.1, R129.1, U13.AA9 (VDD3318_SENSOR), U13.AA21 (VDD3318_GMII), U13.AB9 (VDD3318_SENSOR), U13.N13 (VDD3318_CHIPLINK), U13.N14 (VDD3318_CHIPLINK), U13.P13 (VDD3318_CHIPLINK), U13.R13 (VDD3318_CHIPLINK), U13.T13 (VDD3318_CHIPLINK), U13.V8 (VDD3318_LCD), U13.V9 (VDD3318_LCD), U13.W8 (VDD3318_LCD), U13.W9 (VDD3318_LCD), U13.Y21 (VDD3318_GMII); also elsewhere on the board
VDD2PEN: U13.V1 (FUNC_SHARE[56]); also elsewhere on the board

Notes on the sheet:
VDD3318_SENSOR
MIPI&USB
VIC 3V3 GPIO
VIC LCD&RGMII
VIC MIPI&USB
VIC7100 interfaces
WIFI_SDIO1_CMD
WIFI_SDIO1_D1
WIFI_SDIO1_D3
BT_WAKE
WIFI_SDIO1_CLK
WIFI_SDIO1_D2
WIFI_SDIO1_D0
BT_UART_CTS
BT_UART_RXD
BT_UART_TXD
BT_UART_RTS
WIFI_EN
BT_RSTN
ACK LED
DAC_PWML
DAC_PWMR
Not mapped on B2B
Reserved

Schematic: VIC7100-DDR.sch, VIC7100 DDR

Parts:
R88, R90: R_10k_0201; 0201-res; MPN RC0201FR-0710KL
R89, R91: R_240R_0402; 0402-res; MPN ERJ2GEJ241X
TP5, TP6, TP7, TP8, TP9, TP10, TP11, TP12: TP_SMD_0_75MM; Testpoint_smd_0_75mm
U13: VIC7100; vic7100; MPN VIC7100

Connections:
DDR0_A00: U13.C10 (DDR0_ADR[0]); also elsewhere on the board
DDR0_A01: U13.B10 (DDR0_ADR[1]); also elsewhere on the board
DDR0_A02: U13.A15 (DDR0_ADR[2]); also elsewhere on the board
DDR0_A03: U13.D10 (DDR0_ADR[3]); also elsewhere on the board
DDR0_A04: U13.D12 (DDR0_ADR[4]); also elsewhere on the board
DDR0_A05: U13.E10 (DDR0_ADR[5]); also elsewhere on the board
DDR0_CK0_N: U13.B14 (DDR0_CK_N[0]); also elsewhere on the board
DDR0_CK0_P: U13.A14 (DDR0_CK_P[0]); also elsewhere on the board
DDR0_CK1_N: U13.B12 (DDR0_CK_N[1]); also elsewhere on the board
DDR0_CK1_P: U13.A12 (DDR0_CK_P[1]); also elsewhere on the board
DDR0_CKE0: U13.C17 (DDR0_CKE[0]); also elsewhere on the board
DDR0_CKE1: U13.F17 (DDR0_CKE[1]); also elsewhere on the board
DDR0_CS0: U13.F19 (DDR0_CS_N[0]); also elsewhere on the board
DDR0_CS1: U13.A17 (DDR0_CS_N[1]); also elsewhere on the board
DDR0_CS2: U13.B17 (DDR0_CS_N[2]); also elsewhere on the board
DDR0_CS3: U13.E14 (DDR0_CS_N[3]); also elsewhere on the board
DDR0_DMI0: U13.E22 (DDR0_DM_DBI_N[0]); also elsewhere on the board
DDR0_DMI1: U13.C19 (DDR0_DM_DBI_N[1]); also elsewhere on the board
DDR0_DMI2: U13.D6 (DDR0_DM_DBI_N[2]); also elsewhere on the board
DDR0_DMI3: U13.D4 (DDR0_DM_DBI_N[3]); also elsewhere on the board
DDR0_DQ00: U13.F23 (DDR0_DQ[0]); also elsewhere on the board
DDR0_DQ01: U13.E23 (DDR0_DQ[1]); also elsewhere on the board
DDR0_DQ02: U13.D22 (DDR0_DQ[2]); also elsewhere on the board
DDR0_DQ03: U13.F22 (DDR0_DQ[3]); also elsewhere on the board
DDR0_DQ04: U13.C22 (DDR0_DQ[4]); also elsewhere on the board
DDR0_DQ05: U13.B22 (DDR0_DQ[5]); also elsewhere on the board
DDR0_DQ06: U13.A23 (DDR0_DQ[6]); also elsewhere on the board
DDR0_DQ07: U13.A22 (DDR0_DQ[7]); also elsewhere on the board
DDR0_DQ08: U13.A21 (DDR0_DQ[8]); also elsewhere on the board
DDR0_DQ09: U13.C20 (DDR0_DQ[9]); also elsewhere on the board
DDR0_DQ10: U13.E20 (DDR0_DQ[10]); also elsewhere on the board
DDR0_DQ11: U13.D20 (DDR0_DQ[11]); also elsewhere on the board
DDR0_DQ12: U13.E19 (DDR0_DQ[12]); also elsewhere on the board
DDR0_DQ13: U13.D19 (DDR0_DQ[13]); also elsewhere on the board
DDR0_DQ14: U13.B19 (DDR0_DQ[14]); also elsewhere on the board
DDR0_DQ15: U13.A19 (DDR0_DQ[15]); also elsewhere on the board
DDR0_DQ16: U13.A5 (DDR0_DQ[16]); also elsewhere on the board
DDR0_DQ17: U13.D7 (DDR0_DQ[17]); also elsewhere on the board
DDR0_DQ18: U13.C7 (DDR0_DQ[18]); also elsewhere on the board
DDR0_DQ19: U13.E7 (DDR0_DQ[19]); also elsewhere on the board
DDR0_DQ20: U13.B5 (DDR0_DQ[20]); also elsewhere on the board
DDR0_DQ21: U13.C6 (DDR0_DQ[21]); also elsewhere on the board
DDR0_DQ22: U13.E6 (DDR0_DQ[22]); also elsewhere on the board
DDR0_DQ23: U13.B4 (DDR0_DQ[23]); also elsewhere on the board
DDR0_DQ24: U13.A2 (DDR0_DQ[24]); also elsewhere on the board
DDR0_DQ25: U13.B3 (DDR0_DQ[25]); also elsewhere on the board
DDR0_DQ26: U13.A3 (DDR0_DQ[26]); also elsewhere on the board
DDR0_DQ27: U13.C4 (DDR0_DQ[27]); also elsewhere on the board
DDR0_DQ28: U13.B2 (DDR0_DQ[28]); also elsewhere on the board
DDR0_DQ29: U13.B1 (DDR0_DQ[29]); also elsewhere on the board
DDR0_DQ30: U13.A1 (DDR0_DQ[30]); also elsewhere on the board
DDR0_DQ31: U13.C2 (DDR0_DQ[31]); also elsewhere on the board
DDR0_DQS0N: U13.C23 (DDR0_DQS_N[0]); also elsewhere on the board
DDR0_DQS0P: U13.B23 (DDR0_DQS_P[0]); also elsewhere on the board
DDR0_DQS1N: U13.A20 (DDR0_DQS_N[1]); also elsewhere on the board
DDR0_DQS1P: U13.B20 (DDR0_DQS_P[1]); also elsewhere on the board
DDR0_DQS2N: U13.B6 (DDR0_DQS_N[2]); also elsewhere on the board
DDR0_DQS2P: U13.A6 (DDR0_DQS_P[2]); also elsewhere on the board
DDR0_DQS3N: U13.C3 (DDR0_DQS_N[3]); also elsewhere on the board
DDR0_DQS3P: U13.D3 (DDR0_DQS_P[3]); also elsewhere on the board
DDR0_ODT0: U13.D17 (DDR0_ODT[0]); also elsewhere on the board
DDR0_ODT1: U13.G17 (DDR0_ODT[1]); also elsewhere on the board
DDR0_PLL_REFOUT_N: TP5.1, U13.D16 (DDR0_PLL_REFOUT_N)
DDR0_PLL_REFOUT_P: TP6.1, U13.E16 (DDR0_PLL_REFOUT_P)
DDR0_PLL_TESTOUT_N: TP7.1, U13.H19 (DDR0_PLL_TESTOUT_N)
DDR0_PLL_TESTOUT_P: TP8.1, U13.G19 (DDR0_PLL_TESTOUT_P)
DDR0_RSTN: U13.B18 (DDR0_RESET_N); also elsewhere on the board
DDR1_A00: U13.AG16 (DDR1_ADR[0]); also elsewhere on the board
DDR1_A01: U13.AJ18 (DDR1_ADR[1]); also elsewhere on the board
DDR1_A02: U13.AJ16 (DDR1_ADR[2]); also elsewhere on the board
DDR1_A03: U13.AF14 (DDR1_ADR[3]); also elsewhere on the board
DDR1_A04: U13.AL14 (DDR1_ADR[4]); also elsewhere on the board
DDR1_A05: U13.AG14 (DDR1_ADR[5]); also elsewhere on the board
DDR1_CK0_N: U13.AK18 (DDR1_CK_N[0]); also elsewhere on the board
DDR1_CK0_P: U13.AL18 (DDR1_CK_P[0]); also elsewhere on the board
DDR1_CK1_N: U13.AK16 (DDR1_CK_N[1]); also elsewhere on the board
DDR1_CK1_P: U13.AL16 (DDR1_CK_P[1]); also elsewhere on the board
DDR1_CKE0: U13.AG23 (DDR1_CKE[0]); also elsewhere on the board
DDR1_CKE1: U13.AJ24 (DDR1_CKE[1]); also elsewhere on the board
DDR1_CS0: U13.AK23 (DDR1_CS_N[0]); also elsewhere on the board
DDR1_CS1: U13.AH21 (DDR1_CS_N[1]); also elsewhere on the board
DDR1_CS2: U13.AH20 (DDR1_CS_N[2]); also elsewhere on the board
DDR1_CS3: U13.AF20 (DDR1_CS_N[3]); also elsewhere on the board
DDR1_DMI0: U13.AG30 (DDR1_DM_DBI_N[0]); also elsewhere on the board
DDR1_DMI1: U13.AJ26 (DDR1_DM_DBI_N[1]); also elsewhere on the board
DDR1_DMI2: U13.AG11 (DDR1_DM_DBI_N[2]); also elsewhere on the board
DDR1_DMI3: U13.AH8 (DDR1_DM_DBI_N[3]); also elsewhere on the board
DDR1_DQ00: U13.AF29 (DDR1_DQ[0]); also elsewhere on the board
DDR1_DQ01: U13.AG29 (DDR1_DQ[1]); also elsewhere on the board
DDR1_DQ02: U13.AH30 (DDR1_DQ[2]); also elsewhere on the board
DDR1_DQ03: U13.AF30 (DDR1_DQ[3]); also elsewhere on the board
DDR1_DQ04: U13.AJ29 (DDR1_DQ[4]); also elsewhere on the board
DDR1_DQ05: U13.AK29 (DDR1_DQ[5]); also elsewhere on the board
DDR1_DQ06: U13.AL30 (DDR1_DQ[6]); also elsewhere on the board
DDR1_DQ07: U13.AL29 (DDR1_DQ[7]); also elsewhere on the board
DDR1_DQ08: U13.AF26 (DDR1_DQ[8]); also elsewhere on the board
DDR1_DQ09: U13.AH27 (DDR1_DQ[9]); also elsewhere on the board
DDR1_DQ10: U13.AG27 (DDR1_DQ[10]); also elsewhere on the board
DDR1_DQ11: U13.AG26 (DDR1_DQ[11]); also elsewhere on the board
DDR1_DQ12: U13.AL27 (DDR1_DQ[12]); also elsewhere on the board
DDR1_DQ13: U13.AL26 (DDR1_DQ[13]); also elsewhere on the board
DDR1_DQ14: U13.AF24 (DDR1_DQ[14]); also elsewhere on the board
DDR1_DQ15: U13.AF23 (DDR1_DQ[15]); also elsewhere on the board
DDR1_DQ16: U13.AL11 (DDR1_DQ[16]); also elsewhere on the board
DDR1_DQ17: U13.AK11 (DDR1_DQ[17]); also elsewhere on the board
DDR1_DQ18: U13.AL10 (DDR1_DQ[18]); also elsewhere on the board
DDR1_DQ19: U13.AJ11 (DDR1_DQ[19]); also elsewhere on the board
DDR1_DQ20: U13.AG10 (DDR1_DQ[20]); also elsewhere on the board
DDR1_DQ21: U13.AH11 (DDR1_DQ[21]); also elsewhere on the board
DDR1_DQ22: U13.AF11 (DDR1_DQ[22]); also elsewhere on the board
DDR1_DQ23: U13.AF10 (DDR1_DQ[23]); also elsewhere on the board
DDR1_DQ24: U13.AL8 (DDR1_DQ[24]); also elsewhere on the board
DDR1_DQ25: U13.AL7 (DDR1_DQ[25]); also elsewhere on the board
DDR1_DQ26: U13.AK8 (DDR1_DQ[26]); also elsewhere on the board
DDR1_DQ27: U13.AJ8 (DDR1_DQ[27]); also elsewhere on the board
DDR1_DQ28: U13.AF8 (DDR1_DQ[28]); also elsewhere on the board
DDR1_DQ29: U13.AG8 (DDR1_DQ[29]); also elsewhere on the board
DDR1_DQ30: U13.AG7 (DDR1_DQ[30]); also elsewhere on the board
DDR1_DQ31: U13.AF7 (DDR1_DQ[31]); also elsewhere on the board
DDR1_DQS0N: U13.AJ30 (DDR1_DQS_N[0]); also elsewhere on the board
DDR1_DQS0P: U13.AK30 (DDR1_DQS_P[0]); also elsewhere on the board
DDR1_DQS1N: U13.AK27 (DDR1_DQS_N[1]); also elsewhere on the board
DDR1_DQS1P: U13.AJ27 (DDR1_DQS_P[1]); also elsewhere on the board
DDR1_DQS2N: U13.AJ10 (DDR1_DQS_N[2]); also elsewhere on the board
DDR1_DQS2P: U13.AK10 (DDR1_DQS_P[2]); also elsewhere on the board
DDR1_DQS3N: U13.AK7 (DDR1_DQS_N[3]); also elsewhere on the board
DDR1_DQS3P: U13.AJ7 (DDR1_DQS_P[3]); also elsewhere on the board
DDR1_ODT0: U13.AH24 (DDR1_ODT[0]); also elsewhere on the board
DDR1_ODT1: U13.AH23 (DDR1_ODT[1]); also elsewhere on the board
DDR1_PLL_REFOUT_N: TP9.1, U13.AF21 (DDR1_PLL_REFOUT_N)
DDR1_PLL_REFOUT_P: TP10.1, U13.AG21 (DDR1_PLL_REFOUT_P)
DDR1_PLL_TESTOUT_N: TP11.1, U13.AK24 (DDR1_PLL_TESTOUT_N)
DDR1_PLL_TESTOUT_P: TP12.1, U13.AL24 (DDR1_PLL_TESTOUT_P)
DDR1_RSTN: U13.AL23 (DDR1_RESET_N); also elsewhere on the board
GND: R89.1, R91.1; also elsewhere on the board
unnamed: R88.2, U13.C16 (DDR0_ERR_N)
unnamed: R89.2, U13.E12 (DDR0_CAL)
unnamed: R90.2, U13.AJ20 (DDR1_ERR_N)
unnamed: R91.2, U13.AG20 (DDR1_CAL)
VCC_1V1: R88.1, R90.1; also elsewhere on the board

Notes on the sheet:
VIC7100 DDR

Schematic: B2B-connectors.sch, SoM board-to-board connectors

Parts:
J3, J4: DF40C-100DP-0.4V(51); HRS_DF40C-100DP-0.4V(51); MPN DF40C-100DP-0.4V(51)
R126: R_100k_0402; 0402-res; MPN CRCW0402100KFKEDHP

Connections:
5V0_IN: J3.77, J3.79, J3.81, J3.83, J3.85, J3.87
AIN0: J3.96
AIN1: J3.94
BOOT_FROM_UARTn: J3.93; also elsewhere on the board
BT_nDis: J3.91
CAM1_D2_N: J4.33
CAM1_D2_P: J4.35
CAM1_D3_N: J4.39
CAM1_D3_P: J4.41
CDTX_DSI_CK_N: J4.69; also elsewhere on the board
CDTX_DSI_CK_P: J4.71; also elsewhere on the board
CDTX_DSI_D0_N: J4.57; also elsewhere on the board
CDTX_DSI_D0_P: J4.59; also elsewhere on the board
CDTX_DSI_D1_N: J4.63; also elsewhere on the board
CDTX_DSI_D1_P: J4.65; also elsewhere on the board
CSI0_PWDN: J3.97; also elsewhere on the board
CSI1RX_CLK_N: J4.40; also elsewhere on the board
CSI1RX_CLK_P: J4.42; also elsewhere on the board
CSI1RX_D0_N: J4.28; also elsewhere on the board
CSI1RX_D0_P: J4.30; also elsewhere on the board
CSI1RX_D1_N: J4.34; also elsewhere on the board
CSI1RX_D1_P: J4.36; also elsewhere on the board
CSI2RX_CLK_N: J4.27; also elsewhere on the board
CSI2RX_CLK_P: J4.29; also elsewhere on the board
CSI2RX_D0_N: J4.15; also elsewhere on the board
CSI2RX_D0_P: J4.17; also elsewhere on the board
CSI2RX_D1_N: J4.21; also elsewhere on the board
CSI2RX_D1_P: J4.23; also elsewhere on the board
CTL5: J3.92; also elsewhere on the board
DSI1_C_N: J4.87
DSI1_C_P: J4.89
DSI1_D0_N: J4.75
DSI1_D0_P: J4.77
DSI1_D1_N: J4.81
DSI1_D1_P: J4.83
DSI1_D2_N: J4.93
DSI1_D2_P: J4.95
DSI1_D3_N: J4.94
DSI1_D3_P: J4.96
EEPROM_nWP: J3.20
ETH0_N: J3.10; also elsewhere on the board
ETH0_P: J3.12; also elsewhere on the board
ETH1_N: J3.6; also elsewhere on the board
ETH1_P: J3.4; also elsewhere on the board
ETH2_N: J3.9; also elsewhere on the board
ETH2_P: J3.11; also elsewhere on the board
ETH3_N: J3.5; also elsewhere on the board
ETH3_P: J3.3; also elsewhere on the board
ETHLED1: J3.19
ETH_LED1: J3.17; also elsewhere on the board
ETH_LED2: J3.15; also elsewhere on the board
GLOBAL_EN: J3.99
GND: J3.1, J3.2, J3.7, J3.8, J3.13, J3.14, J3.22, J3.23, J3.32, J3.33, J3.42, J3.43, J3.52, J3.53, J3.59, J3.60, J3.65, J3.66, J3.71, J3.74, J3.98, J4.7, J4.8, J4.13, J4.14, J4.19, J4.20, J4.25, J4.26, J4.31, J4.32, J4.37, J4.38, J4.44, J4.50, J4.55, J4.56, J4.61, J4.62, J4.67, J4.68, J4.73, J4.74, J4.79, J4.80, J4.85, J4.86, J4.91, J4.92, J4.97, J4.98; also elsewhere on the board
GP43_LED: J3.21; also elsewhere on the board
GPIO0: J3.25; also elsewhere on the board
GPIO1: J3.24; also elsewhere on the board
GPIO2: J3.27; also elsewhere on the board
GPIO3: J3.26; also elsewhere on the board
GPIO4: J3.29; also elsewhere on the board
GPIO5: J3.28; also elsewhere on the board
GPIO6: J3.30; also elsewhere on the board
GPIO7: J3.31; also elsewhere on the board
GPIO8: J3.34; also elsewhere on the board
GPIO9: J3.36; also elsewhere on the board
GPIO10: J3.35; also elsewhere on the board
GPIO11: J3.37; also elsewhere on the board
GPIO12: J3.38; also elsewhere on the board
GPIO13: J3.51, R126.2; also elsewhere on the board
GPIO14: J3.55; also elsewhere on the board
GPIO15: J3.39; also elsewhere on the board
GPIO16: J3.40; also elsewhere on the board
GPIO17: J3.41; also elsewhere on the board
GPIO18: J3.44; also elsewhere on the board
GPIO19: J3.45; also elsewhere on the board
GPIO20: J3.46; also elsewhere on the board
GPIO21: J3.47; also elsewhere on the board
GPIO22: J3.48; also elsewhere on the board
GPIO44: J3.50; also elsewhere on the board
GPIO45: J3.49; also elsewhere on the board
GPIO46: J3.54; also elsewhere on the board
GPIO47: J3.56; also elsewhere on the board
GPIO48: J3.58; also elsewhere on the board
GPIO_VREF: J3.78
HDMI1_CEC: J4.49
HDMI1_CK_N: J4.66
HDMI1_CK_P: J4.64
HDMI1_D0_N: J4.60
HDMI1_D0_P: J4.58
HDMI1_D1_N: J4.54
HDMI1_D1_P: J4.52
HDMI1_D2_N: J4.48
HDMI1_D2_P: J4.46
HDMI1_HOTPLUG: J4.43
HDMI1_SCL: J4.47
HDMI1_SDA: J4.45
HDMI_CEC: J4.51; also elsewhere on the board
HDMI_DSCL: J4.100; also elsewhere on the board
HDMI_DSDA: J4.99; also elsewhere on the board
HDMI_HPD: J4.53; also elsewhere on the board
HDMI_TX0_N: J4.84; also elsewhere on the board
HDMI_TX0_P: J4.82; also elsewhere on the board
HDMI_TX1_N: J4.78; also elsewhere on the board
HDMI_TX1_P: J4.76; also elsewhere on the board
HDMI_TX2_N: J4.72; also elsewhere on the board
HDMI_TX2_P: J4.70; also elsewhere on the board
HDMI_TXC_N: J4.90; also elsewhere on the board
HDMI_TXC_P: J4.88; also elsewhere on the board
I2C2_SCL: J3.80; also elsewhere on the board
I2C2_SDA: J3.82; also elsewhere on the board
PCIE_CLK_nREQ: J4.2
PSCIE_nRST: J4.9
RESERVED: J3.76
RES_SSRX2_N: J4.6; also elsewhere on the board
RES_SSRX2_P: J4.4; also elsewhere on the board
RES_SSTX2_N: J4.12; also elsewhere on the board
RES_SSTX2_P: J4.10; also elsewhere on the board
SDIO0_CLK: J3.57; also elsewhere on the board
SDIO0_CMD: J3.62; also elsewhere on the board
SDIO0_D0: J3.63; also elsewhere on the board
SDIO0_D1: J3.67; also elsewhere on the board
SDIO0_D2: J3.69; also elsewhere on the board
SDIO0_D3: J3.61; also elsewhere on the board
SD_DAT4: J3.68
SD_DAT5: J3.64
SD_DAT6: J3.72
SD_DAT7: J3.70
SD_PWR_ON: J3.75
SD_VDD_OVRD: J3.73
SYNC_IN: J3.16
SYNC_OUT: J3.18
TV_OUT: J4.11
USBD_N: J4.3; also elsewhere on the board
USBD_P: J4.5; also elsewhere on the board
USBOTG_ID: J4.1
USB_SSRX1_N: J4.18; also elsewhere on the board
USB_SSRX1_P: J4.16; also elsewhere on the board
USB_SSTX1N: J4.24; also elsewhere on the board
USB_SSTX1P: J4.22; also elsewhere on the board
VCC_1V8: J3.88, J3.90; also elsewhere on the board
VCC_3V3: J3.84, J3.86, R126.1; also elsewhere on the board
WL_nDis: J3.89
nEXTRST: J3.100
nPWR_LED: J3.95
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

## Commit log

2021-03-18 Initial commit. Added mock design files
    [riscv-u74-som.kicad_pcb, riscv-u74-som.sch]
2021-03-19 Flipped standoffs in mock PCB
    [riscv-u74-som.kicad_pcb]
2021-04-08 Added PMIC schematic
    [power.sch]
2021-04-12 Added decoupling sheet
    [PMIC.sch, decoupling.sch, mechanical-mock.sch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]
2021-04-15 Added interfaces, ethernet, LPDDR4
    [PMIC.sch, decoupling.sch, ethernet.sch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]
2021-04-19 Added processor and B2B sheets
    [B2B-connectors.sch, PMIC.sch, VIC7100-DDR.sch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]
2021-04-20 Updated B2B connectors sheet
    [B2B-connectors.sch]
2021-04-20 Changed B2B connectors to headers
    [B2B-connectors.sch]
2021-04-21 Updated mock
    [riscv-u74-som.kicad_pcb]
2021-04-22 Connected interfaces to VIC to visualise its ball locations (wip, mock purposes)
    [B2B-connectors.sch, PMIC.sch, VIC7100-DDR.sch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]
2021-04-22 Renamed design files
    [arv-som.kicad_pcb, arv-som.sch, mechanical-mock.sch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]
2021-04-28 Updated interfaces, CPU and B2B connector connections
    [B2B-connectors.sch, PMIC.sch, VIC7100-DDR.sch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]
2021-04-28 Added logotypes
    [VIC7100-config.sch, VIC7100-power.sch, arv-som.kicad_pcb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]
2021-04-28 Minor mock update
    [arv-som.kicad_pcb]
2021-04-28 Schematic cleanup, added logotypes
    [B2B-connectors.sch, PMIC.sch, VIC7100-DDR.sch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]
2021-04-28 Removed decoupling sheet (unused)
    [decoupling.sch]
2021-04-28 Minor label fix
    [PMIC.sch]
2021-04-28 Added 3D visualisation to main schematic
    [arv-som.sch]
2021-04-28 Changes to VIC config after review
    [VIC7100-config.sch]
2021-04-28 Neatened decoupling labels
    [ethernet.sch]
2021-04-28 Updated DDR MPN
    [lpddr4.sch]
2021-04-28 Marked BT, WiFi, DAC pins as NC, added ACK LED
    [VIC7100-interfaces.sch]
2021-04-28 PMIC fixed and cleaned
    [PMIC.sch]
2021-04-28 Added I2C0 pullups, minor interfaces changes
    [VIC7100-interfaces.sch, interfaces.sch]
2021-04-28 Added SDIO CD pulldown
    [VIC7100-interfaces.sch]
2021-04-28 Added title block settings
    [PMIC.sch, VIC7100-DDR.sch, VIC7100-config.sch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]
2021-04-28 B2B updated
    [B2B-connectors.sch]
2021-04-28 PMIC restored
    [PMIC.sch]
2021-04-28 Added local libraries
    [B2B-connectors.sch, PMIC.sch, VIC7100-DDR.sch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]
2021-04-28 Update libraries
    [arv-som.kicad_pcb]
2021-04-29 Added DDR layout (wip)
    [arv-som.kicad_pcb]
2021-04-29 Update naming convention
    [B2B-connectors.sch, PMIC.sch, VIC7100-DDR.sch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]
2021-04-30 Added basic rules, removed lefover zones, imported components
    [arvsom.kicad_pcb]
2021-04-30 Updated PMIC components. PMIC component grouping
    [PMIC.sch, arvsom.kicad_pcb]
2021-04-30 Started PMIC placement
    [arvsom.kicad_pcb]
2021-05-04 Fixed power labels on ETH
    [ethernet.sch]
2021-05-04 PMIC initial placement
    [PMIC.sch, arvsom.kicad_pcb]
2021-05-04 Updated PMIC to match B0.9
    [PMIC.sch]
2021-05-04 Updated LPDDR4. Fixed reversed clocks
    [lpddr4.sch]
2021-05-05 Updated GPIO pinout to BV0.9. Remapped DSI. Mapped USB3.0
    [B2B-connectors.sch, PMIC.sch, VIC7100-DDR.sch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]
2021-05-05 Updated ethernet and interfaces.sch
    [PMIC.sch, ethernet.sch, interfaces.sch]
2021-05-05 Updated VIC config, added reset and crystals
    [B2B-connectors.sch, VIC7100-config.sch, VIC7100-interfaces.sch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]
2021-05-06 Added BOOT_FROM_UART and power LED. Changed LED transistor to smaller footprint
    [B2B-connectors.sch, VIC7100-config.sch, VIC7100-interfaces.sch]
2021-05-06 Added JTAG connector
    [VIC7100-config.sch, arvsom.kicad_pcb]
2021-05-06 Replaced 33R groups with resistor arrays
    [VIC7100-config.sch, VIC7100-interfaces.sch, arvsom.kicad_pcb]
2021-05-07 Changed VIC pad size
    [arvsom.kicad_pcb]
2021-05-10 Added UART3 testpoints
    [VIC7100-config.sch]
2021-05-10 Fixed two DDR pinout errors
    [VIC7100-DDR.sch, VIC7100-config.sch, lpddr4.sch]
2021-05-11 Corrected error in xODTx lines naming
    [lpddr4.sch]
2021-05-11 Fixed DRC errors in DDR area
    [arvsom.kicad_pcb]
2021-05-13 Grouping components for framer placement
    [arvsom.kicad_pcb]
2021-05-13 Updated component placement - PHY passives placed, moved HDMI IC, lowered VIC and DDRs
    [PMIC.sch, arvsom.kicad_pcb, ethernet.sch]
2021-05-14 Updated component placement - HDMI IC passives, QSPI, 5V8 buck placed
    [VIC7100-config.sch, VIC7100-interfaces.sch, arvsom.kicad_pcb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]
2021-05-14 Updated component placement - VIC power decoupling done
    [VIC7100-power.sch, arvsom.kicad_pcb]
2021-05-14 Updated component placement - VIC interfaces decoupling done
    [VIC7100-interfaces.sch, arvsom.kicad_pcb]
2021-05-17 Updated component placement - DDR decoupling done
    [arvsom.kicad_pcb, lpddr4.sch]
2021-05-17 Finished component placement
    [VIC7100-DDR.sch, VIC7100-config.sch, VIC7100-interfaces.sch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]
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2021-05-19 RGMII sketch, started LCD
    [VIC7100-config.sch, arvsom.kicad_pcb]
2021-05-21 Layout: RGMII, most of LCD
    [arvsom.kicad_pcb]
2021-05-21 Layout: GPIO breakout
    [arvsom.kicad_pcb]
2021-05-21 HDMI routed
    [arvsom.kicad_pcb]
2021-05-24 CSI and DSI routed
    [arvsom.kicad_pcb]
2021-05-24 PHY, GPIOs, SDIO connections done
    [arvsom.kicad_pcb]
2021-05-24 PCIe/USB routing WIP
    [arvsom.kicad_pcb]
2021-05-25 Routed USB, QSPI, JTAG
    [B2B-connectors.sch, VIC7100-config.sch, VIC7100-interfaces.sch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]
2021-05-25 Added missing vias, connected more GPIOs
    [arvsom.kicad_pcb]
2021-05-26 Placed spare decoupling capacitors under VIC
    [arvsom.kicad_pcb]
2021-05-27 Routed DDR decoupling
    [arvsom.kicad_pcb]
2021-05-31 VIC decoupling: replaced most GND vias with through-hole
    [arvsom.kicad_pcb]
2021-06-01 VIC 1V1 decoupling
    [arvsom.kicad_pcb]
2021-06-01 VIC 3V3 decoupling
    [arvsom.kicad_pcb]
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2021-06-07 Layout: 5v8 dcdc, clocks, SPIFlash, testpoints
    [PMIC.sch, VIC7100-DDR.sch, VIC7100-config.sch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]
2021-06-08 Layout: reset circuit, testpoints, cleaned JTAG, PHY
    [arvsom.kicad_pcb]
2021-06-09 Layout - power planes
    [B2B-connectors.sch]
2021-06-11 Layout - solved power islands under VIC
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2021-06-14 Caps cleared, module connnetors' GND optimized
    [VIC7100-interfaces.sch]
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2021-06-16 Replace mounting holes, add revision info to PCB
    [B2B-connectors.sch]
2021-06-16 Revision info soldermask fix
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
